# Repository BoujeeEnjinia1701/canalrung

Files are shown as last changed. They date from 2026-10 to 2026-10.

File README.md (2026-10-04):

# CanalRung

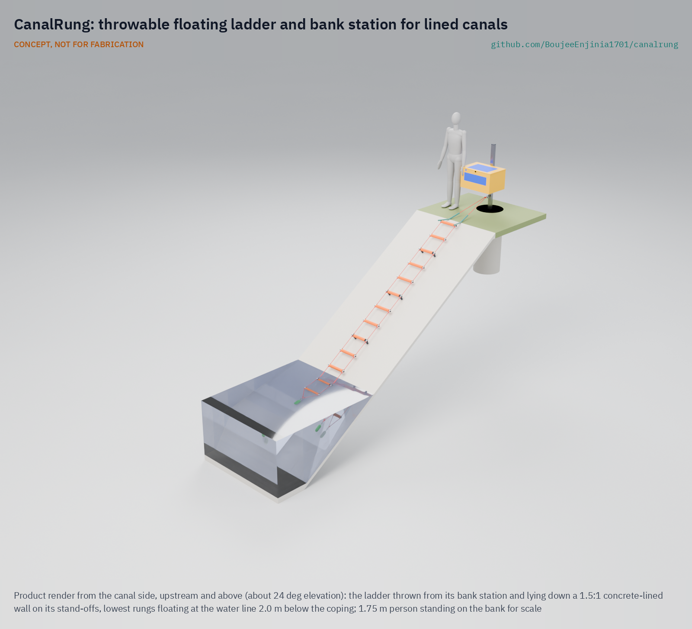
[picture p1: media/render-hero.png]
CanalRung: throwable floating ladder thrown from its bank station down a lined canal wall


     

**Area:** Situational field hardware · **TRL:** 3 of 9 (proof of concept on paper; constructable design) · **Value-engineering target:** USD 500; estimated cost USD 605.20 (USD 105.20 over the target) · **Difficulty:** 2 of 5

CONCEPT, NOT FOR FABRICATION. A research prototype design published as an open engineering reference, not certified life-saving equipment.

Gives someone in a steep canal a throwable floating ladder to climb out.

## Concept rationale

Most canal drownings are not about swimming. The water moves fast, the lined sides are steep and slick, and a person who falls in has nothing to hold. A ladder they can grab turns a steep wall into a way out. CanalRung is a ladder that a bystander can throw: rungs on rope, a weighted throw end so it drops down the wall, and a top that anchors on the bank. The person in the water grabs a rung and climbs out while the bystander stays on land.

Fixed escape ladders exist, but they are placed at intervals along the canal and may not be near the person in the water. A throwable ladder kept at farms, pump houses, schools and crossings brings the escape route to wherever someone falls in. Keeping it open and cheap, with a value-engineering target of USD 500 for a whole station, lets irrigation districts, farm groups and village committees build and place many.

## Burning platform

Drowning killed about 300,000 people in 2021, and 9 in 10 of those deaths happened in low and middle income countries ([WHO, 2024](https://www.who.int/news/item/13-12-2024-drowning-deaths-decline-globally-but-the-most-vulnerable-remain-at-risk)). Canals carry their share. The US Bureau of Reclamation counted 152 public drownings in its canals over 1964 to 1968, 40 per cent of them children under 11, and found hard-surface lined canals the most hazardous because of the difficulty in escaping from them ([USBR REC-ERC-71-36](https://www.usbr.gov/tsc/techreferences/hydraulics_lab/pubs/REC/REC-ERC-71-36.pdf)).

The pattern holds today. In Grant County, Washington, canals typically claim 1 to 4 lives a year, and the sheriff's office warns that once someone falls in, self-rescue is usually impossible because of steep concrete banks coated with dust or algae ([Columbia Basin Herald, 2026](https://columbiabasinherald.com/news/2026/jun/03/placid-in-appearance-canals-can-be-a-deathtrap/)). In Punjab, India, private divers estimate more than 100 deaths a year in the Bhakra canal alone ([The Tribune](https://www.tribuneindia.com/news/punjab/amid-no-govt-support-private-divers-recover-bodies-from-bhakhra-canal/)). Would-be rescuers are at risk too: Washington State's FACE programme describes two orchard workers who drowned in a concrete canal when one fell in and the other tried to rescue him ([Washington L&I FACE, 2002](https://stacks.cdc.gov/view/cdc/228712/cdc_228712_DS1.pdf)).

## Where it could be used

### By industry

| Industry | Use |
| --- | --- |
| Irrigation districts and water utilities | Throwable ladders at pump houses, checks, crossings and maintenance roads |
| Agriculture | Kit at farms and orchards beside canals, for workers and families |
| Schools and community groups | Stations at canal-side paths and crossings used by children |
| Fire and rescue services | Low-cost reach and climb aid carried on first-response vehicles |
| Inland waterways and ports | Throwable climb-out aid for quays and locks without fixed ladders |

### By country or region

| Country or region | Why it matters there |
| --- | --- |
| United States, western irrigation states | Grant County, Washington, sees 1 to 4 canal deaths a year and officials say self-rescue from its concrete-lined canals is usually impossible ([Columbia Basin Herald, 2026](https://columbiabasinherald.com/news/2026/jun/03/placid-in-appearance-canals-can-be-a-deathtrap/)). |
| United States, All-American Canal (California) | More than 600 people have drowned in the canal since 1942, and its eastern side is a steep concrete layer that is nearly impossible to climb out of ([KPBS, 2022](https://www.kpbs.org/news/local/2022/02/08/officials-doing-little-as-more-migrants-drown-in-imperial-county-canal)). |
| India, Punjab | Divers recovered 167 bodies from the Bhakra canal around Patiala between January 2021 and August 2022 ([The Tribune](https://www.tribuneindia.com/news/punjab/amid-no-govt-support-private-divers-recover-bodies-from-bhakhra-canal/)). |
| Pakistan, Punjab | In August 2026, 15 people drowned when a loaded rickshaw fell into the Muzaffargarh canal near Kot Adu; 11 were rescued alive ([The Nation, 2026](https://www.nation.com.pk/18-Aug-2026/three-children-s-bodies-recovered-eight-days-muzaffargarh-canal-tragedy)). |
| Low and middle income countries | Nine in ten drowning deaths happen in low and middle income countries, and the WHO African Region has the highest drowning rate ([WHO, 2024](https://www.who.int/news/item/13-12-2024-drowning-deaths-decline-globally-but-the-most-vulnerable-remain-at-risk)). |

## What sparked the idea

On 11 June 2026 in Hialeah, Florida, a 68-year-old man slipped into a canal. His friend went into the water to pull him out but could not bring him to the edge, and the current carried him to the centre of the canal, where he drowned ([WSVN, 2026](https://wsvn.com/news/local/miami-dade/2-men-drown-in-hialeah-canal-after-1-falls-in-friend-tries-to-rescue-him/)). The friend did what most people do: go in. CanalRung starts from the idea that the bystander should be able to send a way out down the bank instead.

## Problem

People who fall into lined irrigation canals often cannot climb the steep, slick sides, and bystanders who go in after them often drown too. There is rarely anything at the bank that lets the person in the water climb out on their own.

Full problem statement: [docs/01-problem.md](docs/01-problem.md)

## Concept

A bank station (a galvanised post in a concrete footing, with a forged eye nut near its foot and a bright storage box) holds a rope ladder whose top is already linked to the eye nut. A bystander lifts the lid and throws the soft-weighted bottom end upstream; 13 floating aluminium rungs on two low-stretch ropes lie down the lined wall on stand-offs, and the person in the water grabs a rung and climbs out while the bystander stays on land.

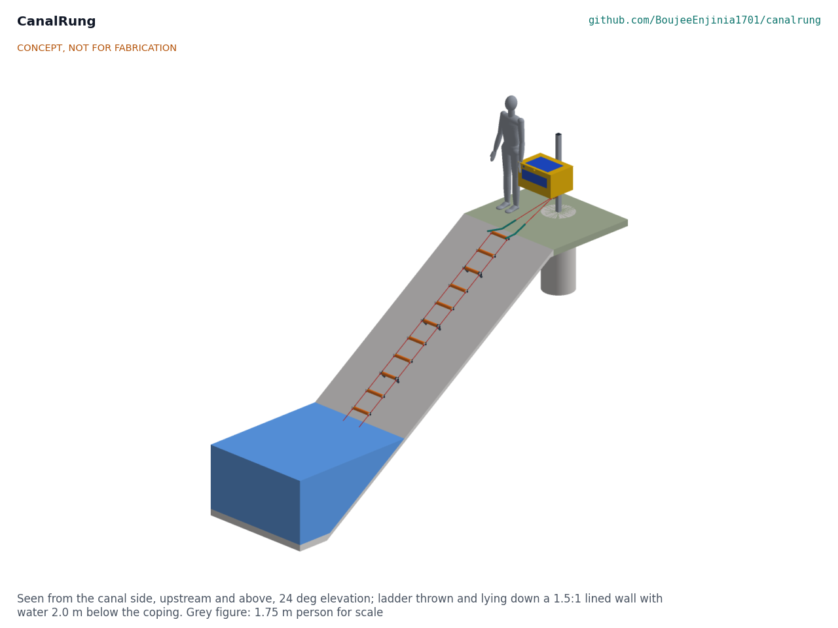
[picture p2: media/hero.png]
Concept render


Key numbers on paper (CNR-CAL-001): a 4.02 m rung section reaches the water 2.1 m down a 1.5:1 wall or 3.8 m down a vertical wall; every rung floats with 0.22 to 0.28 kg to spare; a rung under 1.5 kN reaches 0.56 of yield and the two 9 mm ropes hold 18.4 kN wet with their knots; the anchor, on a 500 x 1,200 mm footing at every site, holds 4.5 kN in drained or saturated soil. The ladder as thrown weighs 4.27 kg, inside its 4.5 kg target.

Design precis: [docs/02-concept.md](docs/02-concept.md) · Requirements: [docs/03-requirements.md](docs/03-requirements.md) · Calculations: [docs/04-calcs/01-sizing.md](docs/04-calcs/01-sizing.md) · Prototype build plan: [docs/05-build-plan.md](docs/05-build-plan.md) · Design decisions: [docs/06-design-decisions.md](docs/06-design-decisions.md) · General arrangement: [CNR-DWG-001](cad/drawings/CNR-DWG-001.pdf) · 3D viewer: [media/viewer.html](media/viewer.html)

## Key components

- Post, concrete footing, crush tube, M16 anchor bolt and forged eye nut
- Mounting plate, square U-bolts and a 70 L storage box with decals, tamper tag and rescue knife
- 13 aluminium rungs with foam float sleeves, nylon rope bushes and end caps
- HDPE wall stand-off blocks on rungs 3, 6, 9 and 12
- Two 9 mm EN 1891 type B kernmantle side ropes, a stopper knot under every rung end and a seizing over it
- Screw links, a soft 0.5 kg throw weight and edge protector sleeves

## Building the prototype

The prototype build plan ([docs/05-build-plan.md](docs/05-build-plan.md)) shows how to make each of the 23 components and put them together in 16 steps, with a making sketch for every made part and a picture for every joint and step. The station is cut and drilled steel and aluminium, a small concrete footing and a bought box; the ladder is cut and drilled aluminium tube, foam and plastic, threaded on two ropes with a knot under each rung end. It is a plan, not yet built: building and proof-loading it is TRL 4 work, and its safety stops come first.

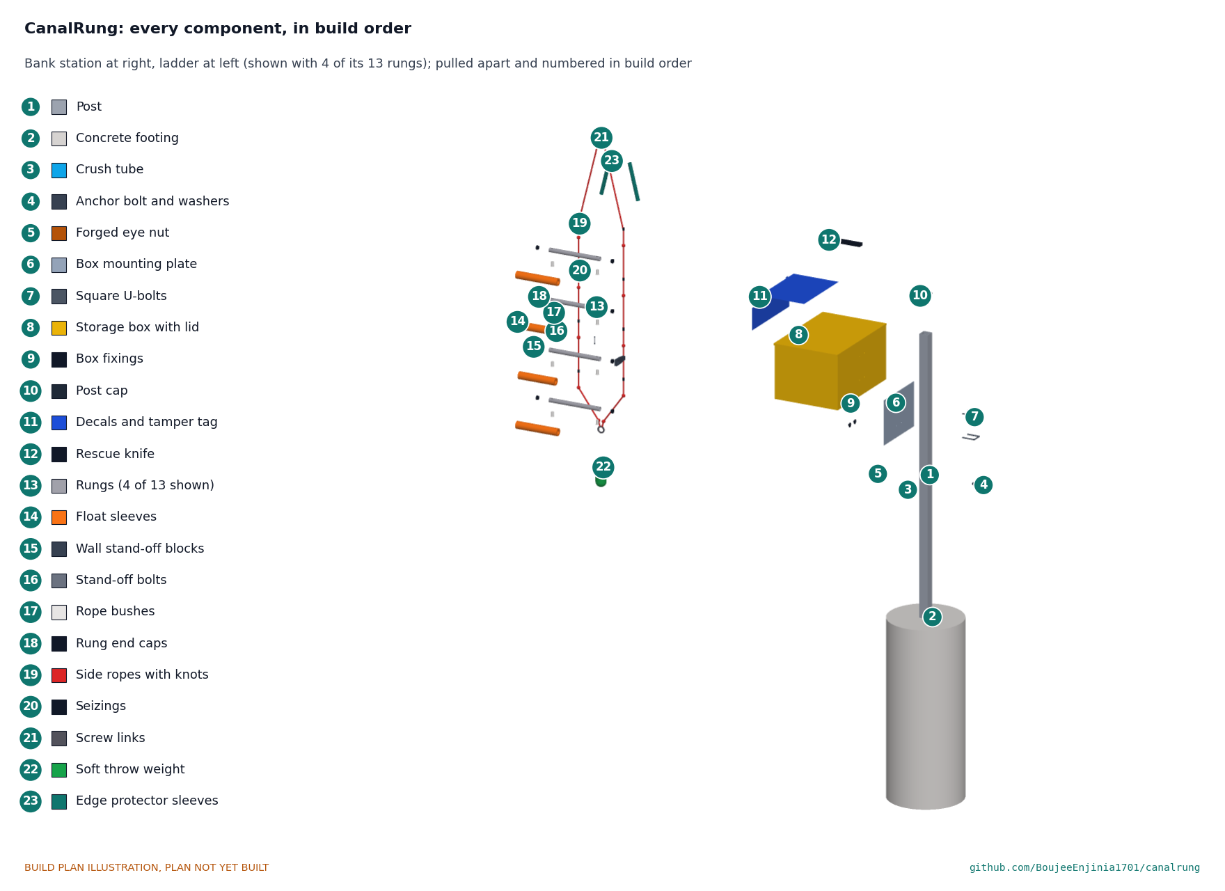
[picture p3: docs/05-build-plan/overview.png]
Every component in build order


## Safety

> Never enter the water to rescue someone. Throw, anchor and call the emergency number.
>
> Rope in moving water can trap a person; a blunt-tip rescue knife is kept in the box lid.
>
> No one climbs or tests the ladder until it has been proof-loaded (CNR-BLD-001, section 6).
>
> Safety-critical rescue and rope equipment. Published as an open engineering reference, never as certified life-saving equipment.
>
> The anchor must hold the full climbing load; a bystander holding the top by hand can be pulled in.
>
> It is not a flotation device or life jacket.
>
> Inspect ropes and rungs for UV and abrasion damage on a set schedule, and replace on any doubt.
>
> This design is published as an open engineering reference. It is not certified equipment.

## Repository layout

| Folder | Contents |
| --- | --- |
| `docs/` | Problem, concept, requirements, calculations and design decisions |
| `cad/src/` | build123d Python source, the source of truth for all geometry |
| `cad/step/`, `cad/stl/` | Exported models for FreeCAD, other CAD tools and printing |
| `cad/drawings/` | 2D sketches and dimensioned drawings |
| `bom/` | Bill of materials |
| `electronics/` | KiCad schematics and PCB layouts |
| `firmware/` | Microcontroller code |
| `media/` | Renders, perspectives and photos |
| `build-log/` | Dated prototyping notes |

## Documentation

Controlled documents follow the portfolio [documentation standard](.kit/STANDARDS.md). Each carries a document ID (CNR-PRC-001 for the precis), a version and a revision history. Branded PDFs are built with `python .kit/render.py` and attached to GitHub Releases when a document is tagged, for example `CNR-PRC-001/v1.0`.

## Credits

Designed by Amish Chadha at Design Molecule Labs. See [CONTRIBUTORS.md](CONTRIBUTORS.md) for roles. To cite this design, use [CITATION.cff](CITATION.cff) (GitHub shows it as "Cite this repository").

AI assistance (Claude) was used to accelerate prototype documentation and first-pass research. Design direction and all decisions are Amish Chadha's, recorded in this repository's decision records (`docs/decisions/`).

## Licenses

- **Hardware** (CAD, drawings, BOM, electronics): [CERN-OHL-S v2](LICENSE)
- **Software** (firmware, scripts, notebooks): [MIT](LICENSE-SOFTWARE)

A project of the [Design Molecule](https://designmolecule.com) lab.

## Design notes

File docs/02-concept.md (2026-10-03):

---
doc_id: CNR-PRC-001
title: CanalRung design precis
project: CanalRung
doc_type: Precis
version: "0.4"
status: Draft
date: '2026-10-03'
author: Amish Chadha
license: CERN-OHL-S-2.0
revisions:
- version: "0.1"
  date: '2026-09-30'
  author: Amish Chadha
  change: Initial scaffold
- version: "0.2"
  date: '2026-10-03'
  author: Amish Chadha
  change: "TRL 2: how it works, components, first-order numbers, key design choices decided under Amish's 2026-10-03 pre-approval (CNR-DDR-001), safety"
- version: "0.3"
  date: '2026-10-03'
  author: Amish Chadha
  change: "TRL 3: numbers from CNR-CAL-001; constructable design (CNR-DDR-002): rope-through-rung joint, bolted stand-offs, eye nut anchor with crush tube, box clamped by U-bolts, edge protectors, screw links"
- version: "0.4"
  date: '2026-10-03'
  author: Amish Chadha
  change: "Amish's requirement decisions of 2026-10-03 (CNR-DDR-003): 9 mm EN 1891 type B ropes; 500 x 1,200 mm footing and 2,300 mm post at every site; R2 restated to 4.5 kg"
---

# CanalRung design precis

Gives someone in a steep canal a throwable floating ladder to climb out.

## Summary

CanalRung is a bank station and a rope ladder. The station is a galvanised post set in a concrete footing beside the canal, with a forged eye nut near its foot and a bright storage box on it. The ladder lives in the box with its top already linked to the eye nut. A bystander lifts the lid, throws the soft-weighted bottom end upstream of the person in the water and lets the ladder pay out down the lined wall. Thirteen floating aluminium rungs on two low-stretch ropes lie down the wall on stand-offs, so the person can get a hand behind a rung and climb out while the bystander stays on land. On paper the design reaches the water on the design walls, every rung floats, the rungs and ropes carry a heavy climber with margin and the anchor holds 4.5 kN in drained soil. The ladder as thrown weighs 4.48 kg, over its 4.0 kg target, and the parts cost about USD 544 against a USD 500 value-engineering target.

> **Safety:** Never enter the water to rescue someone. Throw, anchor and call the emergency number. CanalRung is safety-critical rescue and rope equipment, published as an open engineering reference and never as certified life-saving equipment. It is not a flotation device or life jacket. Rope in moving water can trap a person; a blunt-tip rescue knife is kept in the box lid. The anchor must hold the full climbing load: never hold the top of the ladder by hand.

## How it works

1. **Stored ready.** The ladder sits folded in a 70 L box on the station post, rungs in three stacks with the throw weight on top. The top of the ladder is already clipped to the eye nut at the foot of the post by a screw link, and the two ropes run under the box and up into it through a notch in the front rim, so the lid closes on them.
2. **Thrown.** The bystander lifts the lid (no lock; a numbered tamper tag shows it has been used), takes the throw weight and the top of the folded ladder, and throws upstream of the person. The soft 0.5 kg weight carries the bottom end down the wall and into the water.
3. **Lying down the wall.** The ropes lift out of the notch and run from the eye nut straight to the canal edge, over the coping in two hook-and-loop edge protector sleeves, and down the wall. Rungs 3, 6, 9 and 12 carry HDPE stand-off blocks that hold the ladder 95 mm off the concrete, so there is 70 mm of hand room behind each float sleeve.
4. **Floating at the water line.** Each rung has a closed-cell foam float sleeve. The rungs that reach the water float, so the lowest rungs sit at the surface where a person can grab them, while the weight hangs 280 mm below the bottom rung and keeps that end from skating away on the current.
5. **Climbing out.** The person grabs a rung and climbs. Each rung rests on an overhand stopper knot under each end, so the climbing load goes from the rung into the knots, up the ropes, through the top link and eye nut into the post and its footing.

## Main components

*Table 1. Components, in build order; the numbers are the lines of `bom/bom.csv`.*

| # | Component | Role |
| --- | --- | --- |
| 1 | Post, galvanised 60 x 60 x 3 SHS, 2,300 long | Holds the box at a reachable height and carries the ladder anchor |
| 2 | Concrete footing, 500 dia x 1,200 deep, at every site | Holds the post against the anchor load in drained or saturated bank soil |
| 3 | Crush tube, 21.3 x 2.0, 57 long | Lets the anchor bolt be tightened without crushing the post |
| 4, 5 | M16 grade 8.8 anchor bolt and forged M16 eye nut | The ladder anchor, 250 mm above ground, loaded in line with its thread |
| 6, 7, 9 | Mounting plate, two square U-bolts, washers and nyloc nuts | Clamp the box to the post with no holes in the post |
| 8 | Storage box, 70 L, UV-stabilised, hinged lid, no lock | Keeps the ladder dry, dark and ready; drains through four holes |
| 10 to 12 | Post cap, decals and tamper tag, rescue knife | Weather, instructions ("do not enter the water"), use indicator, entanglement cutter |
| 13 | Rungs, 6061-T6 tube 28.6 x 1.65 x 360 (13) | Hand and foot holds at 335 mm pitch, 298 mm clear width |
| 14 | Float sleeves, closed-cell foam 50 OD (13) | Buoyancy and grip; high-visibility orange |
| 15, 16 | Stand-off blocks, HDPE (8), and M5 bolts | Hold the ladder 95 mm off the wall at rungs 3, 6, 9 and 12 |
| 17, 18 | Nylon rope bushes (26) and end caps (26) | Keep the rope off the aluminium hole edges; close the tube ends |
| 19, 20 | Side ropes, 9 mm EN 1891 type B (2 x 8.0 m), knots and seizings | Carry the climbing load; a knot under and a seizing over each rung end |
| 21 | Screw links, 10 mm (2) | Top: ropes to the eye nut; bottom: ropes to the throw weight |
| 22 | Soft throw weight, 0.5 kg steel shot pouch | Carries the bottom end down and into the water; cannot injure |
| 23 | Edge protector sleeves (2) | Keep the ropes off the concrete edge of the coping |

Figure 1. CanalRung thrown from its station and lying down a 1.5:1 lined wall

*Figure 1. Concept render from the constructable model, seen from the canal side.*

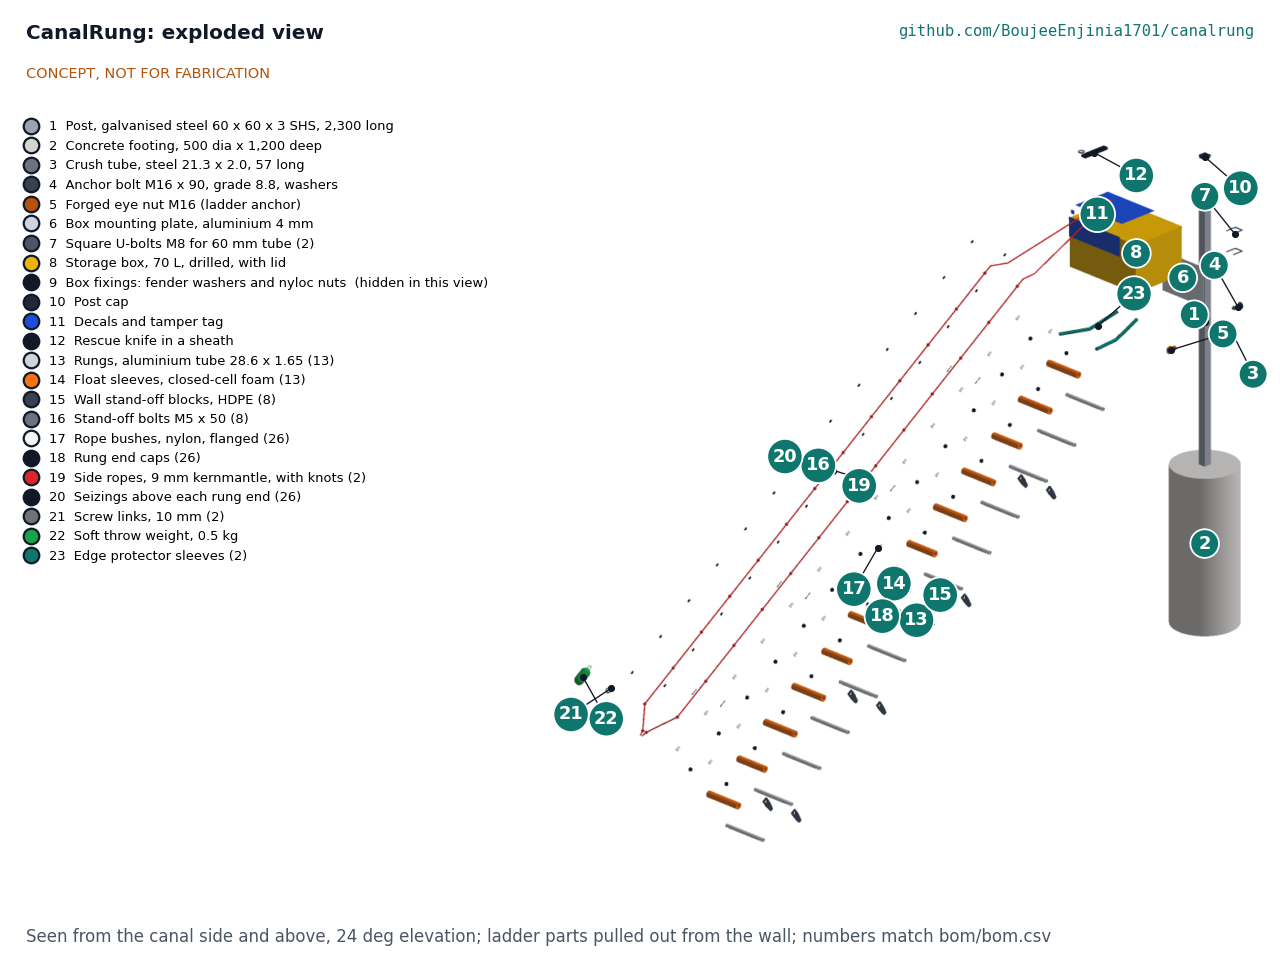
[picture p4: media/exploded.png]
Figure 2. Exploded view


*Figure 2. Exploded view; numbers match the bill of materials.*

## Numbers from the TRL 3 calculations

All figures are from CNR-CAL-001 (`docs/04-calcs/sizing.py`), with the assumptions stated there.

*Table 2. Key figures.*

| Quantity | Value | Basis |
| --- | --- | --- |
| Rung section | 4,020 mm, 13 rungs at 335 mm | [A1] |
| Reach | Two rungs in the water on a 1.5:1 slope with water 2.0 m down; works to 2.1 m on that slope and to 3.8 m on a vertical wall | [A3] to [A5] |
| Hand room and width | 70 mm behind the float sleeve at a stand-off; 298 mm clear between bushes | [A6] |
| Ladder as thrown | 4.27 kg (target 4.5 kg, restated by Amish on 2026-10-03) | [B3] |
| Spare buoyancy | 0.28 kg per plain rung, 0.22 kg per stand-off rung; bottom three rungs carry the throw weight 1.75 times over | [C1], [C2] |
| Rung stress at 1.5 kN | 135 MPa, 0.56 of the 240 MPa minimum yield | [D1] |
| Rope strength | 18.4 kN for both 9 mm ropes, wet, with stopper knots; 4.08 times the 4.5 kN target | [E1] |
| Anchor load in use | 1.47 kN for a 100 kg climber with a 1.5 dynamic factor; 2.32 kN upper bound with full current drag | [F1] to [F4] |
| Anchor elements | Eye nut 1.53 times the target; post at 0.39 of yield; standard 500 x 1,200 mm footing 3.58 times in drained soil and 1.59 in saturated soil | [G1] to [G5] |
| Deploy time | About 15 s (estimate) | [H1] |
| Cost | Value-engineering target: USD 500. Estimated cost of the constructable design: USD 605.20 (USD 105.20 over the target) | [I1] |

## Key design choices

Every choice below was decided on 2026-10-03 under Amish's pre-approval of the batch ("I pre-approve the batch runs along with any recommendations you come up with"); the full reasoning is in CNR-DDR-001 and CNR-DDR-002.

1. **A fixed station is the anchor.** The scaffold listed a ground stake, a post loop or a cross bar. A bystander cannot drive a stake that holds 4.5 kN in 30 s, so the post itself, set in concrete, carries the anchor, and the ladder top is linked to it before any emergency. A portable anchor is left for a later vehicle kit.
2. **Strong rungs over light rungs.** 28.6 x 1.65 mm 6061-T6 tube keeps the rung at 0.56 of yield; the lighter 25.4 mm tube would save 0.20 kg but reach 0.73. Safety first; the 4.0 kg mass target could not be met with these rungs, so Amish restated R2 to 4.5 kg on 2026-10-03 after the ropes were downsized to 9 mm (CNR-DDR-003).
3. **Knots carry the rungs.** Each rope runs through a nylon bush in each rung end; an overhand stopper knot under the bush carries the load and a twine seizing over it stops the rung floating up. This is the classic rope ladder joint, needs no special tools and can be inspected by eye. The 9 mm EN 1891 type B rope is tested with knotted terminations (at least 12 kN with figure-eight knots), so its knotted strength is known.
4. **Weighted and floating.** The soft weight sinks and the rungs float, which answers the scaffold's open question: the bottom end goes down and stays put while the lowest rungs sit at the surface.
5. **Stand-offs on every third rung.** Four stand-off rungs keep the taut ladder off the wall along its length at a cost of 0.42 kg; more would add mass, fewer would let it lie on the concrete between them.
6. **No throw line in the first prototype.** A second line adds tangling and an entanglement hazard for the person in the water; it can be tried after the throw trials.
7. **No lock on the box.** A tamper tag, signage and inspection instead.

## Patent design-arounds

From the preliminary patent, trademark and prior-art screen (not legal advice):

- No elastic self-stowing mechanism, to stay clear of the patented Rapid Rung swim ladder. The constructable design keeps to this: the ladder folds by hand into a box.
- Find and read the Rapid Rung patent number before public release (an action in the design decisions register, CNR-DEC-001).
- Build on expired buoyant ladder prior art such as US3411166A and US4989691A, and on the long-standing rope ladder construction (rungs on knots), which is public domain.

## Shared blocks

- CalRig proof-load rig, for the rope, rung and anchor proof loads at TRL 4 (a candidate shared block, not yet agreed).
- A boarding step for the LaneSkiff flood rescue skiff was proposed at TRL 1; it is outside this repository's scope and is recorded as a possible later use of the rung and rope joint only (CNR-DDR-001, D12).

## Safety

> **Safety:** CanalRung is safety-critical rescue and rope equipment, published as an open engineering reference and never as certified life-saving equipment. Never enter the water to rescue someone: throw, anchor and call the emergency number. The anchor must hold the full climbing load; a bystander holding the top by hand can be pulled in, which is why the top is linked to the post before any emergency. The ladder is not a flotation device or life jacket. Rope in moving water can trap a person or a limb: keep the knife in the lid and cut, do not pull, if anyone is caught. Inspect ropes, knots, seizings, bushes and the eye nut on a set schedule and after every use, and replace on any doubt. The footing must suit the soil at the site; on wet or soft banks use the larger footing. Building and testing the prototype is TRL 4 work with its own safety stops (CNR-BLD-001, section 6).

## Open decisions

None. All decisions were made under Amish's 2026-10-03 pre-approval; see the design decisions register CNR-DEC-001 (`docs/06-design-decisions.md`), which also lists the facts to confirm when parts are bought.

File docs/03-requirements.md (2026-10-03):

---
doc_id: CNR-REQ-001
title: CanalRung requirements
project: CanalRung
doc_type: Requirements
version: "0.4"
status: Draft
date: '2026-10-03'
author: Amish Chadha
license: CERN-OHL-S-2.0
revisions:
- version: "0.1"
  date: '2026-09-30'
  author: Amish Chadha
  change: Initial scaffold
- version: "0.2"
  date: '2026-10-03'
  author: Amish Chadha
  change: "TRL 2: measurable targets; R1 restated for a stated design envelope; R4 and R6 given margins; R6 restated for the fixed station anchor; R10 added (nothing thrown can hurt the person in the water); decided under Amish's 2026-10-03 pre-approval (CNR-DDR-001)"
- version: "0.3"
  date: '2026-10-03'
  author: Amish Chadha
  change: "TRL 3: status of every requirement from CNR-CAL-001 on the constructable design (CNR-DDR-002); R2 not met on mass; R9 reported against the value-engineering target"
- version: "0.4"
  date: '2026-10-03'
  author: Amish Chadha
  change: "Amish's requirement decisions of 2026-10-03 (4A and 9A, CNR-DDR-003): R2 mass target restated to 4.5 kg; R6 restated for the 500 x 1,200 mm footing as the standard at every site, in drained or saturated soil; R4 and R9 results updated for the 9 mm ropes and larger footing"
---

# CanalRung requirements

CanalRung meets nine of its ten requirements on paper or by design at TRL 3 and is over its value-engineering target on the tenth (R9). On 2026-10-03 Amish decided "1A 2A 3A 4A 5A 6A 7A 8A 9A 10A 11A": for CanalRung, 4A (smaller ropes, and R2 restated to 4.5 kg if the ladder still exceeds 4.0 kg) and 9A (the 500 x 1,200 mm footing standard at every site). Four requirements also need trials with people before they can be closed (R2 throw accuracy, R5 climb time, R7 deploy time, R8 ageing); those are TRL 4 work. Status comes from the calculation note CNR-CAL-001; the tag in brackets is the line of `docs/04-calcs/sizing.py` that carries the figure.

> **Safety:** CanalRung is safety-critical rescue and rope equipment. These requirements describe a research prototype, published as an open engineering reference and never as certified life-saving equipment. Meeting them on paper does not make the ladder safe to use; only proof loads, tank trials under lifeguard supervision and field trials can show that. Never enter the water to rescue someone: throw, anchor and call the emergency number.

## Design envelope

The first version is sized for lined canals where the water is up to 2.0 m below the coping on a 1.5:1 (horizontal to vertical) side slope, or up to 3.0 m below the coping on a vertical wall, with surface currents up to 2.0 m/s and water from 5 to 30 °C. The design case in the model is the 1.5:1 slope with the water 2.0 m below the coping. Deeper slopes need a longer ladder (a later variant, CNR-DDR-001, D1).

*Table 1. Requirements and status at TRL 3.*

| ID | Requirement | Target | Verification | Status at TRL 3 |
| --- | --- | --- | --- | --- |
| R1 | Reach the water from the bank | Rung section at least 4.0 m; at least two rungs at or below the water line on the design walls (1.5:1 slope to 2.0 m, vertical wall to 3.0 m) | Calculation [A1] to [A5]; deploy on a test wall at TRL 4 | Met on paper: 4,020 mm; two rungs in the water on the design slope and four on a 3.0 m vertical wall; works on 1.5:1 slopes to 2.1 m and vertical walls to 3.8 m |
| R2 | Throwable by one adult | Ladder as thrown (everything that leaves the box) at most 4.5 kg (9.9 lb), restated by Amish on 2026-10-03 from 4.0 kg; 8 of 10 untrained adults land the throw weight within 1 m of a target 3 m upstream | Weigh; throw trials with volunteers | Met on paper on mass: 4.27 kg [B3], 0.23 kg inside; throw accuracy needs trials |
| R3 | Rungs float at the water line | Every rung floats with at least 0.15 kg to spare, with its share of rope; the bottom three rungs carry the throw weight with a factor of at least 1.5 | Calculation [C1] to [C3]; tank test | Met on paper: 0.27 kg (plain) and 0.22 kg (stand-off) per rung; factor 1.73 |
| R4 | Carry a climbing adult | Each rung takes 1.5 kN at mid-span at no more than two thirds of yield; the two side ropes with their knots, wet, hold at least four times 4.5 kN (18 kN) | Calculation [D1], [E1]; proof-load test (TRL 4) | Met on paper: rung at 0.56 of yield; 9 mm ropes 18.4 kN, 4.08 times 4.5 kN |
| R5 | Climbable on a flat wall | Clear width at least 280 mm; rung pitch 300 to 350 mm; at least 60 mm of hand room behind the rung at the stand-offs; an adult volunteer climbs out of a 1.5 m deep test tank with a smooth vertical wall in under 60 s | Geometry [A6]; supervised tank trials with lifeguards | Geometry met by design (298 mm, 335 mm, 70 mm); climb time needs trials |
| R6 | Anchor holds | Station anchor (eye nut, bolt, post and the standard 500 x 1,200 mm footing used at every site) holds 4.5 kN with a factor of at least 1.5 on each element, in drained or saturated granular bank soil (restated by Amish on 2026-10-03) | Calculation [G1] to [G6]; pull test on site | Met on paper: eye nut 1.53; footing 3.58 drained, 1.59 saturated |
| R7 | Deploy quickly | Lid open to ladder in the water in under 30 s, using only the pictogram on the lid | Timed trials with untrained volunteers | Not verifiable at TRL 3; estimate 15 s [H1] |
| R8 | Survive outdoor storage | Ropes and rungs keep at least 80 % of strength after the equivalent of 2 years of outdoor exposure | Accelerated UV ageing and pull test | Met by design (stored in an opaque UV-stabilised box) [H2]; to confirm by test |
| R9 | Value for money | Parts cost reported against the value-engineering target of USD 500, including the post, footing and box | Costed bill of materials [I1] | Value-engineering target: USD 500. Estimated cost of the constructable design: USD 605.20 (USD 105.20 over the target) |
| R10 | Nothing thrown can hurt the person in the water | Soft throw weight; no exposed sharp edges or tube ends; a blunt-tip knife at the station to cut rope if anyone is caught | Inspection | Met by design [H3] |

## Requirements not met or at risk

- **R2 (restated, now met on mass):** with 9 mm ropes the ladder as thrown weighs 4.27 kg, still 0.27 kg over the earlier 4.0 kg, so the target was restated to 4.5 kg under Amish's fallback in decision 4A (CNR-DDR-003). The stronger rungs were kept. Whether 4.3 kg is easy to throw is a question for the TRL 4 throw trials.
- **R4 (thin margin on the ropes):** the 9 mm EN 1891 type B ropes hold 18.4 kN wet with knots, 4.08 times 4.5 kN, just over the four times R4 asks for and above Amish's floor of three times. The bought rope must declare at least 18 kN.
- **R6 (soil outside the screening values):** the standard footing holds with factors of 3.58 in drained and 1.59 in saturated granular soil. Soft clay or peat banks need a site pull test.
- **R9 (over the target):** the larger standard footing adds USD 65.00 of concrete; the estimate is USD 105.20 over the value-engineering target.

## Assumptions

- Many canal falls happen near places where a station can be placed: crossings, pump houses, paths and farms.
- A person in cold water can grip a rung long enough to climb if the rung is within reach.
- Throwing upstream and letting the current carry the ladder is easier for a bystander than throwing to the person.
- Irrigation districts would allow stations on their banks.
- The design climber is 100 kg with a dynamic factor of 1.5 (1.47 kN); the 4.5 kN anchor target is about three times that.

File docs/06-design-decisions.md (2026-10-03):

---
doc_id: CNR-DEC-001
title: CanalRung design decisions register
project: CanalRung
doc_type: Design decisions register
version: "0.2"
status: Draft
date: '2026-10-03'
author: Amish Chadha
license: CERN-OHL-S-2.0
revisions:
- version: "0.1"
  date: '2026-10-03'
  author: Amish Chadha
  change: "Register opened at TRL 3; every decision made under Amish's 2026-10-03 pre-approval"
- version: "0.2"
  date: '2026-10-03'
  author: Amish Chadha
  change: "Amish's requirement decisions 4A and 9A of 2026-10-03 recorded (CNR-DDR-003): 9 mm ropes with R2 restated to 4.5 kg; the 500 x 1,200 mm footing standard at every site"
---

# CanalRung design decisions register

Every design decision still to be made, and every decision made, in one place. Each decision is argued in full in its decision record under `docs/decisions/`; this register is the index Amish works from. The build plan (`docs/05-build-plan.md`) describes the design as it stands and does not list open decisions.

> **Safety:** CanalRung is safety-critical rescue and rope equipment. Every decision below that touches safety took the conservative option, and the decision records say what evidence would relax it. Nothing here makes the ladder safe to use without proof loads and supervised trials (TRL 4). Never enter the water to rescue someone.

## Open decisions

None. All decisions were made under Amish's 2026-10-03 pre-approval, and requirement decisions 4A and 9A were decided by Amish on 2026-10-03 (below).

## To confirm when parts are bought

| # | What to confirm | Why it matters | Source |
| --- | --- | --- | --- |
| 1 | The storage box takes a 370 mm rung across its inside depth (about 440 mm), and its back wall is flat where the plate sits | The folded ladder and the U-bolt clamp depend on it; choose a different box if not | CNR-DDR-002, P6 |
| 2 | The eye nut is forged and marked with a working load limit of at least 700 kg in line with its thread | The anchor factor of 1.53 rests on it | CNR-CAL-001, G1 |
| 3 | The screw links are marked with a working load limit of at least 1,000 kg and are long enough (about 60 mm inside) to pass round the eye nut's ring with both rope loops in | The top joint needs room for the ring and two loops | CNR-DDR-002, P7 |
| 4 | The rope is EN 1891 type B, 9 mm, with a declared breaking strength of at least 18 kN and about 55 g/m; polyester if available | The rope strength of 18.4 kN wet with knots (4.08 times 4.5 kN, R4) and the 4.27 kg ladder mass rest on it | CNR-CAL-001, E1 and B1; CNR-DDR-003 |
| 5 | The foam tube is closed-cell (a cut end takes up no water) and grips 28.6 mm tube | Buoyancy and the sleeve's fit | CNR-CAL-001, C1 |
| 6 | The nylon bushes are 12 mm bore, 16 mm outside, with a 22 mm flange, and the 9 mm rope passes freely while its overhand knot cannot pull through | The rope and knot seat | CNR-DDR-002, P1 |
| 7 | The bank soil at the first site is granular (sand or gravel), drained or saturated, and not soft clay or peat | The standard 500 x 1,200 mm footing is checked for granular soil only; clay or peat needs a site pull test | CNR-CAL-001, G4 and G5; CNR-DDR-003 |
| 8 | The Rapid Rung patent number, read before public release | Confirms the no-elastic-stowing design-around | CNR-PRC-001 |

## Value engineering

Value-engineering target: USD 500 (a hypothetical control target, not a limit). Estimated cost of the constructable design: USD 605.20 (USD 105.20 over the target). Main cost drivers and savings worth trying:

- The station costs USD 358.80 and the ladder USD 246.40. The largest lines are the concrete footing (USD 143, the 500 x 1,200 mm footing now standard at every site), the 13 aluminium rungs (USD 72.80), the post (USD 52.60), the storage box (USD 45), the ropes (USD 32) and the edge protectors (USD 30).
- Savings worth trying: ready-mix delivered for several stations at once instead of bagged premix; buying rope by the 50 m reel; a post and footing shared with an existing district marker post or fence line; sewn canvas edge protectors instead of bought ones; rungs cut from 6 m tube lengths.
- Mass: the ladder as thrown is 4.27 kg, inside the 4.5 kg of R2 as restated on 2026-10-03. Worth trying at TRL 4 if the throw trials ask for less: stand-off blocks with a lightening hole (about 0.10 kg), a 0.4 kg throw weight (0.10 kg). Lighter rungs were rejected on strength (CNR-DDR-001, D3), and ropes below 9 mm would fall under Amish's three-times floor (CNR-DDR-003).

## Decisions made

Decided by Amish under his pre-approval of 2026-10-03, except the last two rows, which he decided directly on 2026-10-03: "start with the first 14 repos from the list of 29 projects. I pre-approve the batch runs along with any recommendations you come up with. I also accept any cost overruns or variations from the assumed scope cost."

| Date | Decision | Decided by | Record |
| --- | --- | --- | --- |
| 2026-10-03 | Design envelope: water to 2.0 m below the coping on 1.5:1 slopes and to 3.0 m on vertical walls; currents to 2.0 m/s; a longer variant later | Amish, pre-approval quoted above | CNR-DDR-001, D1 |
| 2026-10-03 | The station post is the anchor: forged M16 eye nut on an M16 bolt through the post, 250 mm above ground, ladder linked in advance | Amish, pre-approval quoted above | CNR-DDR-001, D2 |
| 2026-10-03 | Rungs of 28.6 x 1.65 mm 6061-T6 tube (strength before mass) | Amish, pre-approval quoted above | CNR-DDR-001, D3 |
| 2026-10-03 | Ropes of 10.5 mm EN 1891 type A kernmantle, polyester preferred, through nylon bushes; overhand knot under and seizing over each rung end | Amish, pre-approval quoted above | CNR-DDR-001, D4 |
| 2026-10-03 | Stand-off blocks on rungs 3, 6, 9 and 12, 95 mm off the wall | Amish, pre-approval quoted above | CNR-DDR-001, D5 |
| 2026-10-03 | Soft 0.5 kg throw weight 280 mm below the bottom rung, rungs floating | Amish, pre-approval quoted above | CNR-DDR-001, D6 |
| 2026-10-03 | No throw line on the first prototype | Amish, pre-approval quoted above | CNR-DDR-001, D7 |
| 2026-10-03 | Bought 70 L UV-stabilised box clamped to the post, no lock, drain holes, rope notch, rescue knife | Amish, pre-approval quoted above | CNR-DDR-001, D8 and D11 |
| 2026-10-03 | Load standard: EN 1891 rope; rung and anchor targets of CNR-REQ-001, proof-loaded with CalRig at TRL 4; no certification claimed | Amish, pre-approval quoted above | CNR-DDR-001, D9 and D12 |
| 2026-10-03 | Keep the stronger rung and report R2 (mass) as not met | Amish, pre-approval quoted above | CNR-DDR-001, D10 |
| 2026-10-03 | First candidates to approach: Kittitas Reclamation District (co-design) and Water Safety Council of Fresno County (water safety); not contacted, not agreed | Amish, pre-approval quoted above | CNR-DDR-001, D13 |
| 2026-10-03 | Pitch, problem and the USD 500 value-engineering target unchanged; the USD 43.60 overrun accepted | Amish, pre-approval quoted above | CNR-DDR-001, D14 |
| 2026-10-03 | Design for construction: rope-through-rung joint with bushes, knots and seizings; bolted stand-off blocks; foam sleeve lengths; end caps; eye nut with crush tube; box on a plate with U-bolts; rope notch and drain holes; screw links; edge protectors; footing sizes | Amish, pre-approval quoted above | CNR-DDR-002 |
| 2026-10-03 | Saturated or soft banks get a 500 x 1,200 mm footing and a 2,300 mm post (conservative; a site pull test could relax it) | Amish, pre-approval quoted above | CNR-DDR-002, P11 |
| 2026-10-03 | Appearance model and render scenes as modelled, with no appearance deviations from the model | Amish, pre-approval quoted above | `docs/REVIEW.md` |
| 2026-10-03 | R2 (4A): side ropes downsized to 9 mm EN 1891 type B (18.4 kN wet with knots, 4.08 times 4.5 kN, above the three-times floor); stronger rungs kept; the ladder still exceeds 4.0 kg (4.27 kg), so R2 restated to 4.5 kg. Supersedes the 10.5 mm rope of D4 and the "R2 not met" of D10 | Amish, 2026-10-03: "1A 2A 3A 4A 5A 6A 7A 8A 9A 10A 11A" | CNR-DDR-003 |
| 2026-10-03 | R6 (9A): the 500 x 1,200 mm footing with a 2,300 mm post is the standard footing at every site (factor 3.58 drained, 1.59 saturated); R6 restated for drained or saturated soil. Supersedes the two footing sizes of P11 | Amish, 2026-10-03: "1A 2A 3A 4A 5A 6A 7A 8A 9A 10A 11A" | CNR-DDR-003 |

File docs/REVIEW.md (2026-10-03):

# Review note: CanalRung

## Session 2026-09-30: scaffolded

### What was done

- Repository created from kit 1.6.0 at TRL 1, target TRL 2.
- `docs/01-problem.md` (CNR-PRB-001 v0.1): problem with cited evidence, users, environment, constraints, prior work, open questions.
- `docs/02-concept.md` (CNR-PRC-001 v0.1): how it works, components, patent design-arounds, shared blocks, safety.
- `docs/03-requirements.md` (CNR-REQ-001 v0.1): 9 proposed requirements.
- `README.md` with concept rationale, burning platform, where it could be used, and what sparked the idea.

### Next

- Run `/populate` to bring the repo to a strong TRL 2 with concept media.

## Session 2026-10-03: TRL 2 (populate), kit 1.7.0

Run as the first half of `/to-trl3` under Amish's pre-approval of 2026-10-03: "start with the first 14 repos from the list of 29 projects. I pre-approve the batch runs along with any recommendations you come up with. I also accept any cost overruns or variations from the assumed scope cost."

### What was done

- Kit 1.7.0 installed (`.kit/`, `.claude/commands/`); root `CLAUDE.md` replaced by `.kit/CLAUDE.md`; `.kit/PHASE.yaml` as installed.
- CNR-PRB-001 v0.2: design envelope, open questions answered, first co-design candidates, safety section.
- CNR-REQ-001 v0.2: measurable targets; R1 restated for the design envelope, R6 for the fixed station anchor, R10 added.
- CNR-PRC-001 v0.2: how it works, components, first-order numbers, key design choices, safety.
- CNR-DDR-001 (`docs/decisions/0001-trl2-review-decisions.md`): items D1 to D14.
- Concept media from the model: `media/hero.png`, `media/exploded.png`, `media/concept-blueprint.png` and `.pdf` (CNR-DWG-010), `media/model.glb` (coarse mesh, about 4 MB) and `media/viewer.html`. No cutaway (the joints are shown cut open in the build plan) and no flow diagram (the station moves no energy or material).
- `bom/bom.csv`: every line priced.

### Results

- The concept reaches the water on the design walls, floats, and carries a heavy climber on paper; it is over its 4.0 kg mass target and its USD 500 value-engineering target (figures in the TRL 3 section below).

### Requirements not met

- R2 (mass). See the TRL 3 section.

### Decisions made under the pre-approval

D1 to D14 of CNR-DDR-001, all dated 2026-10-03 and decided by Amish under the quote above: design envelope; the station post as the anchor; 28.6 mm rungs; EN 1891 rope with knots and seizings; stand-offs on every third rung; soft weight with floating rungs; no throw line; bought box with no lock, tamper tag and knife; load standard; R2 reported as not met; candidates Kittitas Reclamation District and the Water Safety Council of Fresno County (not contacted); pitch, problem and target unchanged.

### Safety concerns

- Rescue and rope equipment: every document carries a safety section; the conservative option was taken at D2, D3, D6, D7 and D11.
- Entanglement in moving water: no throw line; a knife in the lid.

## Session 2026-10-03: TRL 3 (advance and build plan)

### What was done

- CNR-CAL-001 (`docs/04-calcs/01-sizing.md`, script `docs/04-calcs/sizing.py`, output `results.csv`): reach, mass, buoyancy, rung and rope strength, loads in use, anchor and footing, deployment, cost.
- Parametric model `cad/src/model.py` (build123d) with 245 constructability checks, all passing (`python cad/src/model.py --check`); STEP: `cad/step/canalrung-assembly.step`, `canalrung-ladder.step`, `post.step`, `mounting-plate.step`, `rung.step`, `standoff-block.step`, `crush-tube.step`; STL of the same five parts in `cad/stl/`.
- General arrangement CNR-DWG-001 Rev P2 (`cad/src/sheets.py`), at 1:50 on the design wall.
- Design made constructable (CNR-DDR-002, `docs/decisions/0002-design-for-construction.md`); `design_state: constructable`.
- Build plan pictures (`cad/src/build_plan_media.py`): overview, 9 making sketches (CNR-DWG-101 to 109), 8 joint close-ups, 16 step pictures in `docs/05-build-plan/`.
- CNR-BLD-001 (`docs/05-build-plan.md`) and CNR-DEC-001 (`docs/06-design-decisions.md`).
- Appearance model `cad/src/product_model.py` (`product_parts()`, `TITLE`, `RENDER_VIEWS` hero, exploded and detail) and render scenes exported to `/home/claude/renders/canalrung` for the photoreal renders on Amish's Mac. `media/render-hero.png`, cards and the social preview do not exist yet; the README already leads with `media/render-hero.png`.
- CNR-PRC-001 v0.3, CNR-REQ-001 v0.3, README (TRL 3, build plan section and links), `project.yaml` (trl 3, trl_target 3, evidence).

### Results

| Quantity | Value |
| --- | --- |
| Reach | 4,020 mm rung section; water to 2.1 m on a 1.5:1 wall, 3.8 m on a vertical wall |
| Ladder as thrown | 4.48 kg (target 4.0 kg) |
| Buoyancy | 0.27 kg (plain) and 0.22 kg (stand-off) spare per rung; bottom three rungs carry the weight 1.73 times |
| Rung at 1.5 kN | 0.56 of yield |
| Ropes, wet, with knots | 22.4 kN (5.0 times 4.5 kN) |
| Anchor | Eye nut 1.53, post 0.39 of yield, footing 1.92 (drained soil); saturated soil needs the 500 x 1,200 mm footing |
| Deploy time | About 15 s (estimate) |
| Cost | Value-engineering target: USD 500. Estimated cost of the constructable design: USD 543.60 (USD 43.60 over the target) |

### Requirements not met

- **R2, mass:** 4.48 kg against 4.0 kg. Kept deliberately (stronger rungs, D3 and D10); savings to try are in CNR-DEC-001.
- **R9:** over the value-engineering target by USD 43.60 (accepted under the pre-approval; `budget_usd` unchanged at 500).
- Not verifiable at TRL 3: R2 throw accuracy, R5 climb time, R7 deploy time, R8 ageing (TRL 4 trials).

### Decisions made under the pre-approval

- CNR-DDR-002, P1 to P12: rope-through-rung joint (bush, knot under, seizing over); bolted stand-off blocks; foam sleeve lengths; end caps; eye nut with a crush tube through a 21.5 mm back-wall hole; box on a plate with two U-bolts; rope notch and drain holes; screw links (sized to pass round the eye's ring); edge protectors; footing 400 x 1,000 mm, 500 x 1,200 mm on wet banks; rope cut length 8.0 m.
- Appearance model: no deviations from `model.py`; context only (bank, lining, water, mannequin, hand). Decided under the pre-approval and listed in CNR-DEC-001.
- Open decisions: none. Eight facts to confirm when parts are bought are in CNR-DEC-001.

### Build plan findings: design changes made for construction (2026-10-03)

1. Rung to rope: 16 mm holes, flanged nylon bushes, overhand knot under, seizing over (the concept had no joint).
2. Stand-off blocks: HDPE, locked by an M5 bolt through block and rung.
3. Float sleeves: two lengths (294 and 260 mm) to fit between bushes or blocks; this sets the build order (foam, blocks, bushes).
4. End caps with a short insert that clears the rope hole.
5. Anchor: forged eye nut on an M16 bolt; crush tube so the post walls do not crush; the first model's crush tube could not be fitted through the 17.5 mm bolt hole, so the back-wall hole is 21.5 mm.
6. Box: plate and U-bolts, legs through the box back wall; no holes in the post.
7. Rope notch and drain holes so the lid closes over the anchored ropes.
8. Screw links: the first model link clashed with the eye nut ring; enlarged to pass round it (6 mm clear).
9. Edge protectors on the top lead.
10. Footing sized; larger footing for saturated banks.
11. BOM renumbered in build order; parts added for each change.

### Safety concerns

- Life-critical load path (rungs, knots, ropes, links, eye nut, post, footing): proof loads with CalRig and supervised tank trials are needed before anyone climbs; the build plan's safety stops say so.
- Footing on wet canal banks: the standard footing has a factor of only 0.85 in saturated soil; the site soil must be checked.
- Entanglement: rope in moving water can trap a person; no throw line, knife in the lid.
- Working at the canal edge during installation: second person, life jacket, services located.
- Throw weight: soft pouch, thrown upstream, never at the person.

### Checks

- `python .kit/render.py` and `python .kit/render.py --check`: see the final run; the only expected warning is the missing storefront (`media/render-hero.png`, cards).
- `python .kit/drawing.py --check-text` on all sheets and the concept blueprint: no overlaps.

### Recommended next step

- Photoreal renders, cards and the social preview on Amish's Mac from `/home/claude/renders/canalrung`.
- TRL 4 (outside the current phase cap): build the prototype to CNR-BLD-001 and proof-load the rungs, ropes and anchor with CalRig before any tank trial.

## 2026-10-03: photoreal renders

Rendered with Blender Cycles on Amish's Mac from `cad/src/product_model.py`; captioned with `.kit/photo_caption.py`; `media/card.png` and `media/social-preview.png` made with `.kit/cards.py`. Views: hero, exploded, detail. image_qc passes and `render.py --check` has no FAIL.

## 2026-10-03: Amish's requirement decisions carried out

Amish chose option A on every requirement decision put to him on 2026-10-03: "1A 2A 3A 4A 5A 6A 7A 8A 9A 10A 11A". For CanalRung that is 4A (R2) and 9A (R6). Recorded in CNR-DDR-003 (`docs/decisions/0003-lighter-ropes-and-standard-footing.md`) and in the register CNR-DEC-001 v0.2.

### Changes made

- **4A, ropes (R2):** side ropes downsized from 10.5 mm EN 1891 type A to 9 mm EN 1891 type B (at least 18 kN declared, about 55 g/m); stronger rungs kept. Model `rope_d` 9.0 and knot 23 mm across; 26 new checks that the rope runs at least 1 mm clear of every bush bore. The ladder still exceeds 4.0 kg, so R2 is restated to 4.5 kg (Amish's fallback in 4A).
- **9A, footing (R6):** the 500 x 1,200 mm footing with a 2,300 mm post (1,100 mm in the concrete, bolt holes 1,350 mm from the bottom end) is the standard at every site; R6 restated for drained or saturated granular soil.
- Files: `cad/src/model.py` (271 of 271 checks pass; STEP and STL regenerated), `bom/bom.csv` (lines 1, 2 and 19 repriced; line 4's unquoted note fixed), CNR-CAL-001 v0.3 and `results.csv`, CNR-REQ-001 v0.4, CNR-PRC-001 v0.4, CNR-BLD-001 v0.2, CNR-DEC-001 v0.2, README, `project.yaml` (evidence).
- Pictures: general arrangement CNR-DWG-001 Rev P3; concept blueprint Rev P2, `media/hero.png`, `media/exploded.png`, `media/model.glb`; making sketches CNR-DWG-101 (post), 103 (footing) and 109 (rope); build plan overview, joints and steps regenerated (joint 1 and steps 1 and 2 show the new footing; rope pictures show the 9 mm rope).
- Appearance model `cad/src/product_model.py`: takes the new rope and footing from the model; exploded footing offset moved to suit the deeper footing. Render scenes re-exported to `/home/claude/renders/canalrung` (hero, exploded, detail). The photoreal renders on Amish's Mac need re-running to show the change.

### New results

| Requirement | Target | Before | After |
| --- | --- | --- | --- |
| R2, mass | At most 4.5 kg (restated from 4.0 kg) | 4.48 kg, not met | 4.27 kg, met on paper |
| R3, buoyancy | At least 0.15 kg per rung; weight factor at least 1.5 | 0.27 and 0.22 kg; 1.73 | 0.28 and 0.22 kg; 1.75 |
| R4, ropes | Wet with knots at least 4 times 4.5 kN (18 kN); Amish's floor 3 times | 22.4 kN, 5.0 times | 18.4 kN, 4.08 times |
| R6, footing | At least 1.5, drained or saturated soil | 1.92 drained, 0.85 saturated | 3.58 drained, 1.59 saturated |
| R9, cost | Reported against USD 500 | USD 543.60 | USD 605.20 |

Value-engineering target: USD 500. Estimated cost of the constructable design: USD 605.20 (USD 105.20 over the target). Footing +USD 65.00 (22 bags instead of 12 at USD 6.50), post +USD 4.60 (2.3 m pro rata), ropes save USD 8.00 (USD 2.00 a metre). Ladder as thrown 4.27 kg. `budget_usd` unchanged at 500.

### Decisions awaiting Amish

None. Nothing new needs Amish.

### Safety concerns

- The 9 mm rope meets the four-times rope factor of R4 only just (4.08). The bought rope must declare at least 18 kN, and the TRL 4 proof load must use wet, knotted rope.
- The standard footing is checked for granular soil only; soft clay or peat banks need a site pull test. About 550 kg of bagged concrete per footing is a manual handling load at the canal edge: use a second person or ready-mix.

## 2026-10-03: photoreal renders redone after Amish's requirement decisions

Rendered with Blender Cycles on Amish's Mac from `cad/src/product_model.py`; captioned with `.kit/photo_caption.py`; `media/card.png` and `media/social-preview.png` made with `.kit/cards.py`. Views: hero, exploded, detail. image_qc passes and `render.py --check` has no FAIL.

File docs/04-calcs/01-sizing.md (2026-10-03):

---
doc_id: CNR-CAL-001
title: CanalRung sizing calculations
project: CanalRung
doc_type: Calculation
version: "0.3"
status: Draft
date: '2026-10-03'
author: Amish Chadha
license: CERN-OHL-S-2.0
revisions:
- version: "0.1"
  date: '2026-10-03'
  author: Amish Chadha
  change: "First issue for TRL 3: reach, mass, buoyancy, rung and rope strength, loads in use, anchor and footing, deployment, cost"
- version: "0.2"
  date: '2026-10-03'
  author: Amish Chadha
  change: "Design for construction (CNR-DDR-002) applied: rope-through-rung joint, stand-off blocks, crush tube, rope cut length and mass, cost by build-order BOM"
- version: "0.3"
  date: '2026-10-03'
  author: Amish Chadha
  change: "Amish's requirement decisions of 2026-10-03 (4A, 9A; CNR-DDR-003): 9 mm EN 1891 type B ropes (E1, B1 to B3, C1 to C3); R2 measured against the restated 4.5 kg; the 500 x 1,200 mm footing standard at every site (G4 to G6); cost recomputed (I1, I2)"
---

# CanalRung sizing calculations

On paper the constructable CanalRung meets nine of its ten requirements and is over its value-engineering target on the tenth. The 4,020 mm rung section puts two rungs in the water on the design slope (1.5:1, water 2.0 m below the coping) and four on a 3.0 m vertical wall. Every rung floats with 0.22 to 0.28 kg to spare and the bottom three carry the soft throw weight 1.75 times over. A rung under a 1.5 kN point load reaches 0.56 of yield, and the two 9 mm ropes with their stopper knots hold 18.4 kN wet, 4.08 times the 4.5 kN target. The anchor holds 4.5 kN with factors of 1.53 (eye nut) and, for the 500 x 1,200 mm footing now standard at every site, 3.58 in drained soil and 1.59 in saturated soil. The ladder as thrown weighs 4.27 kg against the 4.5 kg target Amish restated on 2026-10-03 (R2 met on mass), and the parts cost USD 605.20 against the USD 500 value-engineering target. Every number below is printed by `docs/04-calcs/sizing.py`; the tag in brackets, for example [C2], is the line of that script's output that carries it.

> **Safety:** These are first-principles estimates for a paper proof of concept. They do not show that the ladder, its knots or the anchor are safe to use. Rope, knot, rung and anchor strengths must be proof-loaded (CalRig, TRL 4) and the climb, throw and deployment tried in a supervised test tank before any station is placed at a canal. Never enter the water to rescue someone. See CNR-PRC-001, Safety.

## Scope and method

The note checks every requirement in CNR-REQ-001 against the constructable design in `cad/src/model.py` (CNR-DDR-002). The script imports the model's parameters and builds the ladder once for part volumes, so the rungs, float sleeves, bushes and stand-off blocks used here are the ones in the STEP files and drawings. It reads `bom/bom.csv` and `budget_usd` in `project.yaml`. Run it from the repo root with `python docs/04-calcs/sizing.py`; it also writes `docs/04-calcs/results.csv`.

The design case is the station 1,000 mm back from the coping of a concrete-lined canal with a 1.5:1 (horizontal to vertical) side slope, the water 2.0 m below the coping and flowing at up to 2.0 m/s, and a 100 kg adult climbing out.

## Assumptions

*Table 1. Main assumptions.*

| Area | Assumption | Basis |
| --- | --- | --- |
| Climber | 100 kg, clothed and wet; dynamic factor 1.5 for grabbing and climbing (1.47 kN) | Screening value for a heavy adult |
| Rung | 6061-T6 drawn tube, 240 MPa minimum yield; load as a point at mid-span between the ropes (320 mm), simply supported | Conservative: hands and feet usually load nearer the ends |
| Rope | 9 mm EN 1891 type B, minimum breaking strength 18 kN, about 55 g/m; overhand stopper knot keeps 60 % (literature 55 to 65 %); wet 85 %; over a 10 mm unprotected edge 50 % | Typical published values; to be proof-loaded |
| Buoyancy | Fresh water 1,000 kg/m3; foam 33 kg/m3 closed cell; aluminium 2,700, nylon 1,140, HDPE 950, polyester 1,380 kg/m3; tube bore floods through the rope holes; rope share per rung includes 100 mm in each knot | Handbook densities |
| Current | 2.0 m/s surface current; person holding a rung, drag area 0.35 m2; rung drag coefficient 1.2 | Screening values |
| Anchor | Eye nut working load limit 700 kg in line with the thread (DIN 582 class, M16); 10 mm screw link 1,000 kg; M16 grade 8.8 proof 600 MPa on 157 mm2 | Catalogue classes; the bought parts must be marked |
| Post | S235 square hollow section 60 x 60 x 3; anchor 250 mm above ground | |
| Soil | Drained, medium dense granular bank: unit weight 18 kN/m3, friction angle 30°; saturated case 8 kN/m3 submerged | Screening values; to be confirmed on site |
| Footing | Short rigid pile in cohesionless soil (Broms), free head: ultimate lateral load 0.5 γ D L³ Kp / (e + L) | Broms (1964) |

## A. Reach and climbing geometry (R1, R5)

The rung section is 4,020 mm: 13 rungs at 335 mm pitch [A1]. On the 1.5:1 design slope (33.7°), rung 1 lies 150 mm down the wall from the coping [A2] and the bottom rung ends 2,313 mm below the coping, 313 mm below the water line, so rungs 12 and 13 are in the water and rung 11 is 59 mm above it [A3]. Because the rungs float, the ones that reach the water rise to the surface. The ladder still puts two rungs at or below the water line when the water is 2,127 mm below the coping [A4]. On a vertical wall with the water 3,000 mm down, the bottom rung is 1,170 mm under water with four rungs in it, and two rungs reach the water down to 3,835 mm [A5]. R1 is met for the stated design envelope; deeper sloped canals need the longer variant.

The clear width between the rope bushes is 298 mm, the pitch 335 mm, and at each stand-off rung the float sleeve stands 70 mm off the wall, room for a hand [A6]. R5's geometry is met by design; the climb time needs a tank trial.

## B. Mass (R2)

*Table 2. Mass of the ladder as thrown [B2].*

| Part | Mass (kg) |
| --- | --- |
| Rungs (13) | 1.715 |
| Float sleeves (13) | 0.161 |
| Rope bushes (26) | 0.091 |
| End caps (26) | 0.104 |
| Stand-off blocks (8) | 0.420 |
| Stand-off bolts (8) | 0.080 |
| Side ropes, 9 mm, 2 x 7.95 m at 55 g/m [B1] | 0.874 |
| Seizings | 0.020 |
| Screw links (2) | 0.120 |
| Throw weight with pouch | 0.530 |
| Edge protectors (2) | 0.160 |
| **Total** | **4.27** |

The ladder as thrown weighs 4.27 kg, 0.23 kg inside the 4.5 kg target of R2 [B3]. The 9 mm ropes save 0.21 kg against the 10.5 mm ropes they replace, which was not enough to reach the earlier 4.0 kg (still 0.27 kg over), so R2 was restated to 4.5 kg under Amish's fallback in decision 4A (CNR-DDR-003). **R2 is met on paper on mass**; throw accuracy needs trials. Rungs of 25.4 x 1.65 mm tube would save 0.20 kg [B4] but would take the rung past the stress limit (D2), so they were rejected.

## C. Buoyancy (R3)

A plain rung with its share of rope floats with 0.277 kg to spare and a stand-off rung with 0.221 kg, both above the 0.15 kg target [C1]. In water the throw weight weighs 0.442 kg; rungs 11, 12 and 13 together lift 0.775 kg, a factor of 1.75 against the 1.5 target [C2], so the weight hangs below the floating rungs instead of pulling them under. The whole ladder in water has 2.93 kg of spare lift [C3]. The lighter rope gives slightly more spare lift than before. **R3 is met on paper.** The tube bore is not counted: it floods through the rope holes.

## D. Rung strength (R4)

The 28.6 x 1.65 mm 6061-T6 tube has a section modulus of 890 mm3. A 1.5 kN point load at mid-span over the 320 mm between the ropes gives 120 N m and 135 MPa, 0.56 of the 240 MPa minimum yield, inside the two-thirds limit [D1]. The lighter 25.4 x 1.65 mm tube would reach 175 MPa, 0.73 of yield [D2].

Each rung end passes 750 N through the bush flange onto the knot; the nylon flange bears at about 17 MPa on a 2 mm contact band, against about 50 MPa for nylon to yield [D3]. With the whole climber on one stand-off rung on the 1.5:1 slope, each block pushes on the wall with 612 N; wall friction tries to turn the block round the rung with 17.4 N m, which puts 610 N across the M5 bolt, against about 6 kN for its two shear planes [D4].

## E. Ropes, knots and links (R4)

One 9 mm side rope with a stopper knot, wet, holds 18 x 0.6 x 0.85 = 9.18 kN; both ropes 18.4 kN, 4.08 times the 4.5 kN target [E1]. That is over the 18 kN (four times) that R4 asks for, and well over the floor of three times (13.5 kN) that Amish set for the smaller rope in decision 4A. The margin over R4 is thin, so the bought rope must carry a declared breaking strength of at least 18 kN and the proof load at TRL 4 must include knotted, wet rope. If a rope were pulled over an unprotected 10 mm coping edge as well, both ropes would still hold 9.2 kN [E2]; the edge protectors are there to keep the rope off that edge. The 10 mm screw links have a working load limit of 9.8 kN, 2.18 times the target [E3]. **R4 is met on paper.**

## F. Loads in use

The design climber with the dynamic factor loads the ladder with 1.47 kN [F1]. On the 1.5:1 slope the ropes carry only the part of that along the wall, 0.82 kN (wall friction ignored); on a vertical wall they carry all 1.47 kN [F2]. A person holding a rung in a 2.0 m/s current adds 700 N of drag, and three rungs in the water 106 N [F3]. Adding the vertical-wall climb and the full current drag together, which cannot both happen at full value, gives an upper bound of 2.32 kN on the anchor, inside the 4.5 kN target by a factor of 1.94 [F4].

## G. Anchor: eye nut, bolt, post and footing (R6)

*Table 3. Anchor elements against the 4.5 kN target.*

| Element | Capacity | Factor | Tag |
| --- | --- | --- | --- |
| Forged M16 eye nut, in line | 6.87 kN working load limit | 1.53 | [G1] |
| M16 grade 8.8 bolt | 94 kN proof load | 21 | [G2] |
| Post wall under the 50 mm washer | 66 kN punching | 15 | [G2] |
| Post, 60 x 60 x 3 at 250 mm | 91 MPa, 0.39 of yield | 2.6 | [G3] |
| Standard footing 500 x 1,200, drained soil | 16.1 kN ultimate | 3.58 | [G4] |
| Standard footing 500 x 1,200, saturated soil | 7.2 kN ultimate | 1.59 | [G5] |
| Earlier footing 400 x 1,000, saturated soil (for comparison) | 3.8 kN ultimate | 0.85 | [G5] |

Since Amish's decision 9A of 2026-10-03 the 500 x 1,200 mm footing, with a 2,300 mm post set 1,100 mm into it, is the standard footing at every site. It takes about 0.23 m3 of concrete, about 22 bags of 25 kg [G6]. **R6 is met on paper in drained and in saturated granular soil.** Soft clay or peat banks are outside these screening values and need a site pull test.

## H. Deployment, storage and safety (R7, R8, R10)

Lifting the lid (2 s), taking the throw weight and the top of the folded ladder (4 s), throwing upstream (4 s) and letting the ladder pay out (5 s) add up to about 15 s, inside the 30 s of R7; this is an estimate, and R7 can only be closed by timed trials [H1]. The ropes, rungs and foam live in an opaque UV-stabilised box and see daylight only when used or inspected, which is how R8 is met by design; an ageing test closes it [H2]. Nothing thrown is hard: the throw weight is a soft shot pouch, rung ends are capped and holes bushed, and a blunt-tip knife is kept in the lid (R10, met by design) [H3].

## I. Cost (R9)

Value-engineering target: USD 500. Estimated cost of the constructable design: USD 605.20 (USD 105.20 over the target) [I1]. The station (post, footing, anchor, box, decals, knife and consumables) is USD 358.80 and the ladder USD 246.40 [I2]. Against the previous estimate, the larger standard footing adds USD 65.00 (22 bags instead of 12 at USD 6.50), the longer post USD 4.60, and the 9 mm ropes save USD 8.00.

## Results against the requirements

*Table 4. Requirement status at TRL 3.*

| ID | Status | Figures |
| --- | --- | --- |
| R1 | Met on paper | 4,020 mm rung section; 1.5:1 slopes to 2.1 m, vertical walls to 3.8 m |
| R2 | Met on paper on mass (restated 2026-10-03); throw accuracy needs trials | 4.27 kg against 4.5 kg |
| R3 | Met on paper | 0.28 and 0.22 kg per rung; bottom three rungs 1.75 times the weight |
| R4 | Met on paper | Rung 0.56 of yield; ropes 18.4 kN wet with knots (4.08 times 4.5 kN) |
| R5 | Met by design; climb time needs trials | 298 mm clear, 335 mm pitch, 70 mm hand room |
| R6 | Met on paper in drained and saturated soil | Standard footing 3.58 drained, 1.59 saturated; eye nut 1.53 |
| R7 | Not verifiable at TRL 3 | Estimate 15 s |
| R8 | Met by design; to confirm by test | Stored in an opaque box |
| R9 | Over the value-engineering target | USD 605.20 against USD 500 |
| R10 | Met by design | Soft weight, capped ends, knife |

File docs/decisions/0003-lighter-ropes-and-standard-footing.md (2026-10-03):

---
doc_id: CNR-DDR-003
title: CanalRung lighter ropes and one standard footing
project: CanalRung
doc_type: Design decision record
version: "0.1"
status: Draft
date: '2026-10-03'
author: Amish Chadha
license: CERN-OHL-S-2.0
revisions:
- version: "0.1"
  date: '2026-10-03'
  author: Amish Chadha
  change: Decisions 4A and 9A recorded and carried into the model, calculations, bill of materials, requirements, drawings and build plan
---

# 0003: Lighter ropes and one standard footing

- **Date:** 2026-10-03
- **Status:** decided. Decided by Amish on 2026-10-03, choosing option A on every requirement decision put to him: "1A 2A 3A 4A 5A 6A 7A 8A 9A 10A 11A". This record carries decisions 4A (R2) and 9A (R6).

> **Safety:** CanalRung is safety-critical rescue and rope equipment. A smaller rope has less reserve; the 9 mm rope chosen still meets the four-times rope factor of R4, but only just, so the bought rope must declare at least 18 kN and the TRL 4 proof load must use wet, knotted rope. Never enter the water to rescue someone.

## Context

At TRL 3 (CNR-CAL-001 v0.2) the ladder as thrown weighed 4.48 kg against the 4.0 kg target of R2, and R2 was reported as not met. The 10.5 mm EN 1891 type A ropes (1.08 kg) were the second largest mass after the rungs, which were kept strong on purpose (CNR-DDR-001, D3 and D10). Separately, the standard 400 x 1,000 mm footing met R6 only in drained soil (factor 1.92) and fell to 0.85 in a saturated bank, so the larger 500 x 1,200 mm footing was kept for wet or soft banks and the soil had to be judged at each site.

## Options considered

- **4A (chosen).** Downsize the two ropes to a rope that still holds at least three times the 4.5 kN target wet with knots; keep the stronger rungs. If the thrown ladder still exceeds 4.0 kg, restate R2 to 4.5 kg.
- **4B.** Keep the 10.5 mm ropes and keep reporting R2 as not met.
- **9A (chosen).** Make the 500 x 1,200 mm footing the standard footing at every site.
- **9B.** Keep two footings and decide the size from the soil at each site.

## Decision

**Ropes (4A).** The side ropes become 9 mm low-stretch kernmantle to EN 1891 type B, polyester preferred, with a declared breaking strength of at least 18 kN and about 55 g/m. Nine millimetres is the smallest common life-safety rope with a standard minimum strength; 8 mm accessory cord (EN 564) would save another 0.2 kg but its standard minimum of about 12.8 kN gives only 2.9 times the target wet with knots, below Amish's floor of three. The cut length (8.0 m each), knots, seizings, bushes (12 mm bore), screw links and edge protectors (for 9 to 13 mm rope) are unchanged. The model's overhand knot is drawn at 23 mm across instead of 26 mm, and 26 new model checks confirm that the 9 mm rope runs at least 1 mm clear of every bush bore.

The thrown ladder still weighs more than 4.0 kg (4.27 kg), so under Amish's fallback in 4A R2 is restated to 4.5 kg (9.9 lb).

**Footing (9A).** The 500 mm diameter x 1,200 mm deep footing, with a 2,300 mm post set 1,100 mm into it, is the standard at every site. The anchor stays 250 mm above the ground, so the bolt holes move to 1,350 mm from the bottom of the post. R6 is restated for drained or saturated granular bank soil.

## Results (CNR-CAL-001 v0.3)

| Requirement | Target | Before | After |
| --- | --- | --- | --- |
| R2 | Ladder as thrown at most 4.5 kg (was 4.0 kg) | 4.48 kg, not met | 4.27 kg, met on paper [B3] |
| R3 | At least 0.15 kg spare per rung; weight factor at least 1.5 | 0.274 and 0.218 kg; 1.73 | 0.277 and 0.221 kg; 1.75 [C1], [C2] |
| R4 | Ropes wet with knots at least 4 times 4.5 kN (18 kN) | 22.4 kN, 5.0 times | 18.4 kN, 4.08 times [E1] |
| R6 | Each anchor element at least 1.5, drained or saturated soil | Footing 1.92 drained, 0.85 saturated | Footing 3.58 drained, 1.59 saturated [G4], [G5] |
| R9 | Reported against USD 500 | USD 543.60 | USD 605.20 [I1] |

The model passes 271 of 271 constructability checks (245 before, plus 26 rope-in-bush checks).

## Consequences

- Value-engineering target: USD 500. Estimated cost of the constructable design: USD 605.20 (USD 105.20 over the target). The footing grows from about 12 to about 22 bags of concrete (USD 78.00 to USD 143.00 at USD 6.50 a bag), the post from 2.1 to 2.3 m (USD 48.00 to USD 52.60, pro rata), and the ropes fall from USD 40.00 to USD 32.00 (16 m at about USD 2.00 a metre). `budget_usd` is unchanged at 500.
- The footing needs about 0.23 m3 of concrete instead of 0.12 m3: about 550 kg of bagged premix to carry to the bank, or a small ready-mix delivery. The build plan says so.
- One footing size removes the soil judgement from each install, but soft clay or peat banks are still outside the screening values and need a site pull test.
- The rope margin over R4 is thin (4.08 against 4). If the bought rope declares less than 18 kN, R4 is not met and the rope must be changed.
- Throw trials at TRL 4 will show whether 4.3 kg is easy to throw for untrained adults.

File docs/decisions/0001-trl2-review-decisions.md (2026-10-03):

---
doc_id: CNR-DDR-001
title: CanalRung TRL 2 review decisions
project: CanalRung
doc_type: Design decision record
version: "0.1"
status: Draft
date: '2026-10-03'
author: Amish Chadha
license: CERN-OHL-S-2.0
revisions:
- version: "0.1"
  date: '2026-10-03'
  author: Amish Chadha
  change: "TRL 2 review items D1 to D14, decided as recommended under Amish's 2026-10-03 pre-approval"
---

# 0001: TRL 2 review decisions

- **Date:** 2026-10-03
- **Status:** accepted. Decided by Amish under his pre-approval of 2026-10-03: "start with the first 14 repos from the list of 29 projects. I pre-approve the batch runs along with any recommendations you come up with. I also accept any cost overruns or variations from the assumed scope cost."

## Context

The scaffold (CNR-PRB-001, CNR-PRC-001 and CNR-REQ-001, all v0.1) left five open questions and several choices undecided: bank heights and flows, sink or float, the load standard, theft, the anchor type, the rung and rope construction, the throw line and the partners. Populating the concept to TRL 2 needed an answer to each. Because Amish pre-approved every recommendation for this batch, each item below is decided as recommended rather than left "Proposed, awaiting Amish". Choices that touch safety take the conservative option, and the record says what evidence would relax them. Partners and regions are named as the first candidates to approach, not as agreed.

## Options considered

*Table 1. Options for each item.*

| # | Item | Options |
| --- | --- | --- |
| D1 | Design envelope | (a) 1.5:1 slopes to 3.0 m (needs a 5.4 m ladder and about 6 kg); (b) 1.5:1 slopes to 2.0 m and vertical walls to 3.0 m with a 4.0 m ladder; (c) vertical walls only |
| D2 | Anchor | (a) ground stake driven at the time; (b) post loop around any nearby post; (c) cross bar across the bank; (d) the station post itself, set in concrete, with the ladder linked to it in advance |
| D3 | Rung | (a) 25.4 x 1.65 mm aluminium tube (lighter); (b) 28.6 x 1.65 mm aluminium tube (stronger); (c) solid HDPE rod (floats but about 6 kg for the set); (d) GFRP tube |
| D4 | Rope and joint | (a) 10.5 mm EN 1891 type A kernmantle through the rung ends, overhand stopper knot under and seizing over each end; (b) polypropylene rope with clamps; (c) laid rope with rungs seized between the strands (Jacob's ladder) |
| D5 | Wall stand-offs | (a) on every rung (about 1.3 kg); (b) on every third rung (0.42 kg); (c) none |
| D6 | Bottom end | (a) weighted to sink; (b) floating; (c) a soft weight on a short tail with floating rungs above it |
| D7 | Throw line | (a) fitted; (b) left out of the first prototype |
| D8 | Storage | (a) a bought UV-stabilised 70 L box on the post, no lock; (b) a made steel cabinet; (c) a locked box |
| D9 | Load standard | (a) certify to a ladder or life-saving standard now; (b) rope to EN 1891 type A, rung and anchor targets as in CNR-REQ-001, proof-loaded at TRL 4, no certification claimed |
| D10 | R2 mass target | (a) meet 4.0 kg with lighter rungs and fewer stand-offs; (b) keep the safer rung and report R2 as not met |
| D11 | Theft | (a) lock; (b) no lock, tamper tag and inspection; (c) no rope or aluminium (not possible) |
| D12 | Shared blocks | CalRig for proof loads; LaneSkiff boarding step |
| D13 | Co-design partner | Western US irrigation districts; Punjab canal authorities; water-safety councils |
| D14 | Pitch, problem and value-engineering target | Change or keep |

## Decision

*Table 2. Items decided, 2026-10-03.*

| # | Decision | Why | What would relax it |
| --- | --- | --- | --- |
| D1 | (b): water to 2.0 m below the coping on 1.5:1 slopes and to 3.0 m on vertical walls; currents to 2.0 m/s | Keeps the ladder near the 4 kg throwing target; covers the vertical-walled and steep reaches where self-rescue is hardest. A 6 m variant for deeper sloped canals is a later option | Partner district data on its reaches |
| D2 | (d): the post is the anchor; forged M16 eye nut on an M16 bolt through the post, 250 mm above ground, ladder linked in advance | A bystander cannot set a 4.5 kN stake in 30 s; a hand-held top pulls people in. The conservative option | A tested portable anchor for a vehicle kit |
| D3 | (b): 28.6 x 1.65 mm 6061-T6, 360 mm long | 0.56 of yield at 1.5 kN against 0.73 for the lighter tube. Safety before mass | Proof-load results showing the lighter tube keeps a two-thirds margin |
| D4 | (a): EN 1891 type A 10.5 mm, polyester preferred; nylon bushes in the rung holes; overhand knot under, seizing over | Rated rope with known knotted strength; a joint anyone can tie and inspect; polypropylene is weak and degrades in sun | |
| D5 | (b): rungs 3, 6, 9 and 12, 95 mm from rung axis to wall | Hand room on a flat wall at a third of the mass of (a) | Tank trials showing climbers manage with fewer |
| D6 | (c): soft 0.5 kg steel shot pouch, 280 mm below the bottom rung, rungs floating | The end goes down and stays put; the rungs stay at the surface; nothing hard is thrown near the person | Throw trials |
| D7 | (b): no throw line on the first prototype | A second line can tangle and is an entanglement hazard in moving water. Conservative | Throw trials showing a line is needed to steer the ladder |
| D8 | (a): bought bright 70 L UV-stabilised box clamped to the post, drain holes, rope notch, blunt-tip knife under the lid | Cheap, replaceable, visible; keeps the rope dark | |
| D9 | (b) | Certification is beyond TRL 3; the targets give margins over the design climber and will be proof-loaded with CalRig | |
| D10 | (b): keep the D3 rung; R2 reported as not met (4.48 kg against 4.0 kg) | The rung margin protects the climber; 0.5 kg more may not matter to a thrower. Savings to try are in the register | Throw trials with the 4.5 kg ladder |
| D11 | (b): no lock; numbered tamper tag on the latch; the partner district inspects on a set schedule and after each use | A locked rescue box fails when it is needed | Theft data from a pilot |
| D12 | CalRig named as the proof-load rig for TRL 4 (candidate shared block); the LaneSkiff boarding step stays outside this repository | Keeps this repository to one product | |
| D13 | First candidates to approach: the Kittitas Reclamation District (Washington) as co-design partner and the Water Safety Council of Fresno County as water-safety partner; neither contacted | Both publish canal safety guidance cited in CNR-PRB-001 | |
| D14 | No change: pitch and problem as scaffolded; `budget_usd` stays 500 as the value-engineering target | Cost overruns are accepted under the pre-approval and reported, not used to change the target | |

## Consequences

- CNR-PRB-001, CNR-PRC-001 and CNR-REQ-001 are revised. R1 is restated for the D1 envelope, R6 for the fixed station anchor of D2, and R10 is added for D6 and D8.
- The design is modelled in `cad/src/model.py` on these decisions and then made constructable in CNR-DDR-002.
- `project.yaml`: only the TRL fields, `design_state` and the evidence list change; `budget_usd`, the pitch and the problem are unchanged.
- Nothing in this record authorizes building or testing. TRL 4 is outside the current portfolio phase.

> **Safety:** Every choice above that touches safety (D2, D3, D6, D7, D11) took the more conservative option. None of them makes the ladder safe without proof loads and supervised trials.

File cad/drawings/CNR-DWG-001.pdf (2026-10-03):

PRELIMINARY, NOT FOR FABRICATION | CanalRung · github.com/BoujeeEnjinia1701/canalrung

FRONT VIEW
Scale 1:50; looking at the front (along +Y)

TOP VIEW
Scale 1:50; looking down (along -Z)

RIGHT VIEW
Scale 1:50; looking at the right side (along -X)

6600

900 4308

1,000 coping to post

1,200 1,200

2,000

DESIGN WATER LINE

1.5:1 LINED WALL (SITE)

EYE NUT (5), 250 ABOVE GROUND

13 RUNGS AT 335 PITCH (13)

FOOTING 500 DIA (2)

ISOMETRIC VIEW
Not to scale; seen from the bank side, front right and above; grey wall is the site

MAIN DIMENSIONS AND INTERFACES (MM)
Post 60 x 60 x 3 SHS x 2,300; 1,100 in a 500 x 1,200 footing
Post centre 1,000 back from the coping; top 1,200 above ground Anchor: M16 forged eye nut on an M16 x 90 bolt, 250 above ground Box about 450 x 650 x 360, base 450 up; 2 square U-bolts M8 Ladder: 13 rungs, 335 pitch, ropes 320 apart; section 4,020
Rung 28.6 x 1.65 Al tube x 360; foam float sleeve 50 OD Stand-offs on rungs 3, 6, 9, 12: rung axis 95 off the wall
Ropes 9 kernmantle, about 8.0 m each; knot under every rung end Ladder as thrown about 4.3 kg; soft 0.5 kg throw weight
Small parts (bushes, caps, knots, seizings): DWG-106, 109 Third-angle; front view from -Y; canal along Y; (n) = BOM line
REV | DESCRIPTION | DATE | BY
P1 | Preliminary GA for TRL 3 (from cad/src/model.py) | 2026-10-03 | AC
P2 | CNR-DDR-002: design for construction | 2026-10-03 | AC
P3 | CNR-DDR-003: 9 mm ropes; 500 x 1,200 footing standard | 2026-10-03 | AC
CANALRUNG | github.com/BoujeeEnjinia1701/canalrung

## Throwable canal ladder and bank station: general arrangement

DRAWING NO.
CNR-DWG-001

REV
P3

SHEET
1 of 1

SIZE

## ANSI B

SCALE
1:50

UNITS
mm
PROJECTION | DATE
2026-10-03

DRAWN
Amish Chadha

MATERIAL / NOTES
Steel post, aluminium rungs, kernmantle rope; see bom/bom.csv. PRELIMINARY, NOT FOR FABRICATION
Licensed CERN-OHL-S-2.0 · Design Molecule Lab · designmolecule.com | Generated from cad/src; do not edit by hand

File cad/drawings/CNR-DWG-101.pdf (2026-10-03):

### BUILD PLAN SKETCH, PLAN NOT YET BUILT CanalRung · github.com/BoujeeEnjinia1701/canalrung

FRONT VIEW
Scale 1:20; looking at the front (along +Y)

TOP VIEW
Scale 1:20; looking down (along -Z)

RIGHT VIEW
Scale 1:20; looking at the right side (along -X)

60

60 2300

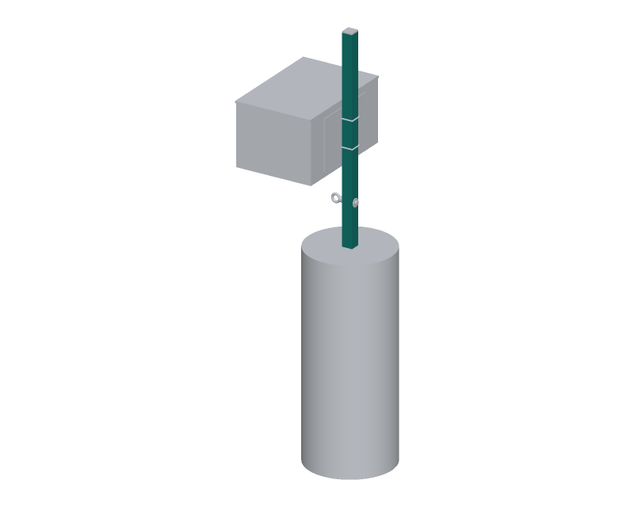
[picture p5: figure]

WHERE IT GOES
This part in colour, its neighbours in grey

HOW TO MAKE IT AND HOW IT FITS
Cut 2,300 long, square; file the burr off both ends.
Mark one face as the canal side. 1,350 up from the bottom end (250 above ground when set), on the face centre line: canal-side wall: drill 17.5 for the M16 bolt;
back wall, same axis: drill 21.5 for the crush tube.
Use a drill guide or drill press so both holes share one axis. Deburr; cold galvanising paint on the holes and cut ends. Mark a ground line 1,100 up from the bottom end.
Fits: 1,100 sits in the footing, 100 above its base;
plate and box on the canal face; cap on top.
REV | DESCRIPTION | DATE | BY
P1 | Making sketch for the prototype build plan | 2026-10-03 | AC
CANALRUNG | github.com/BoujeeEnjinia1701/canalrung

## Post: making sketch

DRAWING NO.
CNR-DWG-101

REV
P1

SHEET
1 of 1

SIZE

## ANSI B

SCALE
1:20

UNITS
mm
PROJECTION | DATE
2026-10-03

DRAWN
Amish Chadha

MATERIAL / NOTES
Hot-dip galvanised steel 60 x 60 x 3 SHS, S235 or better
Licensed CERN-OHL-S-2.0 · Design Molecule Lab · designmolecule.com | Generated from cad/src; do not edit by hand

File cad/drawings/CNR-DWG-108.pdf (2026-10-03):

### BUILD PLAN SKETCH, PLAN NOT YET BUILT CanalRung · github.com/BoujeeEnjinia1701/canalrung

FRONT VIEW
Scale 1:2; looking at the front (along +Y)

TOP VIEW
Scale 1:2; looking down (along -Z)

RIGHT VIEW
Scale 1:2; looking at the right side (along -X)

16

115 40

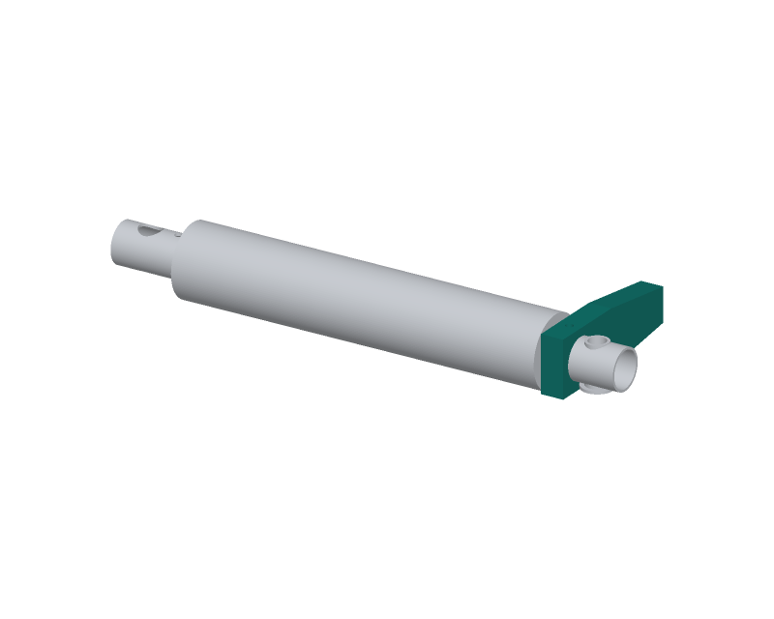
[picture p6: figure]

WHERE IT GOES
This part in colour, its neighbours in grey

HOW TO MAKE IT AND HOW IT FITS
Mark the outline from this sketch: 115 long, 40 tall at the rung end, tapering to a 24 tall nose over the last 60. Saw and file; round the nose corners 4 so it slides
on concrete.
28.8 hole for the rung, centre 20 from the back end and on the height centre line (step drill or hole saw). 5.3 hole straight down through the middle of the 16 thickness, crossing the rung hole.
Fits: on the rung just inside the bush, nose toward the wall, held by one M5 x 50 bolt through block and rung.
REV | DESCRIPTION | DATE | BY
P1 | Making sketch for the prototype build plan | 2026-10-03 | AC
CANALRUNG | github.com/BoujeeEnjinia1701/canalrung

## Wall stand-off block: making sketch (make 8)

DRAWING NO.
CNR-DWG-108

REV
P1

SHEET
1 of 1

SIZE

## ANSI B

SCALE
1:2

UNITS
mm
PROJECTION | DATE
2026-10-03

DRAWN
Amish Chadha

MATERIAL / NOTES
HDPE sheet 16 mm, UV-stabilised
Licensed CERN-OHL-S-2.0 · Design Molecule Lab · designmolecule.com | Generated from cad/src; do not edit by hand

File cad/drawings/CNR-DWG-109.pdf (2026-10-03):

### BUILD PLAN SKETCH, PLAN NOT YET BUILT CanalRung · github.com/BoujeeEnjinia1701/canalrung

FRONT VIEW
Scale 1:50; looking at the front (along +Y)

TOP VIEW
Scale 1:50; looking down (along -Z)

RIGHT VIEW
Scale 1:50; looking at the right side (along -X)

89

23 5625

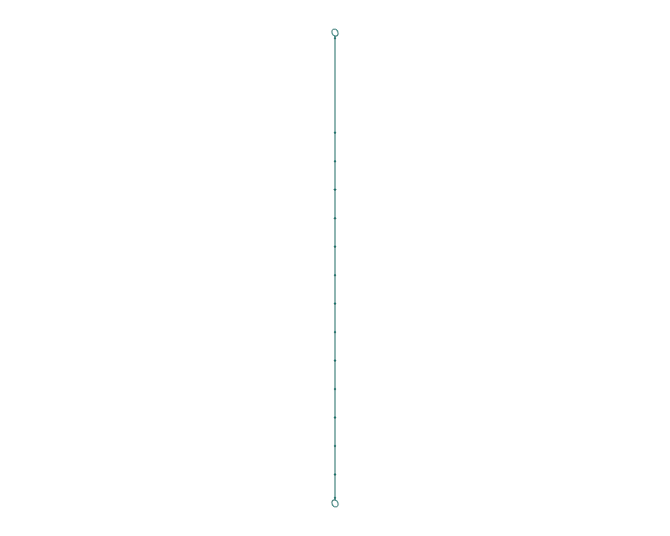
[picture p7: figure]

WHERE IT GOES
This part in colour, its neighbours in grey

HOW TO MAKE IT AND HOW IT FITS
Cut 7.9 m; tape, cut and heat seal both ends.
Top loop: figure-eight on a bight with a 60 tail, loop about 80 long (fits the 10 mm screw link).
From the loop's knot measure 1,106 down: mark rung 1. Then mark every 335 for rungs 2 to 13 (12 more marks). Mark both ropes side by side so the marks match.
At each mark: overhand stopper knot, its top at the mark, tied when the rung is threaded (build step 11).
Below rung 13: 280 to a figure-eight loop for the bottom link. Dress and set every knot by hand before loading.
REV | DESCRIPTION | DATE | BY
P1 | Making sketch for the prototype build plan | 2026-10-03 | AC
CANALRUNG | github.com/BoujeeEnjinia1701/canalrung

## Side rope: making sketch (make 2)

DRAWING NO.
CNR-DWG-109

REV
P1

SHEET
1 of 1

SIZE

## ANSI B

SCALE
1:50

UNITS
mm
PROJECTION | DATE
2026-10-03

DRAWN
Amish Chadha

MATERIAL / NOTES
9 mm EN 1891 type B low-stretch kernmantle, polyester preferred
Licensed CERN-OHL-S-2.0 · Design Molecule Lab · designmolecule.com | Generated from cad/src; do not edit by hand

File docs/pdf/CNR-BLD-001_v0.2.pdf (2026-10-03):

C A N A L R U N G · B U I L D P L A N

# CanalRung prototype build plan

Design Molecule Lab · designmolecule.com

D O C U M E N T CO N T RO L

Document ID | CNR-BLD-001 | Version | 0.2
Status | Draft | Date | 2026-10-03
Author | Amish Chadha | License | CERN-OHL-S-2.0
Project TRL | TRL 3 | Proof of concept
Repository | github.com/BoujeeEnjinia1701/canalrung
Source | docs/05-build-plan.md @ uncommitted

R EV I S I O N H I STO RY

Version | Date | Author | Change
0.2 | 2026-10-03 | Amish Chadha | Amish's decisions of 2026-10-03 (CNR-DDR-003): 9 mm ropes; the 500 x 1,200 footing and 2,300 post at every site
0.1 | 2026-10-03 | Amish Chadha | First build plan; design made constructable (CNR-DDR-002)

D R A F T · N O T F O R F A B R I C A T I O N

## CanalRung prototype build plan

Plan, not yet built. How to build the first proof-of-concept prototype, component by component. Building and testing to it is TRL 4 work. Decisions still to be made are kept in the design decisions register (docs/06-design-decisions.md), not here.

### 1. What you are building


Figure 1. Every component pulled apart and numbered in build order. The ladder is drawn with 4 of its 13 rungs so the parts stay readable.
The prototype is one CanalRung station and its ladder. The station is a galvanised steel post set in a concrete footing a metre back from the canal edge, with a forged eye nut near its foot that anchors the ladder and a bright plastic box clamped to it that holds the ladder. The ladder is 13 aluminium tube rungs, each in an orange foam float sleeve, hung on two red climbing-grade ropes by a knot under each rung end, with plastic stand-off blocks on four rungs, a soft weight at the bottom and a screw link at each end. Figure 1 shows the 23 components in the order you make or fit them. Nine are made in a small workshop or on site: the post, the footing, the crush tube, the mounting plate, the drilled box, the rungs, the float sleeves, the stand-off blocks and the ropes. The rest are bought and fitted. The work is cutting and drilling steel and aluminium tube, cutting aluminium sheet, plastic and foam, digging and pouring a small footing, and rope work: cutting, sealing, tying knots and seizing. The parts cost about USD 605, from the bill of materials.

Safety: CanalRung is rescue and rope equipment that a person's life will depend on. Build it carefully, inspect every knot, and never let anyone climb it, stand on it or test it in water until section 6 says so. Work at the
canal edge only with a second person watching and a life jacket on; dig only after underground services have been located. Cut tube and sheet edges are sharp: deburr everything and wear gloves. Heat sealing rope ends gives off fumes; do it in a ventilated space.

### 2. What changed to make it buildable

The concept showed what CanalRung does; some of its parts could not be made or fixed as drawn. Each change below keeps what the ladder does, and all are recorded in decision record CNR-DDR-002.
Table 1. Changes from the concept.
Component The concept had | The buildable design has | Why

Rung to
rope

Rungs "fixed at even
spacing", no joint

The rope runs through a bushed hole in each rung end; a knot under the rung carries it and a seizing over it stops it floating up (Figure 11)

The classic rope ladder joint, made with hand tools and
checked by eye

Wall
spacers

Spacers on some
rungs, no fixing

Plastic blocks on rungs 3, 6, 9 and 12, each locked by one M5 bolt through block and rung (Figure 15)

They cannot slide or turn

Floats | "Buoyant rungs" | A closed-cell foam sleeve on every rung, cut to fit between the bushes or blocks (Figure 13) | Known buoyancy; the sleeve length is set by the parts beside it
Tube ends | Open | Plastic end caps that stop short of the rope hole | No sharp or open ends
Anchor | Stake, post loop or cross bar | Forged eye nut on a bolt through the post, with a crush tube inside (Figure 6) | A fixed anchor that holds 4.5 kN; the post walls do not crush
Box | On the post, no fixing An aluminium plate and two U-bolts round the post;
| | the U-bolt legs pass through the box back (Figure 9) | No holes in the post for the box
Rope ends | No termination | A loop at each end, held in rated screw links at the eye nut and at the throw weight (Figures 17 and 18) | Rated, replaceable connections
Canal edge | Ropes on the concrete edge | Two sleeves on the ropes where they cross the edge (Figure 19) | Rope over a sharp edge loses strength
Box lid | Could not close over the anchored ropes | A notch in the front rim and four drain holes (Figure 8) | The ladder stays linked to the anchor while stored
Footing | No size | 500 mm across and 1,200 mm deep at every site, wet or dry (Figure 4) | Holds the anchor load in wet or dry bank soil, so one size fits every site

### 3. Making the components

Make and check each component before the assembly step that needs it. Sizes are in millimetres. On the station, "canal side" is the face of the post toward the water and "back" the face away from it. On the ladder, "up" is toward rung 1, the top rung, and "wall side" is the side the stand-off blocks point to. Workshop tolerance is 1 mm unless a step says otherwise; drawings do not carry tolerances before TRL 4.

### 3.1 Post

Figure 2. Post making sketch (CNR-DWG-101).
What it is and what it is made from. The upright that holds the box and carries the ladder anchor. Hot-dip galvanised square steel tube 60 x 60 x 3 mm, grade S235 or better, 2,300 long.
How to make it.
Cut the tube to 2,300, square, and file the burr off both ends.
Choose one face as the canal side and mark it along its length.
Measure 1,350 up from the bottom end and mark the centre of the canal-side face and of the back face at that height. This puts the anchor 250 above the ground.
Clamp the post in a drill press or use a drill guide so both holes share one axis square to the faces. Drill a 6 pilot right through both walls.
Open the hole in the canal-side wall to 17.5 (for the bolt) and the hole in the back wall to 21.5 (for the crush tube).
Deburr both holes inside and out. Paint the holes and both cut ends with cold galvanising paint.

1.
2.
3.

4.

5.

6.

Mark a ground line all round, 1,100 up from the bottom end.

How it fits the parts next to it. The bottom 1,100 sits in the concrete footing with 100 of concrete under it (Figure 4). The crush tube goes in through the back hole and the anchor bolt through both (Figure 6). The mounting plate sits flat on the canal-side face with its bottom edge 480 above the ground line, held by two U-bolts round the back of the post (Figure 9). The cap closes the top.
Check before moving on. Push a 16 rod through both holes: it must pass straight through without forcing. The 21.3 crush tube must slide into the back hole.

### 3.2 Concrete footing

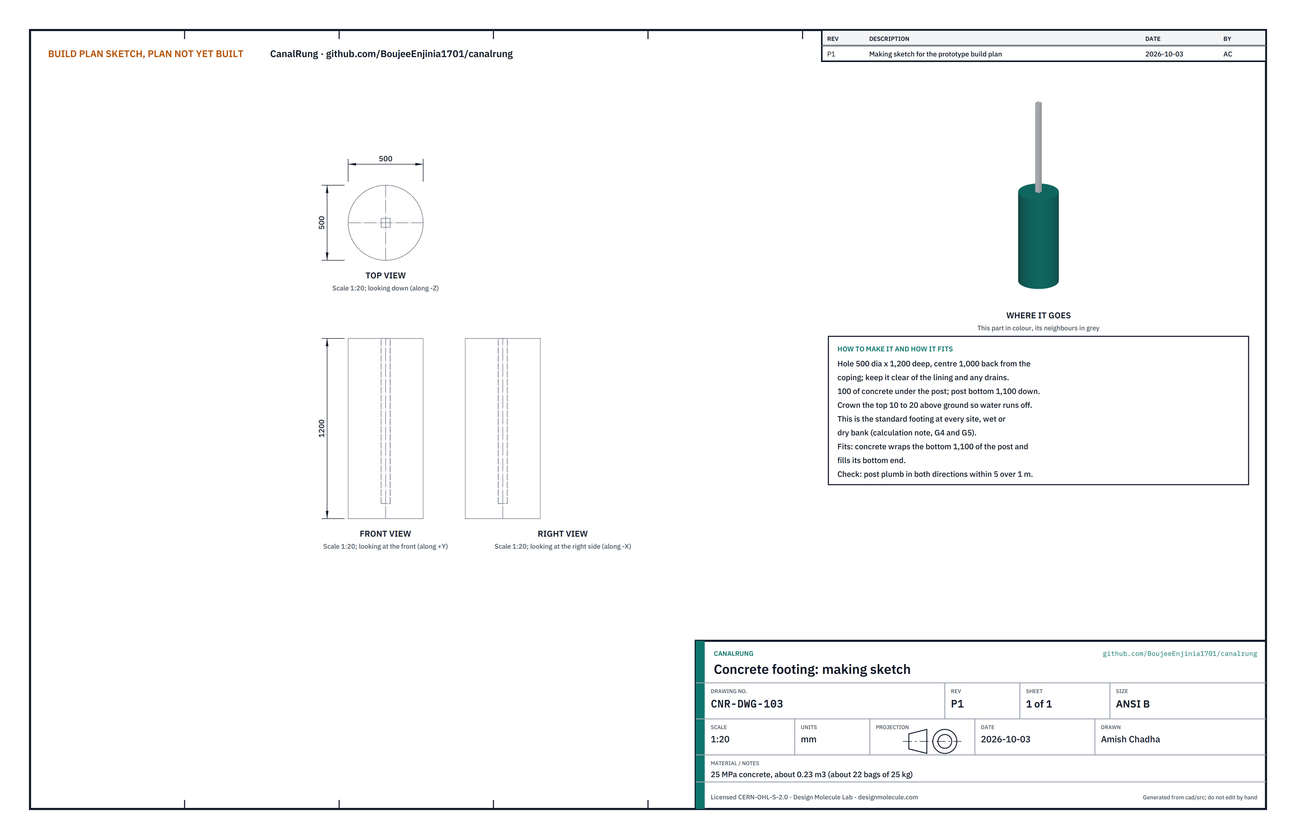
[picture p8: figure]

Figure 3. Footing making sketch (CNR-DWG-103).
What it is and what it is made from. The concrete that holds the post in the bank against the pull of a climber. About 0.23 m3 of 25 MPa concrete, about 22 bags of 25 kg premix, in a hole 500 across and 1,200 deep. This one size is used at every site, whether the bank is dry or wet.
How to make it.
Choose the spot with the canal operator: 1,000 from the canal edge to the post centre, on level bank, clear of the lining's joints, drains and any buried services (have them located first).
Dig or auger the hole 500 across and 1,200 deep, with straight sides. Keep the spoil away from the canal edge. Pour 100 of concrete into the bottom and level it.
Stand the post on it (assembly step 1), plumb it both ways with a spirit level and brace it.

7.

1.

2.
3.
4.

Fill the hole in layers of about 200, rodding each layer to drive out air, up to 10 to 20 above the ground, and slope the top away from the post so water runs off.
Keep the concrete damp and leave it 7 days before any load goes on the eye nut.

How it fits the parts next to it.

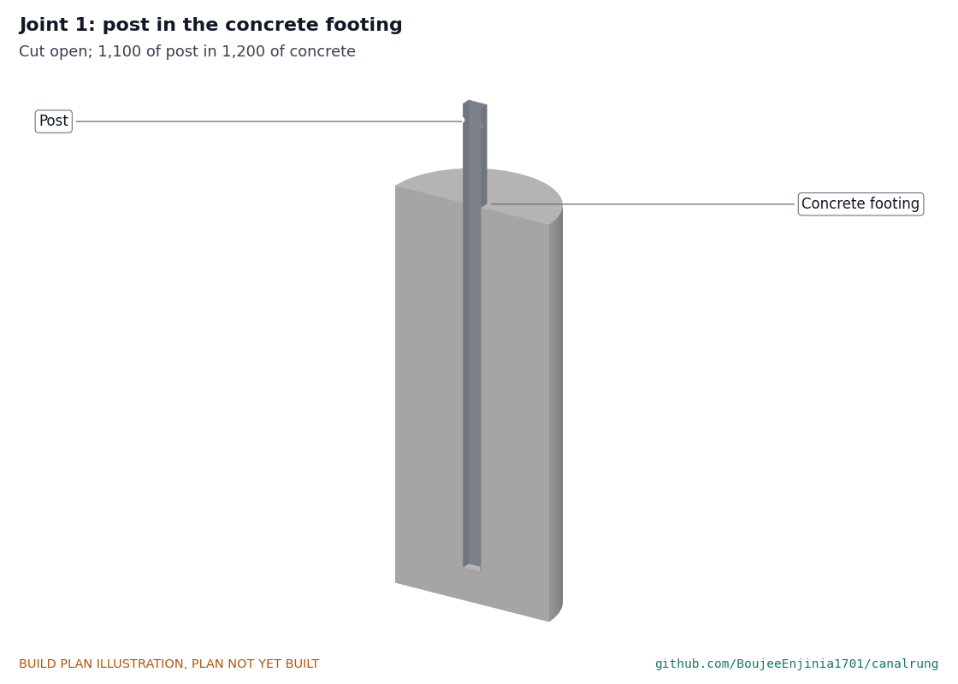
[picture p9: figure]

Figure 4. The post stands on 100 of concrete; the concrete wraps its bottom 1,100 and fills its open end.
Check before moving on. The post is plumb within 5 in 1,000 in both directions, the ground line is level with the ground, and the concrete is sound with no voids at the top.

5.

6.

### 3.3 Crush tube

Figure 5. Crush tube making sketch (CNR-DWG-102).
What it is and what it is made from. A short steel tube inside the post that the anchor bolt passes through, so the bolt can be tightened without squashing the post. Steel tube 21.3 outside, 2.0 wall (half-inch pipe class).
How to make it.
Cut 57 long with the ends square within 0.5.
Deburr inside and out so the bolt slides through.

How it fits the parts next to it.

1.
2.

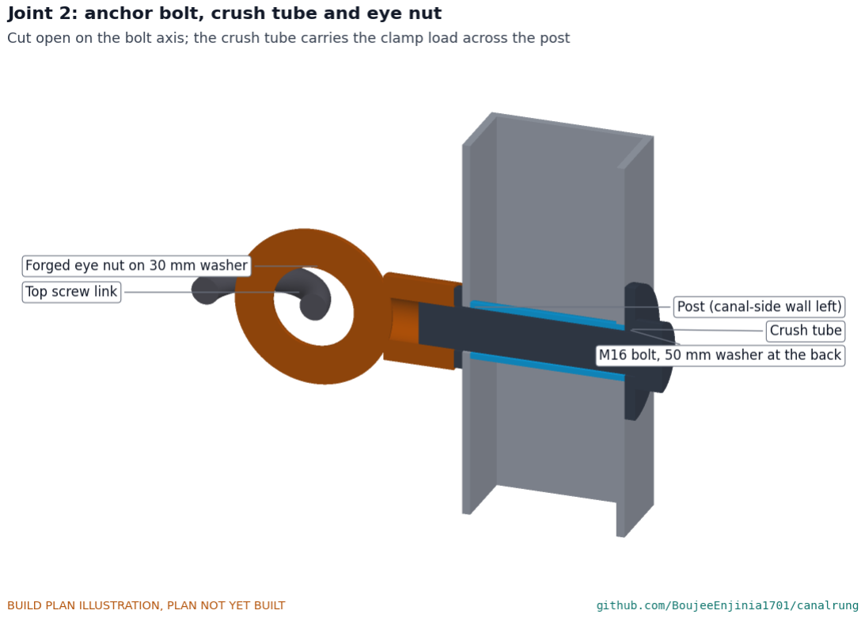
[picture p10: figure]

Figure 6. The crush tube goes in through the back wall and stops on the inside of the canal-side wall; the bolt runs through it; the eye nut screws onto the bolt on the canal side; the top screw link passes through the eye.
One end bears on the inside face of the canal-side wall; the other end is flush with the back face, where the 50 mm washer under the bolt head covers it. Tightening the bolt clamps the canal-side wall between the eye nut's washer and the crush tube, not the two walls together.
Check before moving on. Push the tube into the back hole: it must stop on the far wall with its end flush with the back face, within 0.5.

### 3.4 Box mounting plate

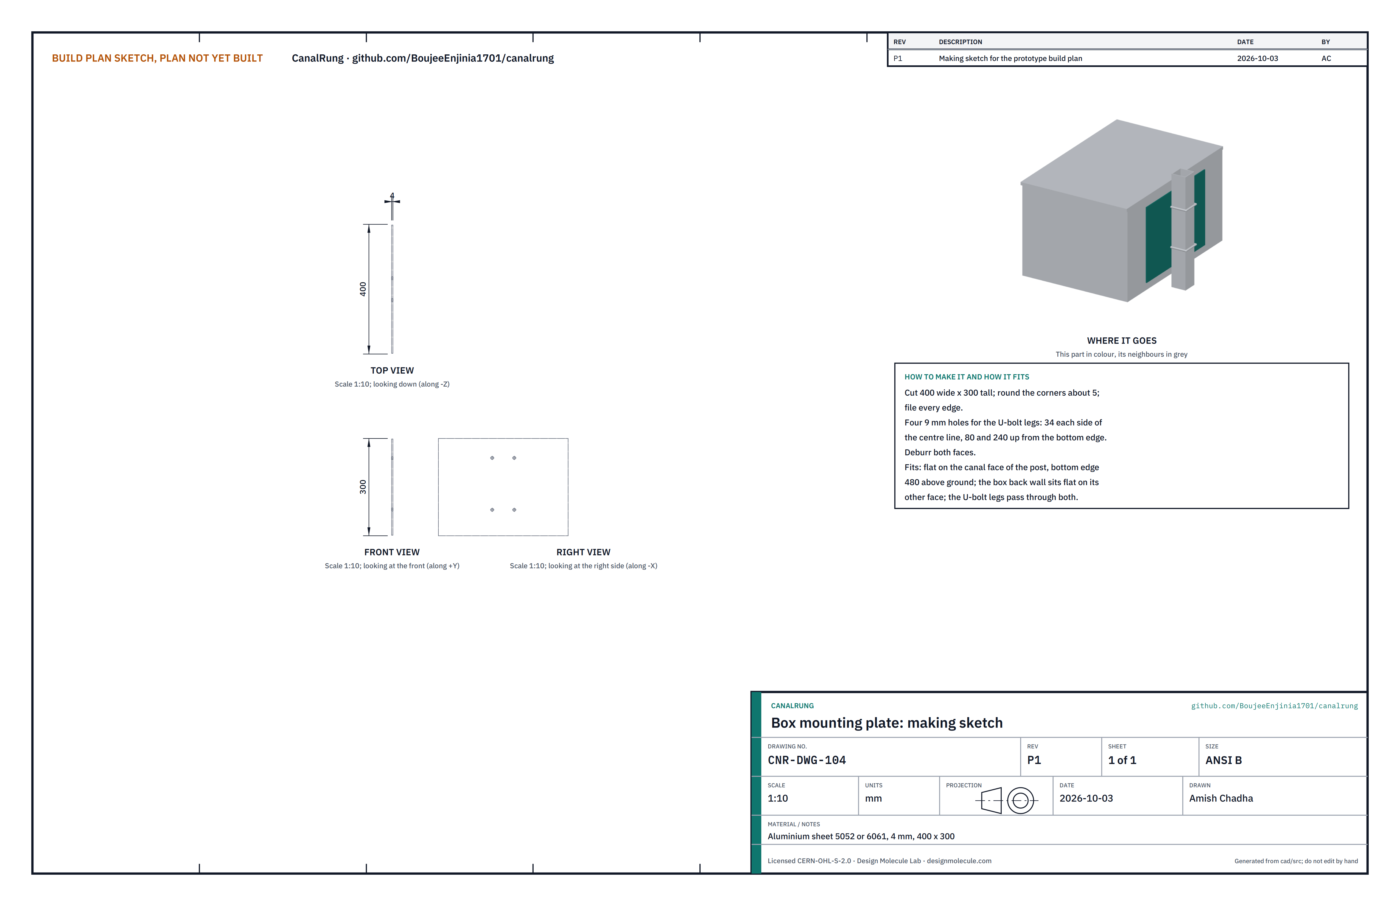
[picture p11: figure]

Figure 7. Mounting plate making sketch (CNR-DWG-104).
What it is and what it is made from. A flat plate between the post and the back of the box that spreads the clamp load over the plastic. Aluminium sheet 4 thick, 5052 or 6061 class, 400 wide and 300 tall.
How to make it.
Cut the plate to 400 x 300 and round the corners to about 5. File every edge smooth.
Mark a centre line down the 300 height.
Drill four 9 holes for the U-bolt legs: 34 each side of the centre line, at 80 and 240 up from the bottom edge. Deburr both faces.

How it fits the parts next to it. The plate sits flat on the canal-side face of the post, centred on it, with its bottom edge 480 above the ground. The box's back wall sits flat on its other face. The U-bolt legs pass through the plate and then the box (Figure 9).
Check before moving on. Hold the plate on the post at the right height: the holes must sit just outside the post's sides, 4 clear of them, where the U-bolt legs will run.

1.
2.
3.
4.

### 3.5 Storage box, drilled

Figure 8. Storage box drilling sketch (CNR-DWG-105).
What it is and what it is made from. A bought polypropylene or polyethylene storage box of about 70 L, about 450 deep, 650 wide and 360 tall outside, UV-stabilised, bright yellow or orange, with a hinged lid, clip latches and no lock. Check before buying that its inside depth takes a 370 long rung.
How to make it.
Hold the drilled mounting plate against the outside of the box's back wall, its bottom edge 30 above the box's base, centred. Mark the four holes through the plate. They come out 34 each side of the centre line and 110 and 270 up from the base.
Drill the four holes 9, from outside, with a sharp drill and a wood block inside the box behind the wall so the plastic does not split.
Drill four 8 drain holes in the base, 40 in from each corner.
Cut a notch 30 wide and 25 deep in the centre of the front rim (the side away from the hinge), with a fine saw and a file. Round its corners so the rope slides out easily.
Deburr every hole and the notch with a knife.

How it fits the parts next to it. The back wall sits flat on the mounting plate, with the lid hinge at the back, against the post. The U-bolt legs come through the four holes into the box, where a fender washer and a nyloc nut on each hold the box, the plate and the post together.

1.

2.

3.
4.

5.

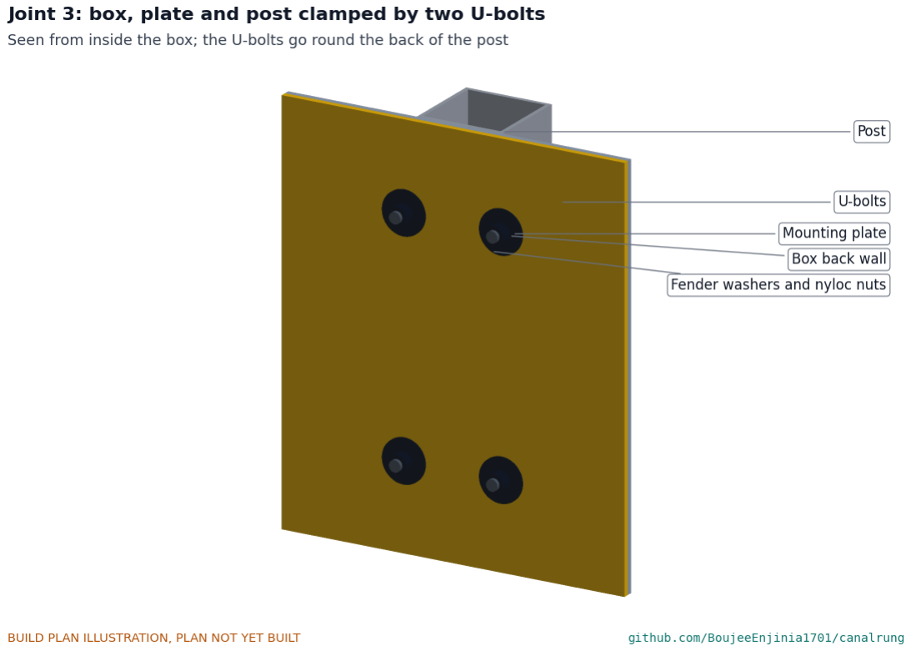
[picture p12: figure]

Figure 9. Seen from inside the box: the U-bolts go round the back of the post, through the plate and the box back wall; washers and nyloc nuts inside.
Check before moving on. The lid closes and latches with a 9 rope lying in the notch.

### 3.6 Rungs (make 13)

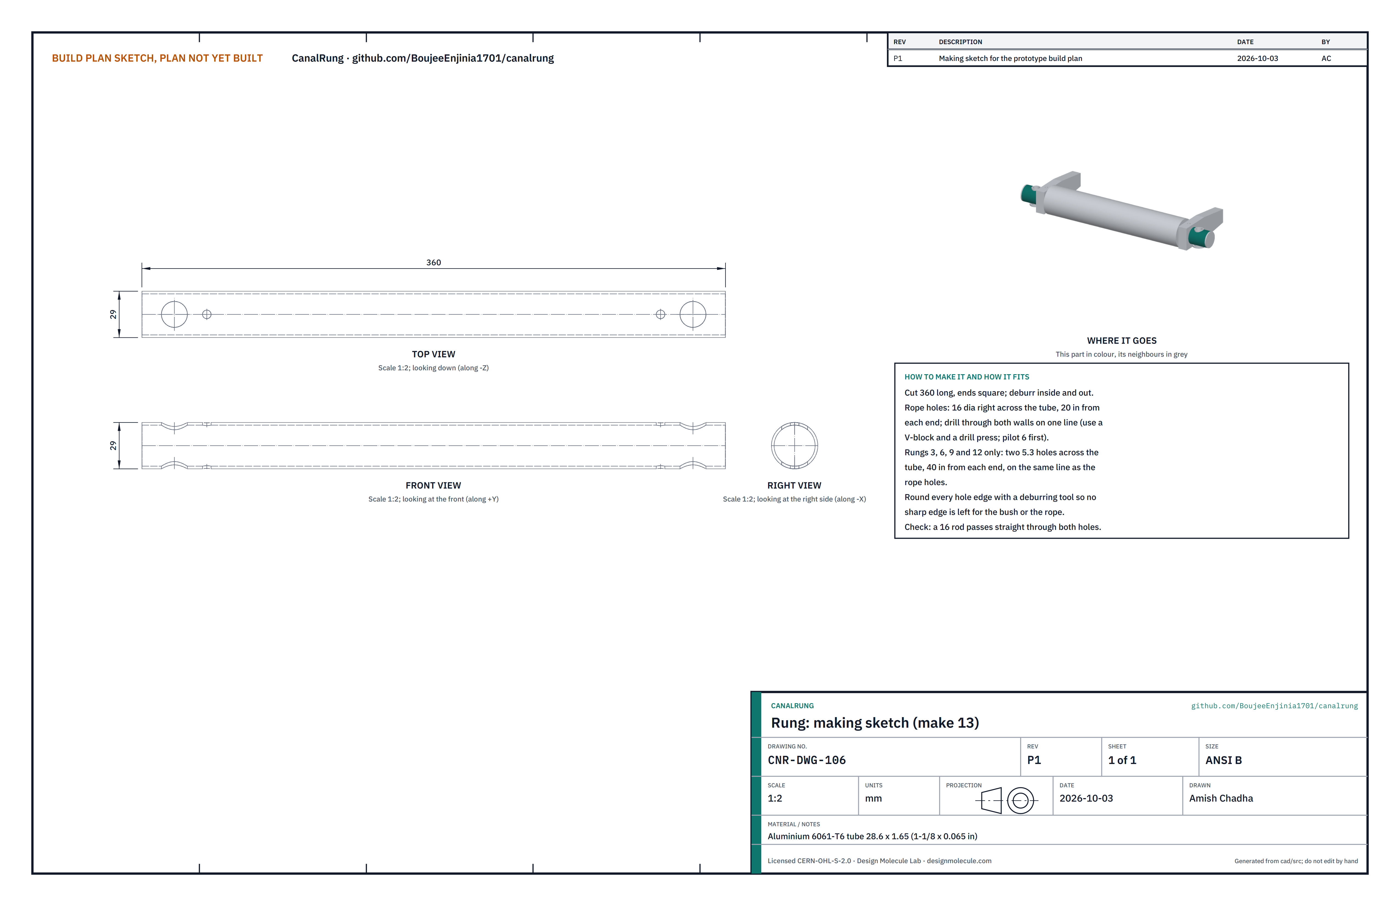
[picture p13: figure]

Figure 10. Rung making sketch (CNR-DWG-106), shown as a stand-off rung with both pairs of holes.
What it is and what it is made from. The hand and foot holds. Aluminium 6061-T6 round tube, 28.6 outside and 1.65 wall (1-1/8 in x 0.065 in), 360 long. About 4.7 m of tube for all 13.
How to make it.
Cut 13 lengths of 360, ends square, with a tube cutter or a fine saw and a square guide. Deburr inside and out. Number the rungs 1 to 13 with a marker; rung 1 is the top rung. Rungs 3, 6, 9 and 12 are the stand-off rungs. Lay each rung in a V-block on a drill press. Drill a 6 pilot right across the tube, 20 in from each end, through both walls on one line, then open the holes to 16. These are the rope holes.
Stand-off rungs only: on the same line as the rope holes, drill 5.3 right across the tube 40 in from each end (the block bolt holes).
Round the edge of every hole, inside and out, with a deburring tool, so no sharp edge is left for the bush.

How it fits the parts next to it.

1.
2.
3.

4.

5.

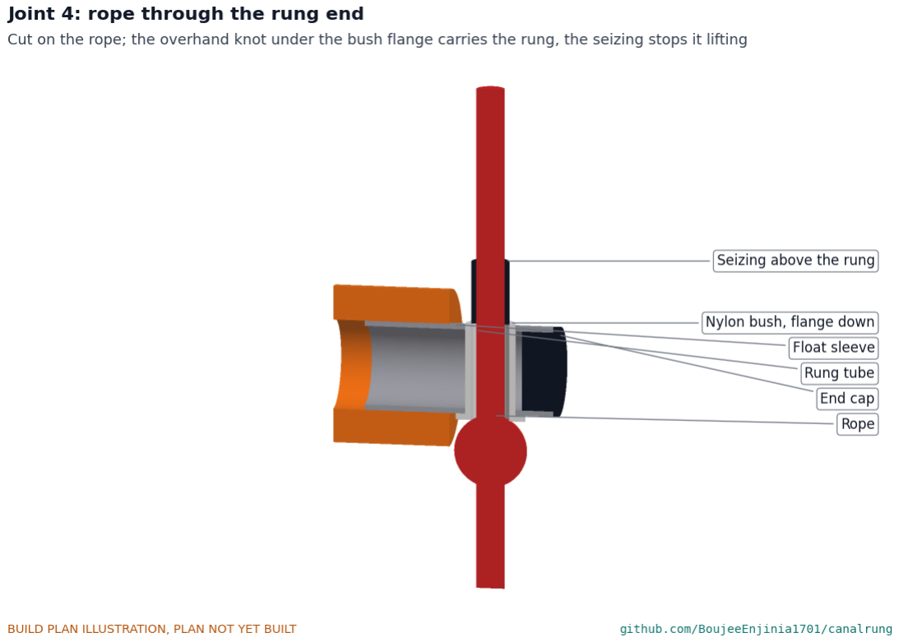
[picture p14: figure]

Figure 11. The nylon bush lines the rope hole with its flange under the rung; the overhand knot under the flange carries the rung; the seizing above the bush stops it lifting; the end cap stops 2 short of the hole.
A flanged nylon bush goes up through each rope hole from below, flange under the rung. The rope runs through the bush. The foam sleeve sits on the middle of the rung, 2 clear of the bushes. An end cap closes each end.
Check before moving on. A 16 rod passes straight through each pair of rope holes; all 13 rungs lie flat together with their holes lined up (sight along them).

### 3.7 Float sleeves (make 13)

Figure 12. Float sleeve making sketch (CNR-DWG-107).
What it is and what it is made from. The orange foam sleeve on each rung that makes it float and gives a softer grip. Closed-cell cross-linked polyethylene foam tube, 50 outside, 28 bore, about 33 kg/m3. About 3.7 m of tube in all.
How to make it.
Cut a short test piece and hold it under water for a minute; a cut end that takes up water means the foam is not closed-cell, so do not use it.
With a sharp knife against a square end stop, cut nine sleeves 294 long (for the plain rungs) and four 260 long (for rungs 3, 6, 9 and 12).

How it fits the parts next to it.

1.

2.

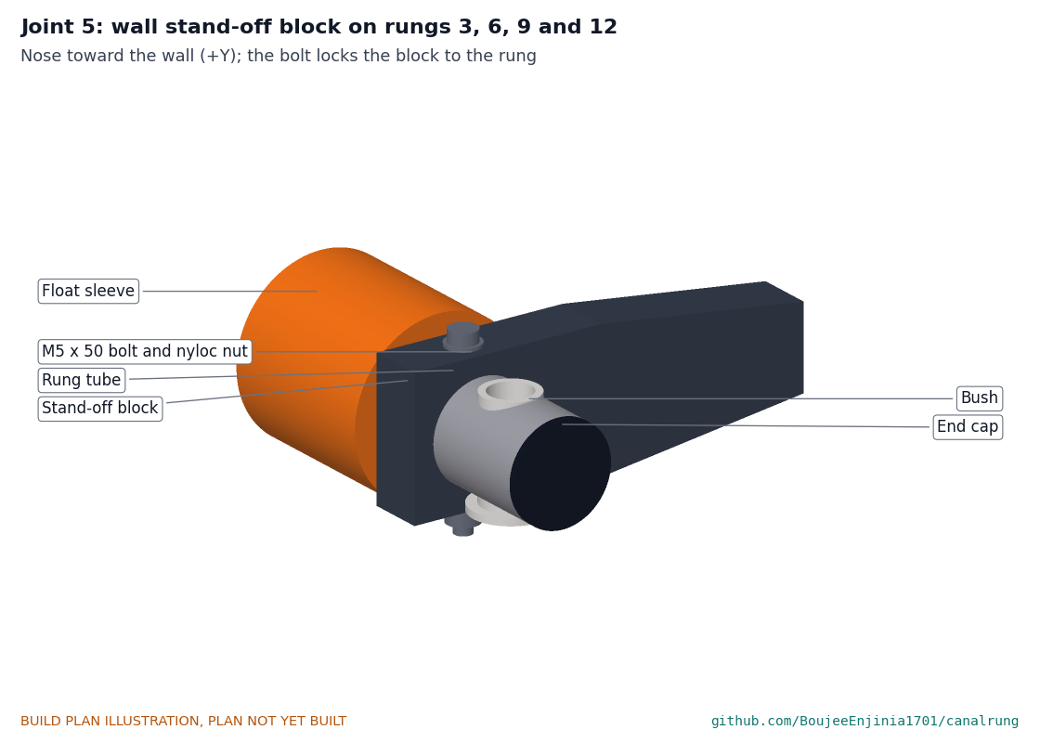
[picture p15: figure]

Figure 13. On a stand-off rung the shorter sleeve sits between the blocks; on a plain rung the longer sleeve sits between the bushes.
The sleeve slides over the rung before the blocks and bushes go on, and sits in the middle with about 2 clear at each end. A bead of polyurethane adhesive inside each end stops it turning on the rung.
Check before moving on. The sleeve grips the rung and does not slide under its own weight.

### 3.8 Wall stand-off blocks (make 8)

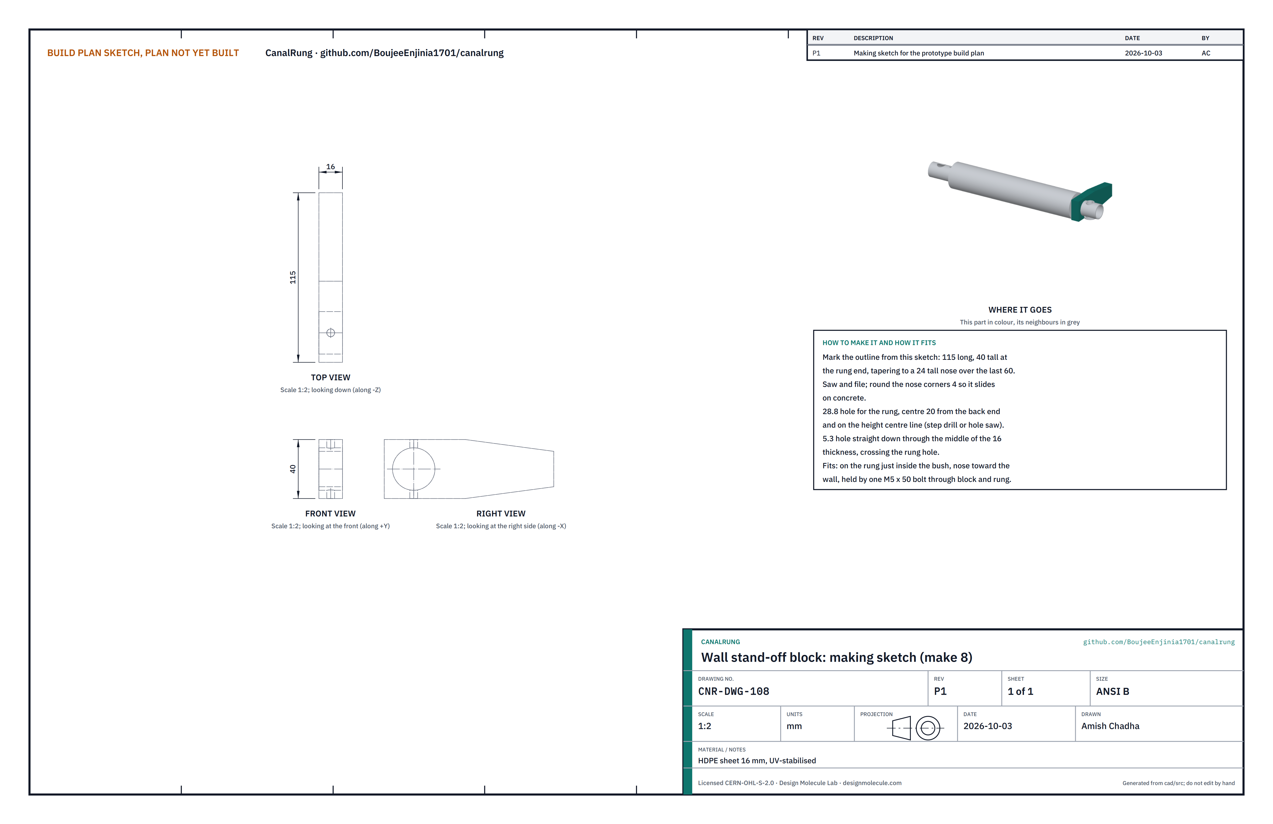
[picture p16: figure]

Figure 14. Stand-off block making sketch (CNR-DWG-108).
What it is and what it is made from. The plastic blocks on rungs 3, 6, 9 and 12 that hold the ladder off the wall so a hand can get behind each rung. HDPE sheet 16 thick, UV-stabilised; one 300 x 150 offcut makes all eight.
How to make it.
Mark the outline on the sheet eight times: 115 long; 40 tall for the first 55 from the back end; then tapering over the last 60 to a 24 tall nose.
Saw just outside the lines and file to them. Round the nose corners to about 4 so the block slides on concrete. Drill a 28.8 hole for the rung, its centre 20 from the back end and on the height centre line (step drill or hole saw, slowly, with the sheet clamped).
Drill a 5.3 hole straight down through the middle of the 16 thickness, crossing the rung hole at its centre.
Deburr with a knife.

How it fits the parts next to it.

1.

2.
3.

4.
5.

Figure 15. The block on the rung, nose toward the wall, locked by an M5 bolt down through the block and the rung. Each block slides onto the rung from its end, after the foam sleeve, and sits just inside the bush with 1 to spare. Its nose points to the wall side. One M5 x 50 bolt goes down through the block and the rung's 5.3 holes, with a washer each side and a nyloc nut underneath. The nose is 95 from the rung's centre, so the foam sleeve stands 70 off the wall.
Check before moving on. On a stand-off rung, both blocks point the same way and lie flat on a table together.

### 3.9 Side ropes (make 2)

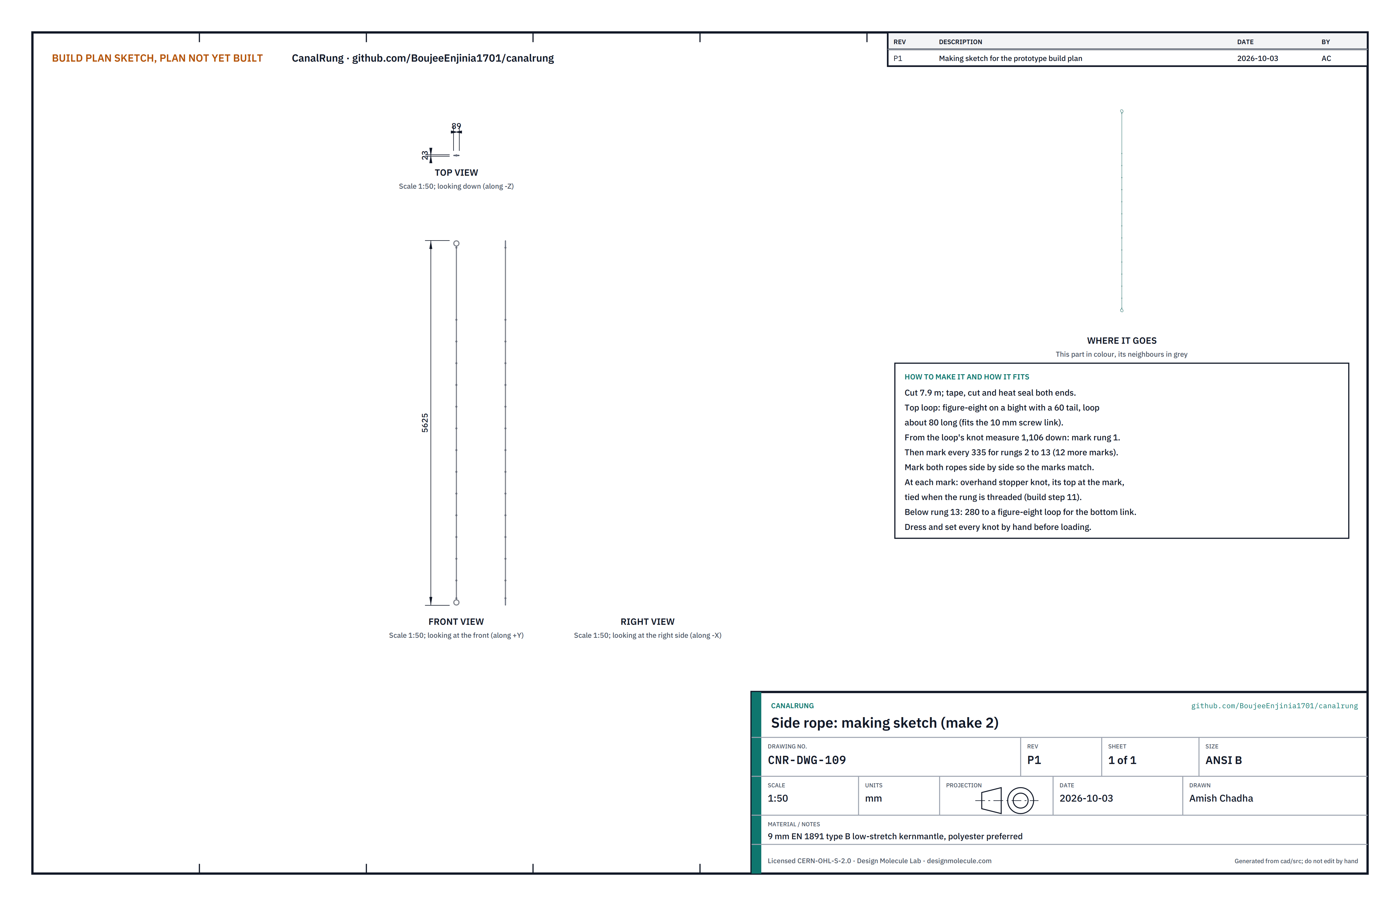
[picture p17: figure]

Figure 16. Side rope making sketch (CNR-DWG-109): the rope finished, laid straight, with its loops and knots.
What it is and what it is made from. The two ropes that carry the rungs and the climber. 9 low-stretch kernmantle rope to EN 1891 type B, with a declared breaking strength of at least 18 kN, polyester if available. 16 m in all. It runs freely through the 12 bore of the bushes, and its stopper knot is still far too big to pull through.
How to make it.
Cut two lengths of 8.0 m: wrap tape round the rope, cut through the tape with a hot knife, and seal each end. Tie a figure-eight on a bight at one end of each rope, with a loop about 80 long and a tail of at least 60. Dress the knot so its strands lie side by side and pull it tight.
Lay both ropes side by side on a clean floor with the loops together. From the loop's knot measure 1,106 along each rope and mark rung 1. Then mark every 335 for rungs 2 to 13: twelve more marks. Use a fine marker or a wrap of tape; the marks must match on both ropes.
Leave the rest of each rope free; the stopper knots are tied as the rungs go on (assembly step 11).

How it fits the parts next to it. Each rope runs down through the bushes at one end of every rung. An overhand stopper knot sits under each bush flange at its mark and carries the rung (Figure 11); a seizing above the bush stops the rung lifting. The top loops go into one screw link on the eye nut (Figure 17); below rung 13 each rope runs 280 to a second figure-eight loop, and both loops and the weight's webbing loop go into the bottom screw link (Figure 18). Where the ropes cross the canal edge they run in sleeves (Figure 19).

1.
2.

3.

4.

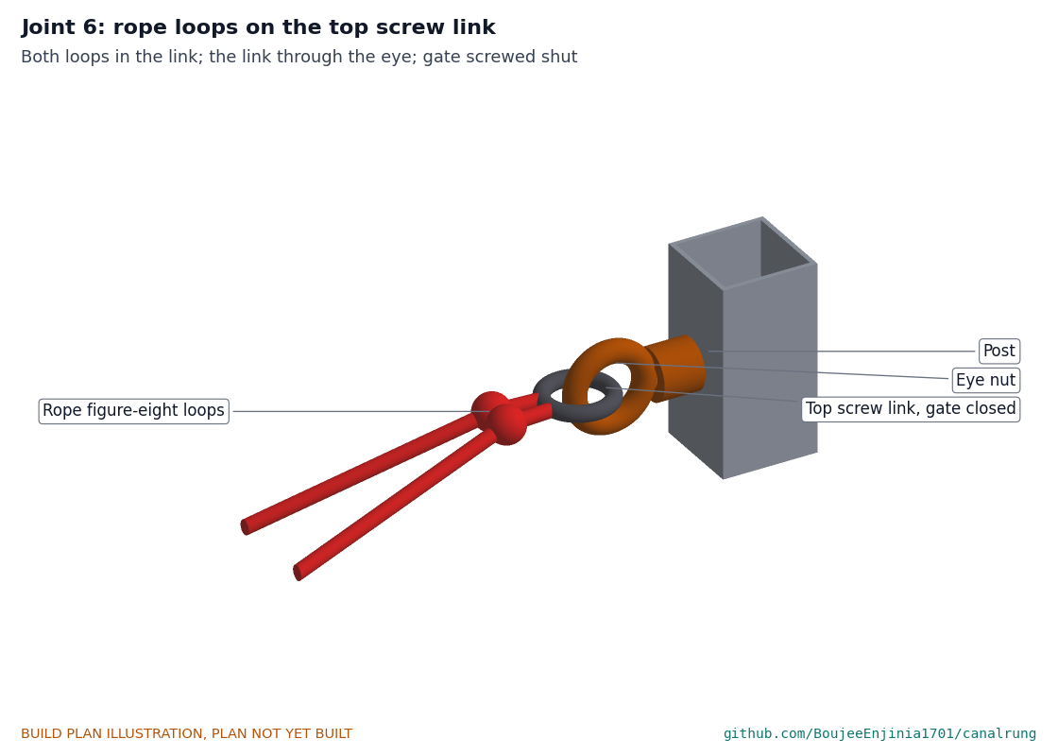
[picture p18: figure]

Figure 17. Both top loops in one screw link; the link through the eye nut's ring; the gate screwed fully shut.

Figure 18. The two rope tails meet in the bottom link 280 below the bottom rung; the soft weight hangs from it on its webbing loop.

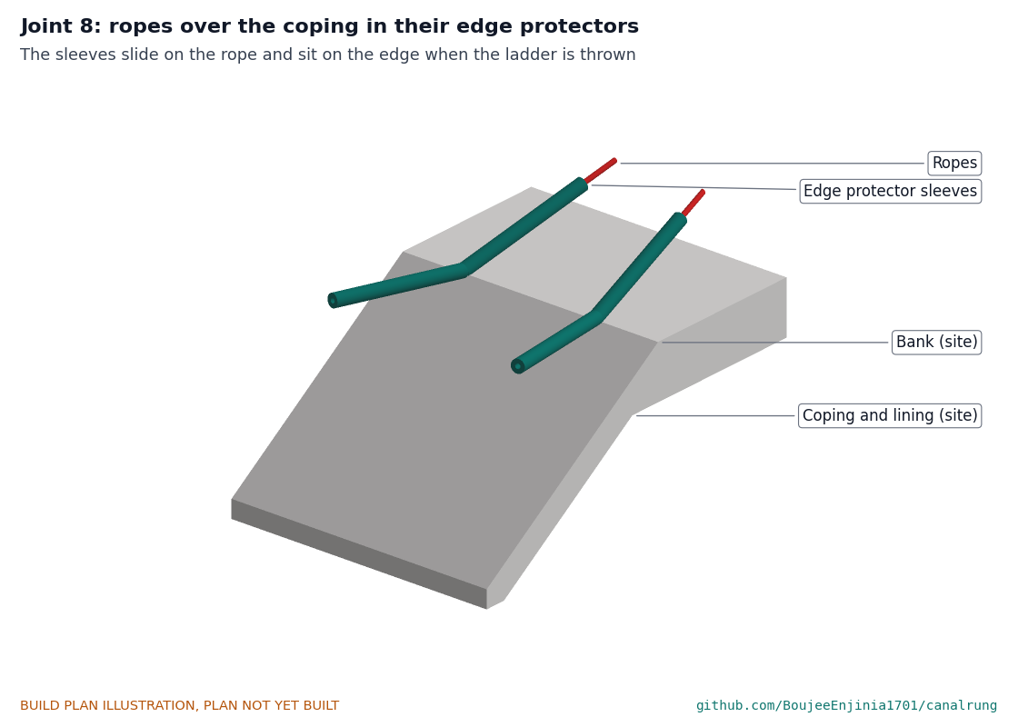
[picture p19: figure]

Figure 19. The edge protector sleeves slide on the ropes and sit on the concrete edge when the ladder is thrown. Check before moving on. Both ropes are the same length to within 20 between the loop knot and the last mark; every mark is 335 from the next within 3.

### 3.10 Bought components

Component | What to buy | What to do to it
Anchor bolt set | M16 x 90 hex bolt, grade 8.8, galvanised; one 50 outside x 4 washer and one 30 outside x 3 washer; high-strength threadlocker | Nothing
Forged eye nut | M16 forged steel eye nut, DIN 582 class, marked with a working load limit of at least 700 kg | Check the marking; reject any unmarked or cast eye
Square U-bolts (2) | M8 square U-bolt for 60 square tube, 80 usable leg, with nuts | Nothing
Box fixings (4) | M8 nyloc nut and 30 outside fender washer, stainless | Nothing
Post cap | Plastic cap for 60 square tube | Nothing
Decals and tamper tag | UV-laminated vinyl: a pictogram how-to for the lid (open, throw upstream, never go in) and a front warning (do not enter the water, call the emergency number, not a seat); a numbered plastic tamper tag | Apply to clean, dry plastic
Rescue knife | Blunt-tip rope rescue knife with a sheath | Tether it under the lid with a cable tie through the sheath
Rope bushes (26) | Nylon flanged sleeve bush, 12 bore, 16 outside, 22 flange x 2, 30 long | Trim to 29 long with a knife so the top sits just proud of the rung
Rung end caps (26) | Plastic insert plug for 28.6 x 1.65 tube | Trim the insert to 10 long if longer, so it stops short of the rope hole
Stand-off bolts (8) | M5 x 50 stainless A2-70 bolt, two washers, one nyloc nut | Nothing
Seizing twine | Waxed polyester whipping twine, about 1 | Nothing
Screw links (2) | 10 steel screw link (maillon), marked with a working load limit of at least 1,000 kg, about 60 inside length | Check the marking and that the gate closes fully
Soft throw weight | 0.5 kg fabric pouch of lead-free steel shot with a sewn webbing loop, bright colour | Nothing
Edge protector sleeves (2) | PVC-coated polyester rope protector, hook-and-loop, 500 long, for 9 to 13 rope | Nothing

### 4. Putting it together

The station (steps 1 to 7) and the ladder (steps 8 to 14) can be built at the same time; steps 15 and 16 join them. The ladder pictures show 4 of the 13 rungs. In the step pictures, parts already fitted are grey and the parts being fitted are in colour, with a red arrow showing the way they go in.

Step 1: stand the post in the hole

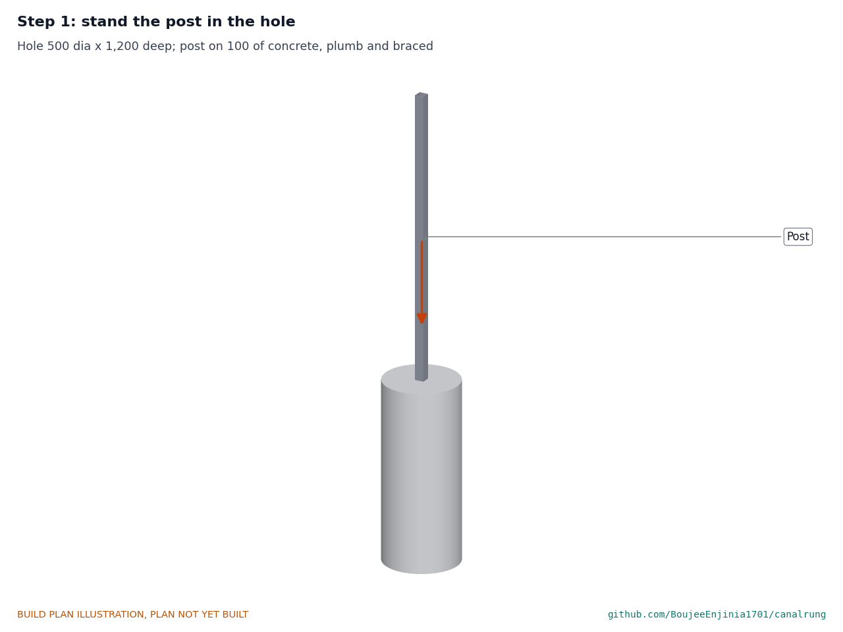
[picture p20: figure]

Pour the 100 of concrete into the base of the hole and level it. Stand the post on it with the canal-side face toward the canal and the ground line level with the ground. Plumb it both ways and brace it with two timber battens and clamps.

Step 2: pour the footing

Fill the hole in layers of about 200, rodding each one, up to just above the ground; slope the top away from the post. Check plumb again after each layer. Hold point: leave 7 days, kept damp, before anything is fixed to the eye nut.

Step 3: crush tube into the post

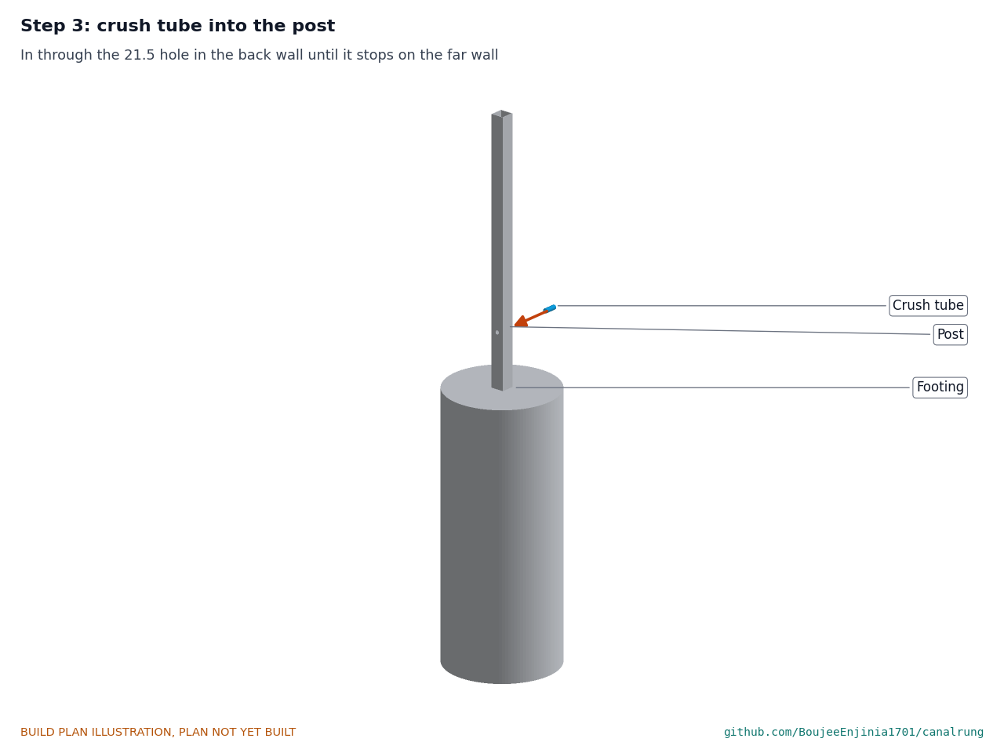
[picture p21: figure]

Slide the crush tube into the 21.5 hole in the back wall until it stops on the inside of the canal-side wall. Its end should be flush with the back face.

Step 4: anchor bolt and eye nut

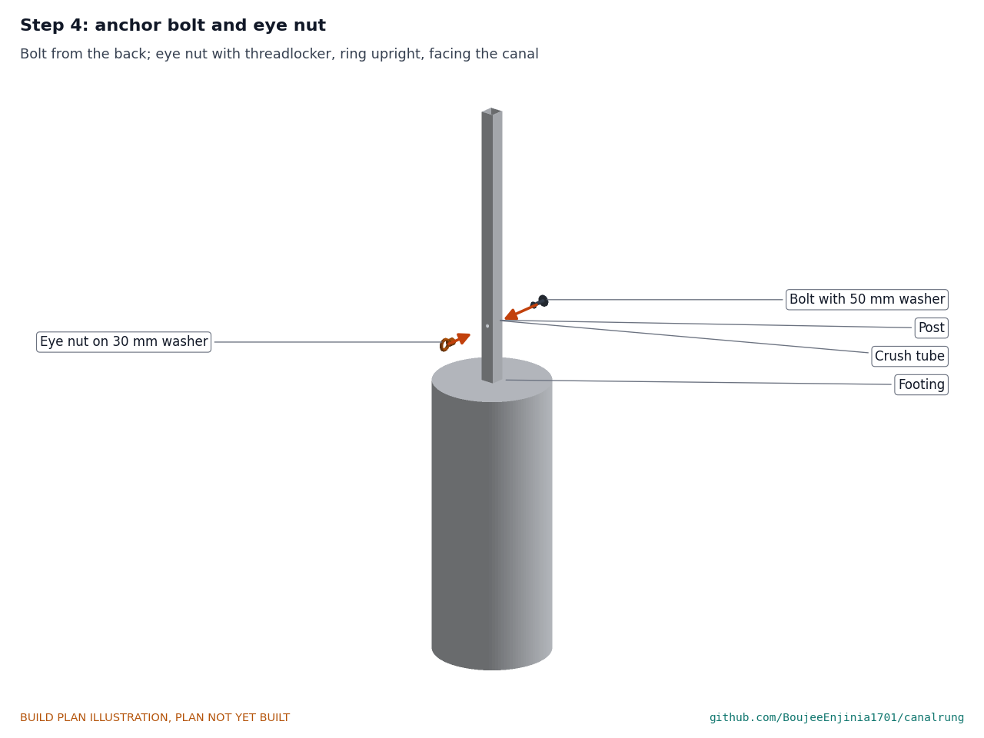
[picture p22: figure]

Put the 50 washer on the bolt and push the bolt in from the back, through the crush tube and out of the canal-side hole. Put the 30 washer on the bolt on the canal side. Put two drops of high-strength threadlocker on the thread and screw on the eye nut by hand until it is tight on the washer with its ring upright (in line with the canal-side face, standing vertical). Hold the eye nut and tighten the bolt head with a 24 spanner until firm; the ring must end upright. Hold point: leave the threadlocker 24 hours before loading.

Step 5: mounting plate and U-bolts

Hold the plate on the canal-side face, centred, its bottom edge 480 above the ground. Pass the two U-bolts round the back of the post and through the plate's holes, the lower one through the lower pair.

Step 6: box onto the U-bolt legs

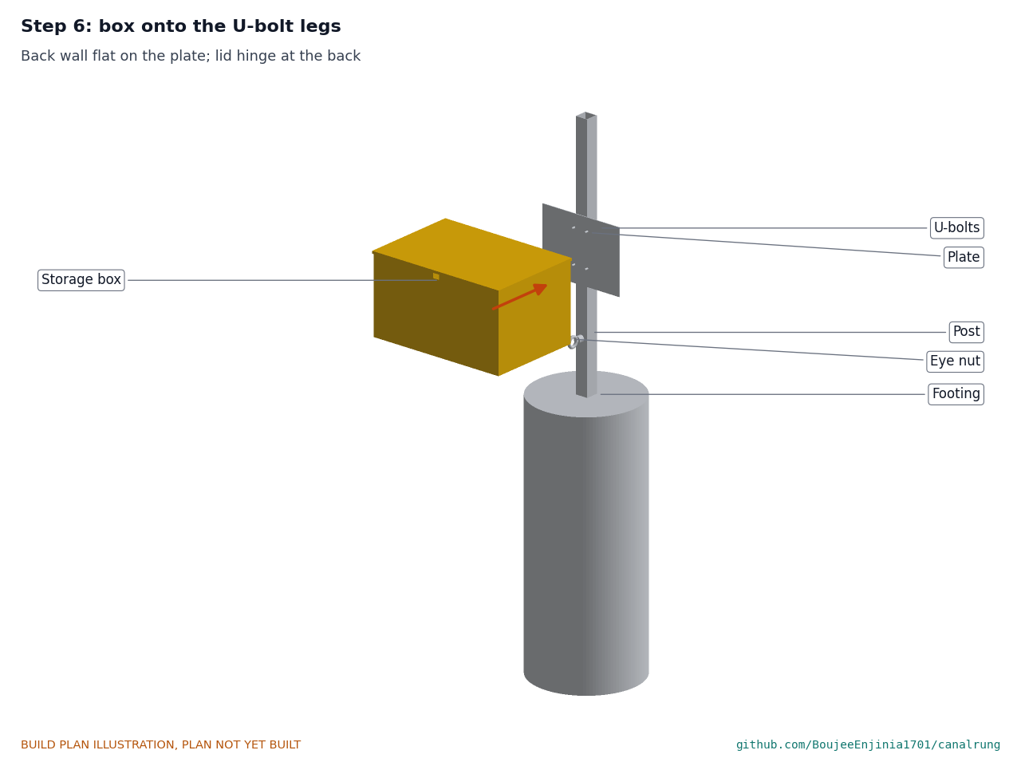
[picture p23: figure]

Lift the box onto the four U-bolt legs through the holes in its back wall, lid hinge at the back, until the back wall sits flat on the plate.

Step 7: box fixings, post cap, decals and knife

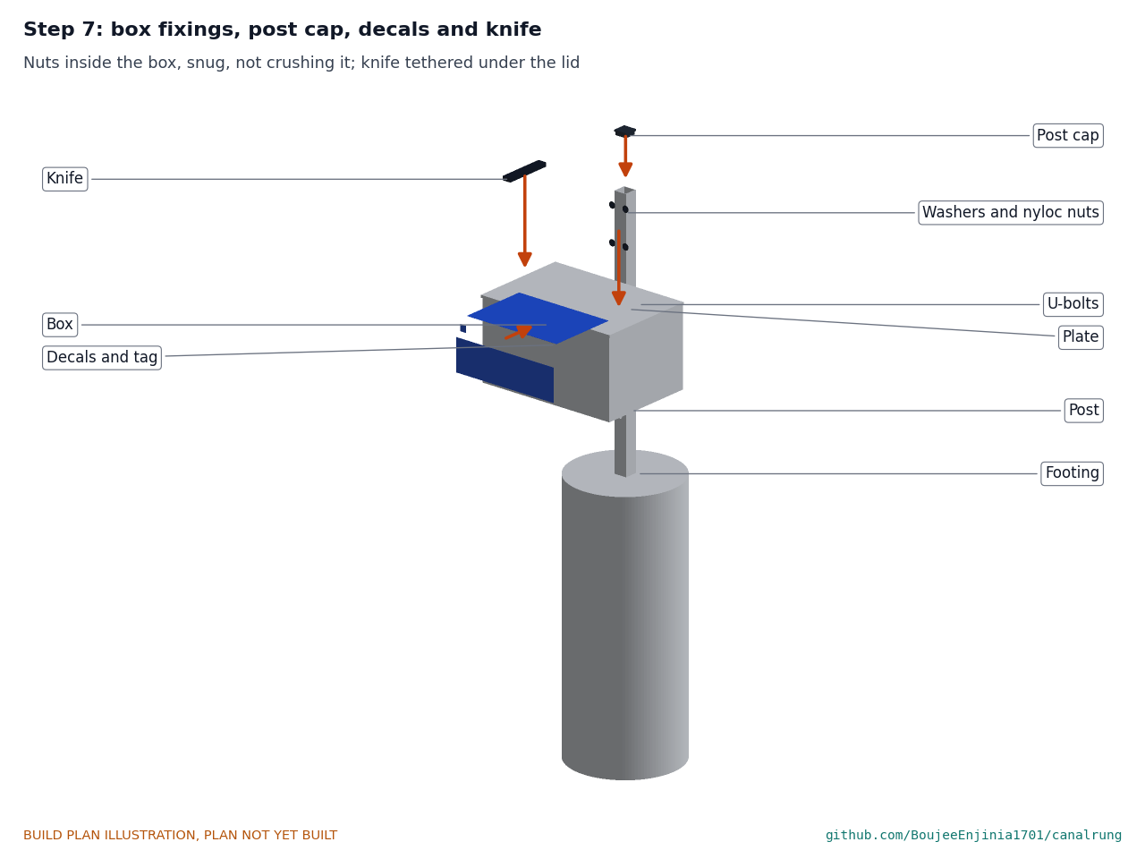
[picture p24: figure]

Inside the box, put a fender washer and a nyloc nut on each U-bolt leg and tighten them evenly with a 13 spanner until the box is firm on the plate and the plate on the post; stop before the plastic dishes. Tap the cap onto the post. Apply the decals and fit the tamper tag. Tether the knife under the lid.

Step 8: float sleeves onto the rungs

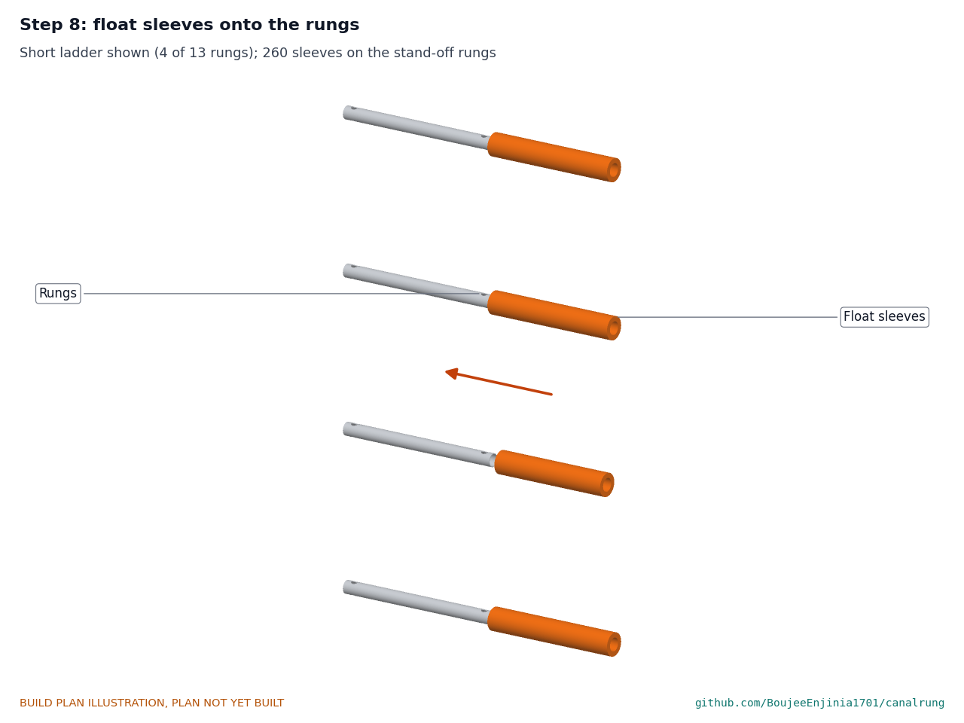
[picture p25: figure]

Slide a 294 sleeve onto each plain rung and a 260 sleeve onto each stand-off rung (3, 6, 9 and 12), with a bead of adhesive inside each end, and centre it.

Step 9: stand-off blocks on rungs 3, 6, 9 and 12

On each stand-off rung, slide a block onto each end, nose toward the same side, up to the sleeve. Line up the block holes with the rung's 5.3 holes and put an M5 bolt down through each with a washer under the head; washer and nyloc nut underneath; tighten until the block does not turn. All the noses point to the wall side.

Step 10: rope bushes and end caps

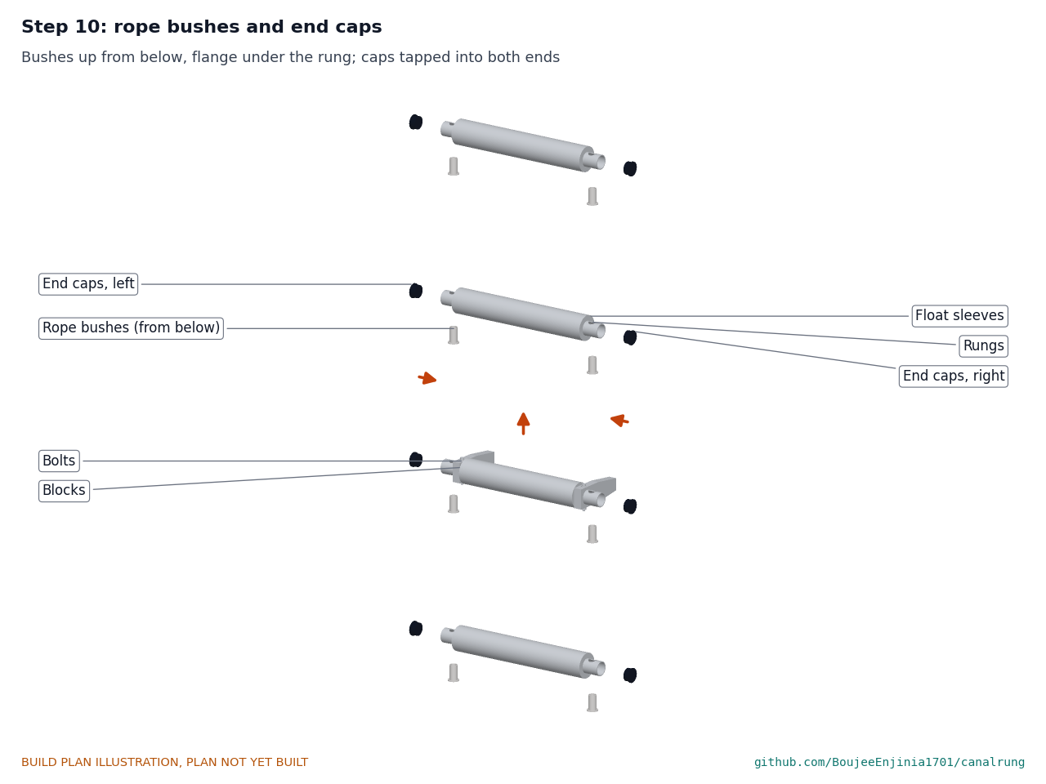
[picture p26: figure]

Push a bush up into each rope hole from below until its flange sits on the rung; its top should be just proud of the top of the rung. On stand-off rungs, check the "below" side matches the other rungs: with the noses pointing away from you, the flanges are on the underside. Tap an end cap into each end of every rung.

Step 11: thread the ropes and tie the knots

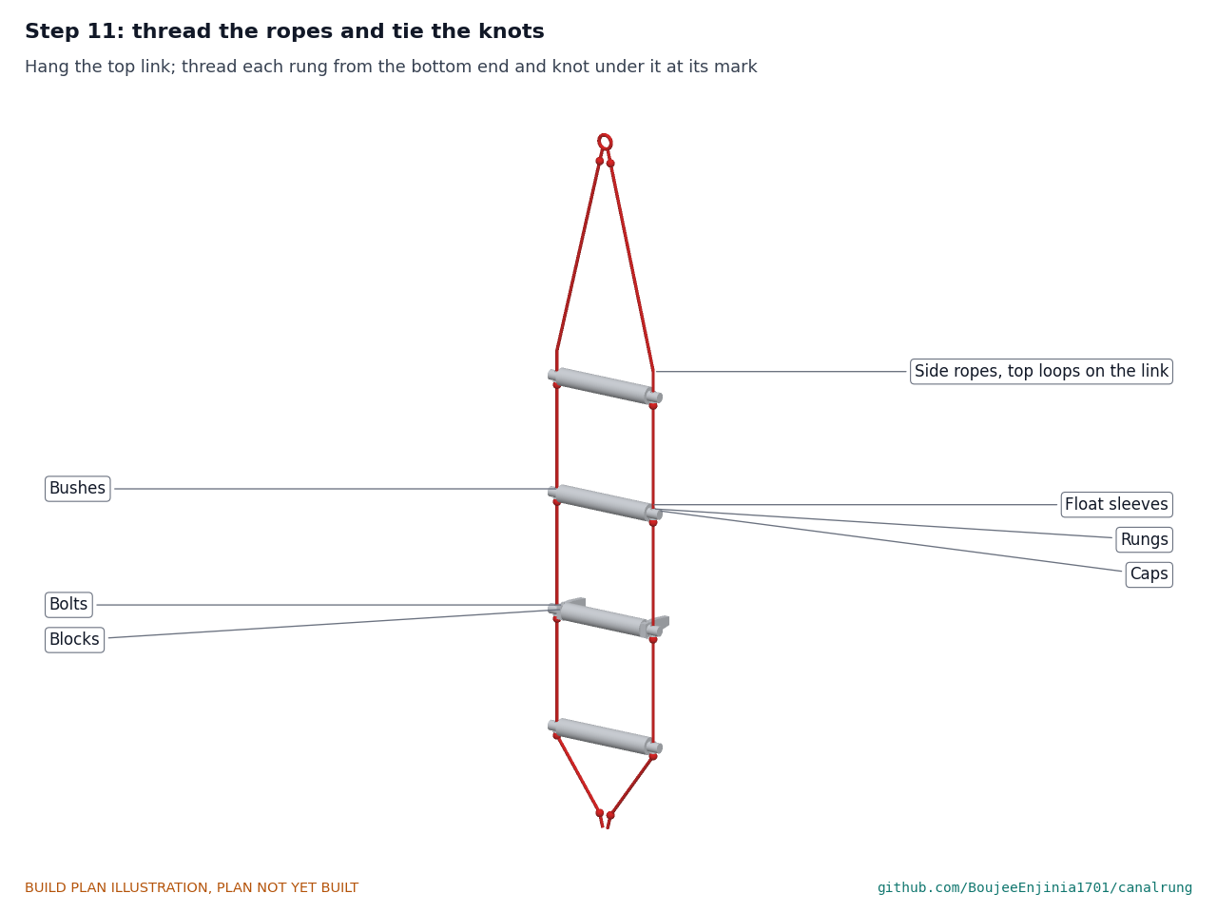
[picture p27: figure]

Hang both top loops on the top screw link from a beam or strong hook, or lay the ropes out on a clean floor. Take rung 1. Pass the free end of the left rope up through the bush at the left end of the rung from below, and the right rope through the right end, and slide the rung up to the rung 1 marks. Tie an overhand stopper knot in each rope just under the bush flange so the top of the knot sits on the mark, and pull it tight; the rung must sit level. Repeat for rungs 2 to 13 in order, threading each from the free ends. Keep the stand-off noses all on the same side. Below rung 13, measure 280 and tie a figure-eight on a bight in each rope for the bottom link.

Step 12: seizings above every rung end

At each rung end, just above the bush, whip the rope tightly with the twine for 20, then tuck and pull the end under the turns. The seizing must not slide when pushed with a thumb. There are 26 seizings.

Step 13: bottom link and throw weight


Open the bottom screw link, put both bottom loops and the throw weight's webbing loop in it, and screw the gate fully shut by hand, then a quarter turn with a spanner.

Step 14: edge protectors on the top lead


Wrap one sleeve round each rope between rung 1 and the top link, about 200 above rung 1, and close the hook-and-loop. They slide along the rope to wherever it crosses the edge.

Step 15: top link onto the eye nut

Take the top screw link with both rope loops in it, open its gate, pass it through the eye nut's ring and screw the gate fully shut, then a quarter turn with a spanner. Lead the ropes from the eye nut under the box, up its front and in through the rim notch.

Step 16: fold the ladder into the box


Open the lid. Fold the ladder into the box rung by rung, starting from the top (rung 1 at the bottom of the box) in three stacks across the box, with the ropes lying between the stacks and no rope crossing over a rung. Coil the tail and put the throw weight on top, where a hand finds it first. Close the lid over the ropes in the notch, latch it and fit the tamper tag.

### 5. First checks

The plan lists them; a TRL 4 test report records them. Each is done only when the safety stops in section 6 allow it. Table 2. First checks.

Check | Requirement How | Pass when

Post plumb and
firm
| R6 | Spirit level on two faces after 7 days; push hard at the top | Plumb within 5 in 1,000; no movement felt
Ladder mass | R2 | Weigh everything that leaves the box on a hanging scale | Recorded; the target is 4.5 kg and the estimate 4.27 kg
Knots and rungs level | R4, R5 | Hang the ladder by its top link; sight along the rungs | Every rung level within 10 end to end; pitch 335 within 10
Rung proof load R4 | Ladder hung from a test frame (CalRig); 1.5 kN at
| | the middle of each rung for 1 min, by weights | No visible bend afterward (under 1 at the middle); no knot slip over 10
Ladder system proof load | R4 | 4.5 kN through the top link to the bottom rung, pulled by a calibrated rig | Holds 3 min; no damage to rope, knots, bushes or links
Anchor proof load | R6 | 4.5 kN on the eye nut toward the canal, at ground height, after 7 days' cure, with a calibrated rig | Holds 3 min; top of post moves under 10; no cracks at the footing
Floats | R3 | Ladder with its weight laid in a test tank | Every rung floats; the weight hangs below the bottom rungs
Throw | R2 | Ten untrained adults throw on dry land to a target 3 m away | 8 of 10 land within 1 m
Deploy time | R7 | Untrained volunteers, pictogram only, from closed box to ladder at the bottom of a test wall | Under 30 s
Climb | R5 | Adult volunteer in a 1.5 deep test tank with a smooth vertical wall, lifeguards present | Out in under 60 s
Box | R8 | Hose the closed box for 5 min; open it | Water drains out; the lid closes over the ropes
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

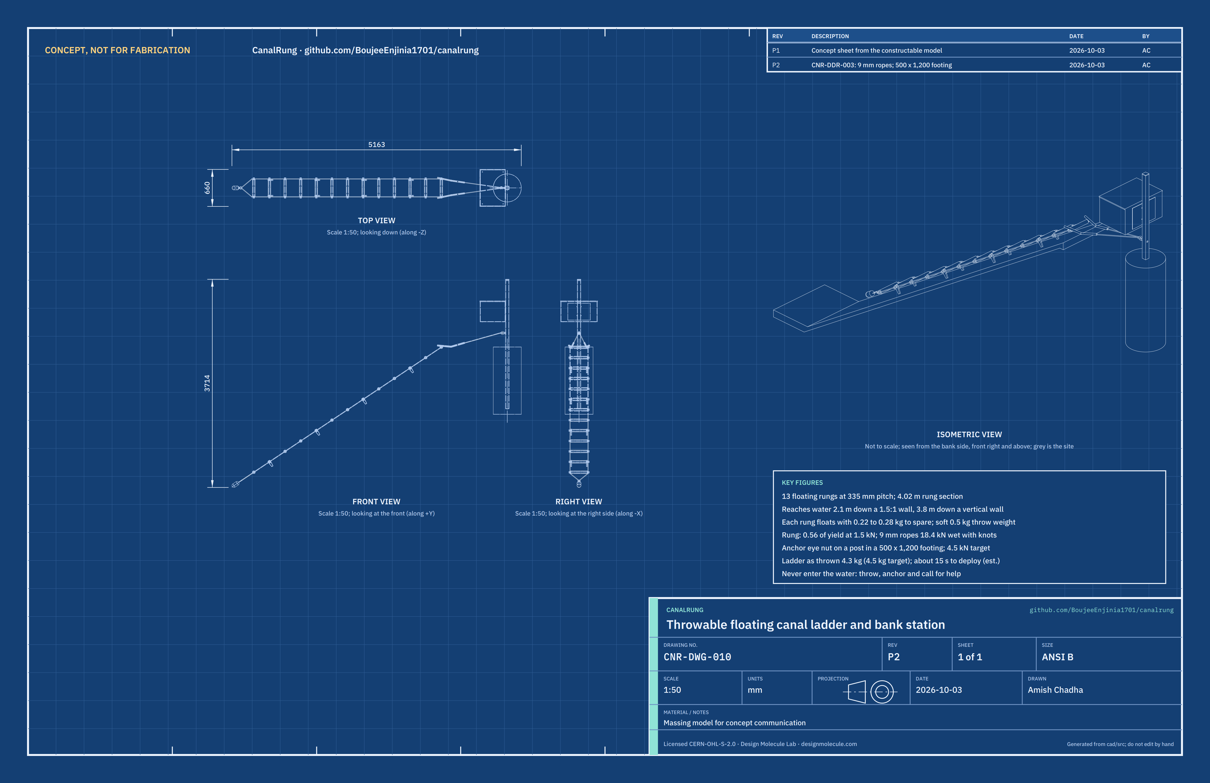
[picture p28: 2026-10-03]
media/concept-blueprint.png

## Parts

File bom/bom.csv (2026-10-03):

item | qty | spec | supplier | unit_cost_usd | make_buy | notes
1 Post | 1 | Hot-dip galvanised steel square hollow section 60 x 60 x 3 mm, S235 or better, cut to 2,300 mm; a 17.5 mm hole in the canal-side wall and a 21.5 mm hole in the back wall on one axis, 1,350 mm from the bottom end; cold galvanising paint on cut ends and hole | Steel stockholder or fencing supplier | 52.60 | make | Indicative price: the 2.1 m price of USD 48 pro rata to 2.3 m; 1,100 mm set in the footing, 1,200 mm above ground (CNR-DDR-003)
2 Concrete footing | 1 | 500 mm diameter x 1,200 mm deep hole in the bank, the standard footing at every site; about 0.23 m3 of 25 MPa ready-mix or bagged concrete (about 22 bags of 25 kg), with 100 mm of concrete under the post | Builders' merchant | 143.00 | make | Indicative price: 22 bags at USD 6.50, the same bag price as the earlier 12-bag footing; checked for 4.5 kN in drained and in saturated granular soil (CNR-CAL-001, G4 and G5; CNR-DDR-003)
3 Crush tube | 1 | Steel tube 21.3 x 2.0 mm (1/2 in pipe class), cut to 57 mm, ends square; slides in through the 21.5 mm hole in the back wall and bears on the inside of the canal-side wall, so the anchor bolt can be tightened without crushing the post | Steel stockholder or plumbing supplier | 3.00 | make | Offcut price
4 Anchor bolt set | 1 | M16 x 90 hex bolt, grade 8.8, hot-dip galvanised; one 50 mm OD x 4 mm and one 30 mm OD x 3 mm washer; high-strength threadlocker | Fastener supplier | 6.00 | buy | Bolt runs through the crush tube; head and 50 mm washer on the back face of the post, covering the crush tube end
5 Forged eye nut | 1 | M16 forged steel eye nut to DIN 582 class or equivalent, working load limit at least 700 kg in line with the thread, galvanised, marked with its rating | Lifting gear supplier | 12.00 | buy | Ladder anchor; loaded in line with its thread (CNR-CAL-001, G1)
6 Box mounting plate | 1 | Aluminium sheet 5052 or 6061, 4 mm, cut to 400 x 300 mm; four 9 mm holes for the U-bolts | Metal supplier, cut to size | 22.00 | make | Spreads the clamp load over the box back
7 Square U-bolts | 2 | M8 square U-bolt for 60 mm square tube, 80 mm usable leg, stainless or galvanised, with nuts | Fastener or fencing supplier | 5.00 | buy | Legs pass through the plate and the box back wall
8 Storage box | 1 | Polypropylene or polyethylene storage box about 70 L, about 450 x 650 x 360 mm outside (D x W x H), UV stabilised, bright yellow or orange, hinged lid with clip latches and no lock; drilled for four U-bolt legs and four drain holes, with a 30 x 25 mm rope notch in the front rim | Hardware or storage retailer | 45.00 | buy | Size must take a 370 mm rung across its depth; to confirm when bought (CNR-DEC-001)
9 Box fixings | 4 | M8 nyloc nut and 30 mm OD x 1.5 mm fender washer, stainless | Fastener supplier | 0.80 | buy | Inside the box on the U-bolt legs
10 Post cap | 1 | Plastic cap for 60 x 60 mm square tube, UV stabilised | Fencing supplier | 2.00 | buy
11 Decals and tamper tag | 1 | UV-laminated vinyl decals: pictogram how-to on the lid, warning on the front (do not enter the water, call the emergency number, not a seat); numbered plastic tamper tag on the latch | Sign printer | 22.00 | buy
12 Rescue knife | 1 | Blunt-tip rope rescue knife with a sheath, tethered under the lid | Water rescue supplier | 20.00 | buy | For cutting rope if anyone becomes caught in it
13 Rungs | 13 | Aluminium 6061-T6 round tube 28.6 x 1.65 mm (1-1/8 x 0.065 in), cut to 360 mm; two 16 mm holes across each rung 20 mm from the ends; stand-off rungs 3, 6, 9 and 12 also get two 5.3 mm holes 40 mm from the ends | Metal supplier (tube sold in 2.4 m or 6 m lengths) | 5.60 | make | About 4.7 m of tube in all; price per rung
14 Float sleeves | 13 | Closed-cell cross-linked polyethylene foam tube, 50 mm outside, 28 mm bore, about 33 kg/m3, orange; nine cut to 294 mm and four cut to 260 mm (about 3.7 m in all) | Foam or pipe insulation supplier | 1.20 | make | Closed-cell grade only, so it cannot soak up water; price per sleeve
15 Wall stand-off blocks | 8 | HDPE sheet 16 mm, natural or black UV-stabilised, cut to the block outline (115 x 40 mm, nose 24 mm high); 28.8 mm rung hole and 5.3 mm bolt hole | Plastics supplier, offcut | 3.00 | make | One 300 x 150 mm offcut makes all eight
16 Stand-off bolts | 8 | M5 x 50 stainless A2-70 hex bolt, two washers and one nyloc nut | Fastener supplier | 0.60 | buy
17 Rope bushes | 26 | Nylon (PA6) flanged sleeve bush, 12 mm bore, 16 mm outside, 22 mm flange x 2 mm, 30 mm long trimmed to 29 mm | Bearing or plastics supplier | 0.80 | buy | Protects the rope from the aluminium hole edges; flange goes on the underside
18 Rung end caps | 26 | Plastic insert plug for 28.6 x 1.65 mm round tube, UV stabilised | Tube fittings supplier | 0.40 | buy
19 Side ropes | 2 | 9 mm low-stretch kernmantle rope to EN 1891 type B, polyester preferred, declared minimum breaking strength at least 18 kN, about 55 g/m, cut to 8.0 m each (16 m in all), ends heat sealed | Rope or work-at-height supplier | 16.00 | make | Indicative price: about USD 2.00 per metre for 9 mm type B rope cut from the reel (catalogue range about USD 1.80 to 2.40); one overhand stopper knot under each rung end and a figure-eight loop at each end (CNR-CAL-001, E1; CNR-DDR-003)
20 Seizing twine | 1 | Waxed polyester whipping twine, about 1 mm, one small roll | Chandlery or rope supplier | 8.00 | buy | Seizing 20 mm long above each rung end
21 Screw links | 2 | 10 mm zinc-plated steel screw link (maillon), marked with a working load limit of at least 1,000 kg | Lifting gear or climbing supplier | 8.00 | buy | Top link on the eye nut; bottom link to the throw weight
22 Soft throw weight | 1 | 0.5 kg soft weight: a fabric pouch filled with lead-free steel shot, with a sewn webbing loop, bright colour | Dive or rescue supplier | 15.00 | buy | Soft, so it cannot injure a person if it lands near them; thrown upstream, never at the person
23 Edge protector sleeves | 2 | Rope protector sleeve, PVC-coated polyester, hook-and-loop closure, 500 mm long, for 9 to 13 mm rope | Rope access or arborist supplier | 15.00 | buy | Where the ropes cross the coping
24 Consumables | 1 | Cold galvanising paint, polyurethane adhesive, heat-shrink or tape for rope ends, marker, cable ties | Hardware store | 15.00 | buy

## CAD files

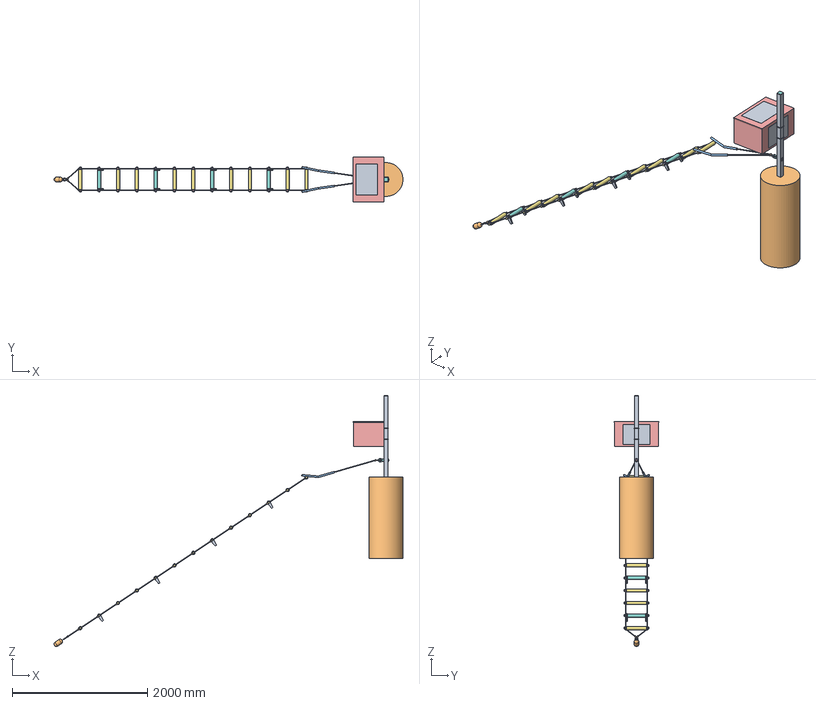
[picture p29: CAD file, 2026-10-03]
cad/step/canalrung-assembly.step
5162.5 x 660.0 x 3713.8 mm

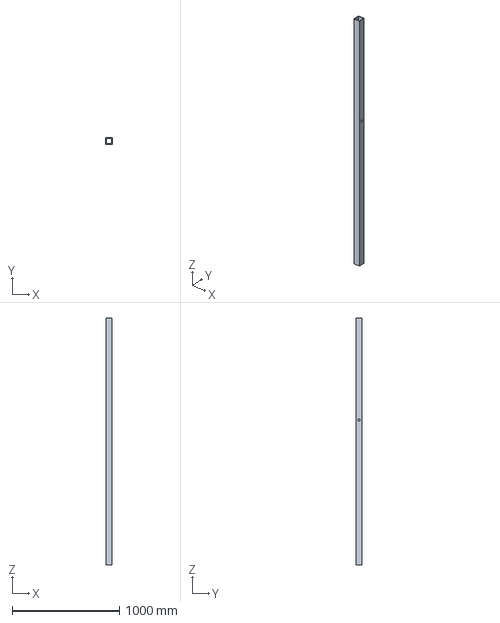
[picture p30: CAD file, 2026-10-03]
cad/step/post.step
60.0 x 60.0 x 2300.0 mm

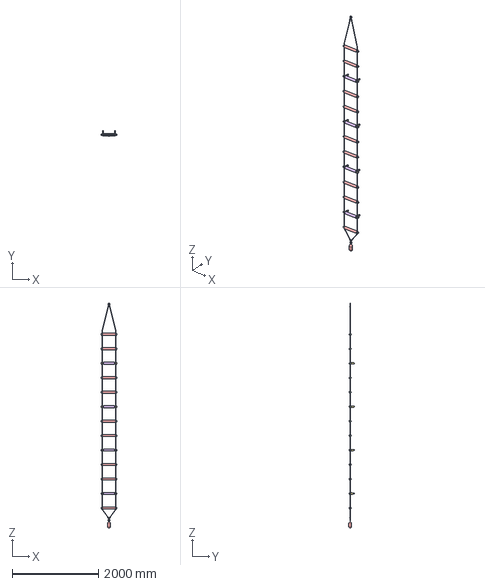
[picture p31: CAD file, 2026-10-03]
cad/step/canalrung-ladder.step
364.0 x 130.0 x 5207.0 mm

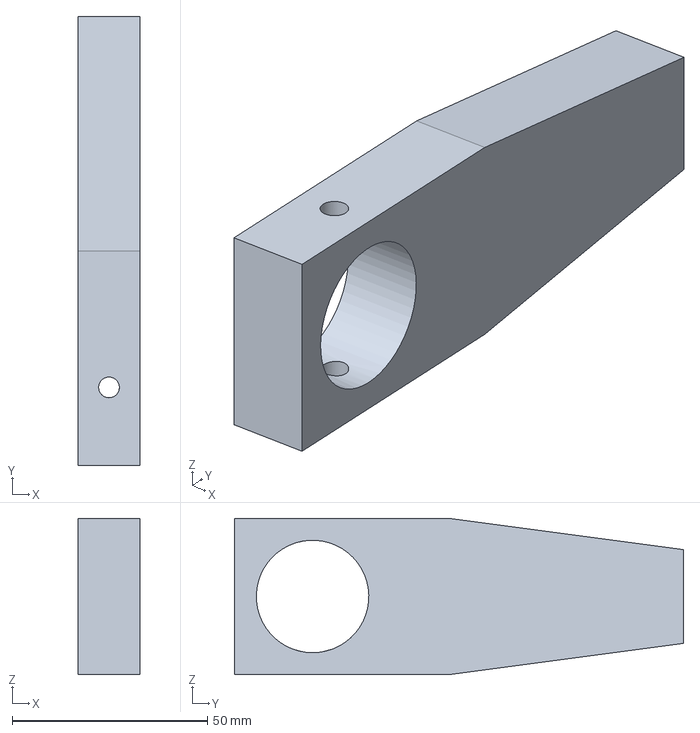
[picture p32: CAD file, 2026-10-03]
cad/step/standoff-block.step
16.0 x 115.0 x 40.0 mm

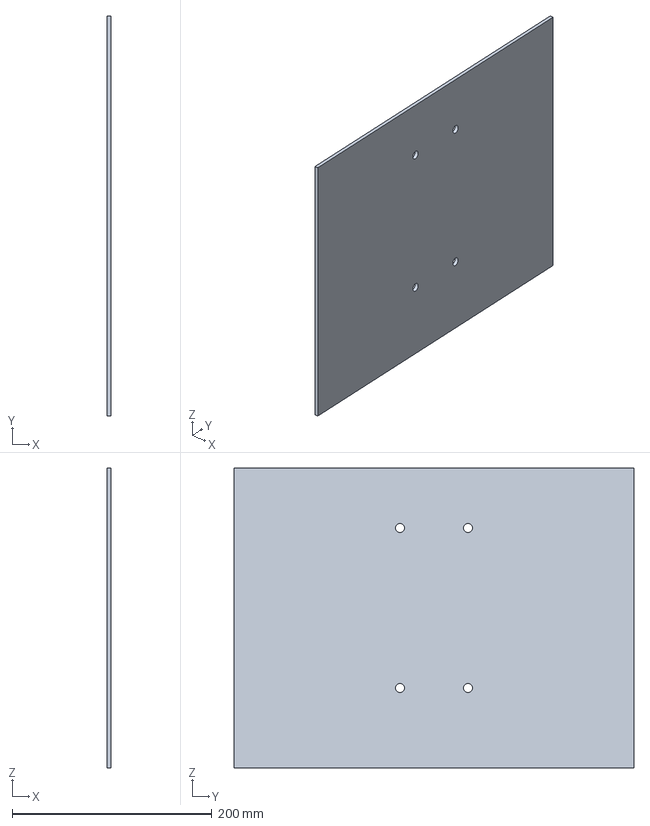
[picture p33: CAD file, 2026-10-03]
cad/step/mounting-plate.step
4.00 x 400.0 x 300.0 mm

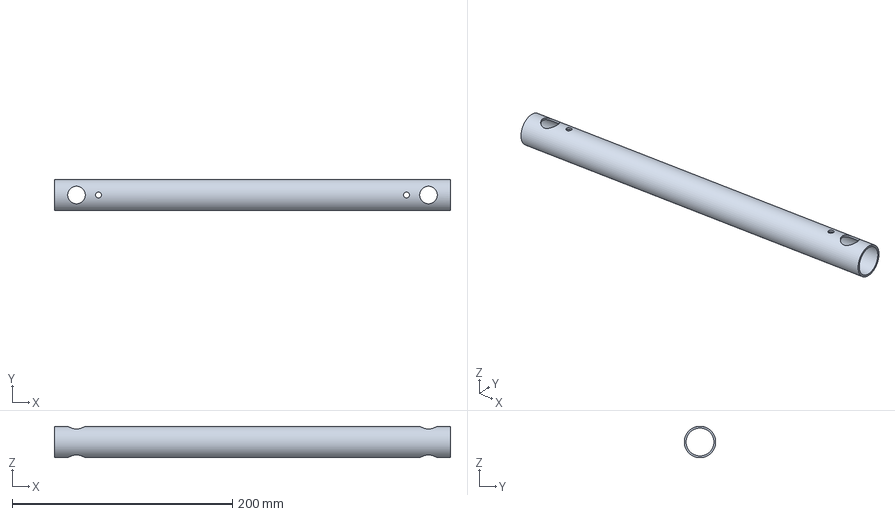
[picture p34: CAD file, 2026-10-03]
cad/step/rung.step
360.0 x 28.6 x 28.6 mm

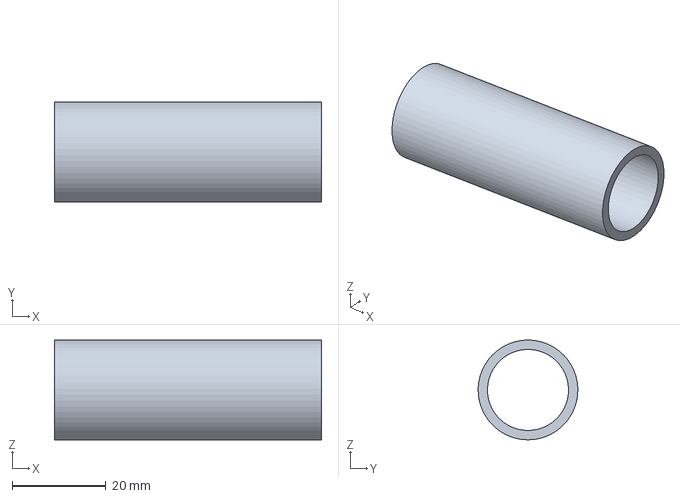
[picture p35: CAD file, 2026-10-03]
cad/step/crush-tube.step
57.0 x 21.3 x 21.3 mm

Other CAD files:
cad/stl/crush-tube.stl
cad/stl/mounting-plate.stl
cad/stl/post.stl
cad/stl/rung.stl
cad/stl/standoff-block.stl

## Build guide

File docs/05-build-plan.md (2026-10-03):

---
doc_id: CNR-BLD-001
title: CanalRung prototype build plan
project: CanalRung
doc_type: Build plan
version: "0.2"
status: Draft
date: '2026-10-03'
author: Amish Chadha
license: CERN-OHL-S-2.0
revisions:
  - version: "0.1"
    date: '2026-10-03'
    author: Amish Chadha
    change: First build plan; design made constructable (CNR-DDR-002)
  - version: "0.2"
    date: '2026-10-03'
    author: Amish Chadha
    change: "Amish's decisions of 2026-10-03 (CNR-DDR-003): 9 mm ropes; the 500 x 1,200 footing and 2,300 post at every site"
---

# CanalRung prototype build plan

**Plan, not yet built.** How to build the first proof-of-concept prototype, component by component. Building and testing to it is TRL 4 work. Decisions still to be made are kept in the design decisions register ([docs/06-design-decisions.md](06-design-decisions.md)), not here.

## 1. What you are building

Figure 1. Every component, pulled apart and numbered in build order

*Figure 1. Every component pulled apart and numbered in build order. The ladder is drawn with 4 of its 13 rungs so the parts stay readable.*

The prototype is one CanalRung station and its ladder. The station is a galvanised steel post set in a concrete footing a metre back from the canal edge, with a forged eye nut near its foot that anchors the ladder and a bright plastic box clamped to it that holds the ladder. The ladder is 13 aluminium tube rungs, each in an orange foam float sleeve, hung on two red climbing-grade ropes by a knot under each rung end, with plastic stand-off blocks on four rungs, a soft weight at the bottom and a screw link at each end. Figure 1 shows the 23 components in the order you make or fit them. Nine are made in a small workshop or on site: the post, the footing, the crush tube, the mounting plate, the drilled box, the rungs, the float sleeves, the stand-off blocks and the ropes. The rest are bought and fitted. The work is cutting and drilling steel and aluminium tube, cutting aluminium sheet, plastic and foam, digging and pouring a small footing, and rope work: cutting, sealing, tying knots and seizing. The parts cost about USD 605, from the bill of materials.

> **Safety:** CanalRung is rescue and rope equipment that a person's life will depend on. Build it carefully, inspect every knot, and never let anyone climb it, stand on it or test it in water until section 6 says so. Work at the canal edge only with a second person watching and a life jacket on; dig only after underground services have been located. Cut tube and sheet edges are sharp: deburr everything and wear gloves. Heat sealing rope ends gives off fumes; do it in a ventilated space.

## 2. What changed to make it buildable

The concept showed what CanalRung does; some of its parts could not be made or fixed as drawn. Each change below keeps what the ladder does, and all are recorded in decision record CNR-DDR-002.

*Table 1. Changes from the concept.*

| Component | The concept had | The buildable design has | Why |
| --- | --- | --- | --- |
| Rung to rope | Rungs "fixed at even spacing", no joint | The rope runs through a bushed hole in each rung end; a knot under the rung carries it and a seizing over it stops it floating up (Figure 11) | The classic rope ladder joint, made with hand tools and checked by eye |
| Wall spacers | Spacers on some rungs, no fixing | Plastic blocks on rungs 3, 6, 9 and 12, each locked by one M5 bolt through block and rung (Figure 15) | They cannot slide or turn |
| Floats | "Buoyant rungs" | A closed-cell foam sleeve on every rung, cut to fit between the bushes or blocks (Figure 13) | Known buoyancy; the sleeve length is set by the parts beside it |
| Tube ends | Open | Plastic end caps that stop short of the rope hole | No sharp or open ends |
| Anchor | Stake, post loop or cross bar | Forged eye nut on a bolt through the post, with a crush tube inside (Figure 6) | A fixed anchor that holds 4.5 kN; the post walls do not crush |
| Box | On the post, no fixing | An aluminium plate and two U-bolts round the post; the U-bolt legs pass through the box back (Figure 9) | No holes in the post for the box |
| Rope ends | No termination | A loop at each end, held in rated screw links at the eye nut and at the throw weight (Figures 17 and 18) | Rated, replaceable connections |
| Canal edge | Ropes on the concrete edge | Two sleeves on the ropes where they cross the edge (Figure 19) | Rope over a sharp edge loses strength |
| Box lid | Could not close over the anchored ropes | A notch in the front rim and four drain holes (Figure 8) | The ladder stays linked to the anchor while stored |
| Footing | No size | 500 mm across and 1,200 mm deep at every site, wet or dry (Figure 4) | Holds the anchor load in wet or dry bank soil, so one size fits every site |

## 3. Making the components

Make and check each component before the assembly step that needs it. Sizes are in millimetres. On the station, "canal side" is the face of the post toward the water and "back" the face away from it. On the ladder, "up" is toward rung 1, the top rung, and "wall side" is the side the stand-off blocks point to. Workshop tolerance is 1 mm unless a step says otherwise; drawings do not carry tolerances before TRL 4.

### 3.1 Post

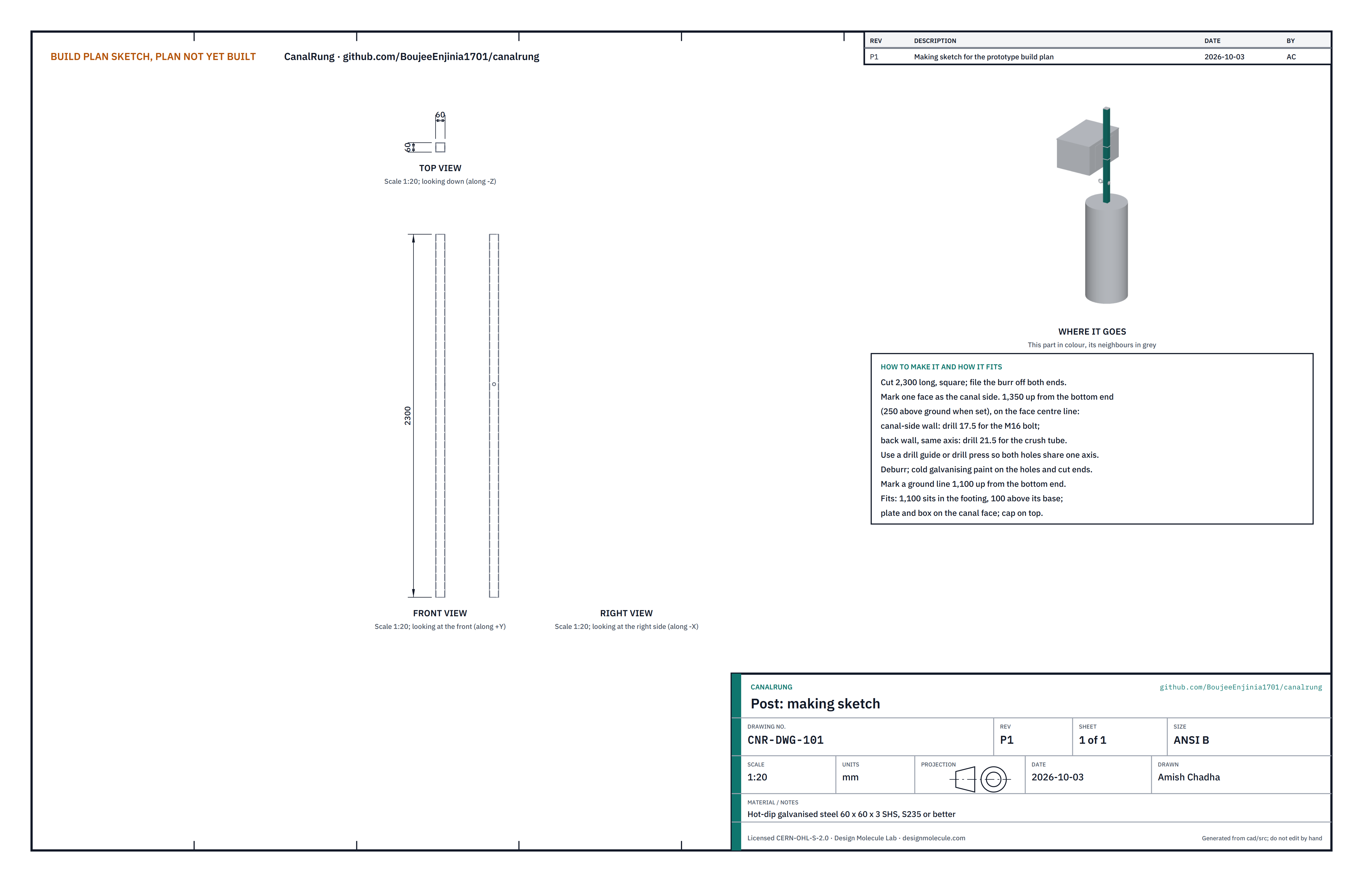
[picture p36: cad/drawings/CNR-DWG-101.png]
Figure 2. Making sketch of the post


*Figure 2. Post making sketch (CNR-DWG-101).*

**What it is and what it is made from.** The upright that holds the box and carries the ladder anchor. Hot-dip galvanised square steel tube 60 x 60 x 3 mm, grade S235 or better, 2,300 long.

**How to make it.**

1. Cut the tube to 2,300, square, and file the burr off both ends.
2. Choose one face as the canal side and mark it along its length.
3. Measure 1,350 up from the bottom end and mark the centre of the canal-side face and of the back face at that height. This puts the anchor 250 above the ground.
4. Clamp the post in a drill press or use a drill guide so both holes share one axis square to the faces. Drill a 6 pilot right through both walls.
5. Open the hole in the canal-side wall to 17.5 (for the bolt) and the hole in the back wall to 21.5 (for the crush tube).
6. Deburr both holes inside and out. Paint the holes and both cut ends with cold galvanising paint.
7. Mark a ground line all round, 1,100 up from the bottom end.

**How it fits the parts next to it.** The bottom 1,100 sits in the concrete footing with 100 of concrete under it (Figure 4). The crush tube goes in through the back hole and the anchor bolt through both (Figure 6). The mounting plate sits flat on the canal-side face with its bottom edge 480 above the ground line, held by two U-bolts round the back of the post (Figure 9). The cap closes the top.

**Check before moving on.** Push a 16 rod through both holes: it must pass straight through without forcing. The 21.3 crush tube must slide into the back hole.

### 3.2 Concrete footing

Figure 3. Making sketch of the footing

*Figure 3. Footing making sketch (CNR-DWG-103).*

**What it is and what it is made from.** The concrete that holds the post in the bank against the pull of a climber. About 0.23 m3 of 25 MPa concrete, about 22 bags of 25 kg premix, in a hole 500 across and 1,200 deep. This one size is used at every site, whether the bank is dry or wet.

**How to make it.**

1. Choose the spot with the canal operator: 1,000 from the canal edge to the post centre, on level bank, clear of the lining's joints, drains and any buried services (have them located first).
2. Dig or auger the hole 500 across and 1,200 deep, with straight sides. Keep the spoil away from the canal edge.
3. Pour 100 of concrete into the bottom and level it.
4. Stand the post on it (assembly step 1), plumb it both ways with a spirit level and brace it.
5. Fill the hole in layers of about 200, rodding each layer to drive out air, up to 10 to 20 above the ground, and slope the top away from the post so water runs off.
6. Keep the concrete damp and leave it 7 days before any load goes on the eye nut.

**How it fits the parts next to it.**

Figure 4. Joint 1: the post in the footing, cut open

*Figure 4. The post stands on 100 of concrete; the concrete wraps its bottom 1,100 and fills its open end.*

**Check before moving on.** The post is plumb within 5 in 1,000 in both directions, the ground line is level with the ground, and the concrete is sound with no voids at the top.

### 3.3 Crush tube

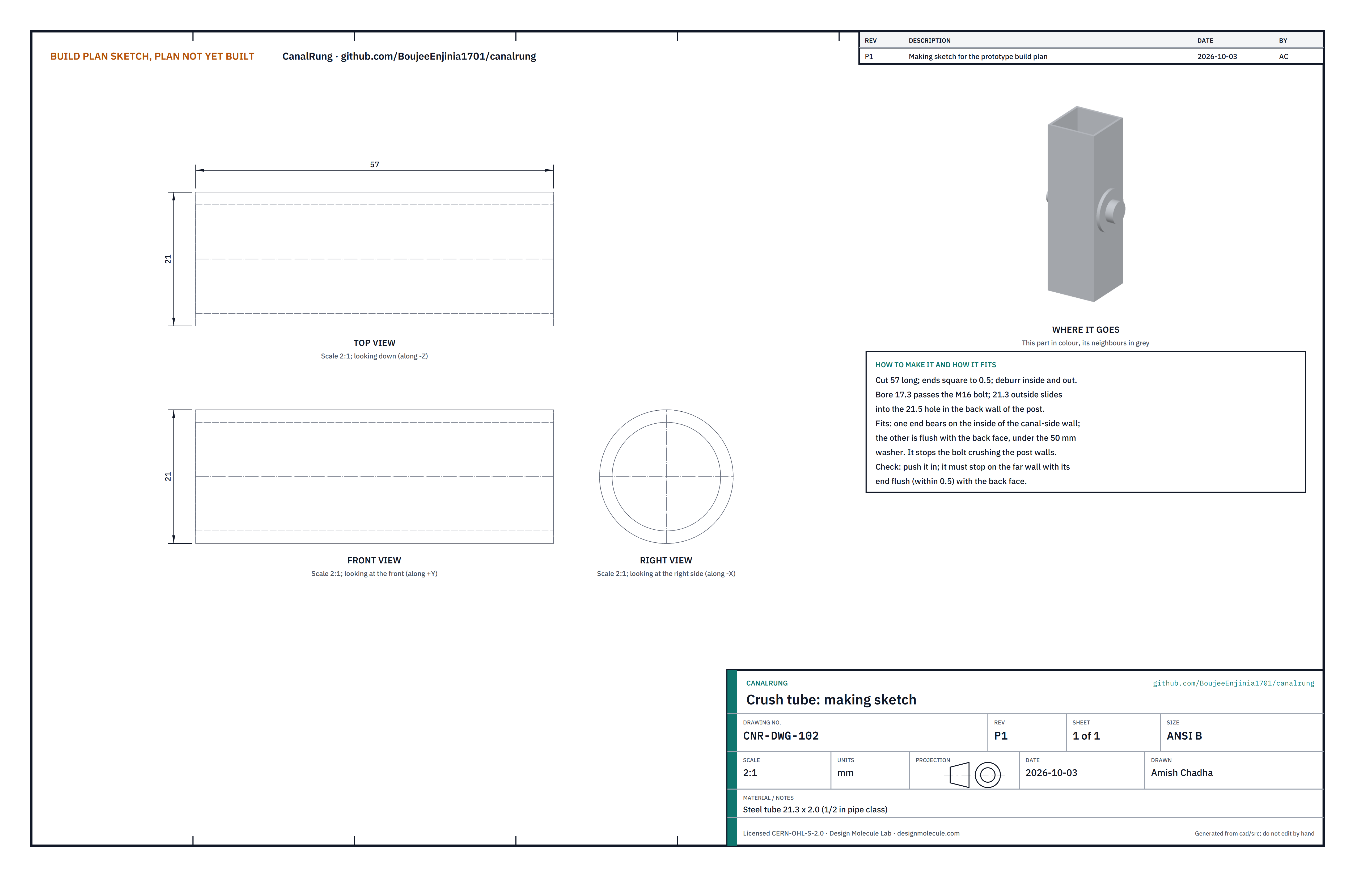
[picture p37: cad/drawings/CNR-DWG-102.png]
Figure 5. Making sketch of the crush tube


*Figure 5. Crush tube making sketch (CNR-DWG-102).*

**What it is and what it is made from.** A short steel tube inside the post that the anchor bolt passes through, so the bolt can be tightened without squashing the post. Steel tube 21.3 outside, 2.0 wall (half-inch pipe class).

**How to make it.**

1. Cut 57 long with the ends square within 0.5.
2. Deburr inside and out so the bolt slides through.

**How it fits the parts next to it.**

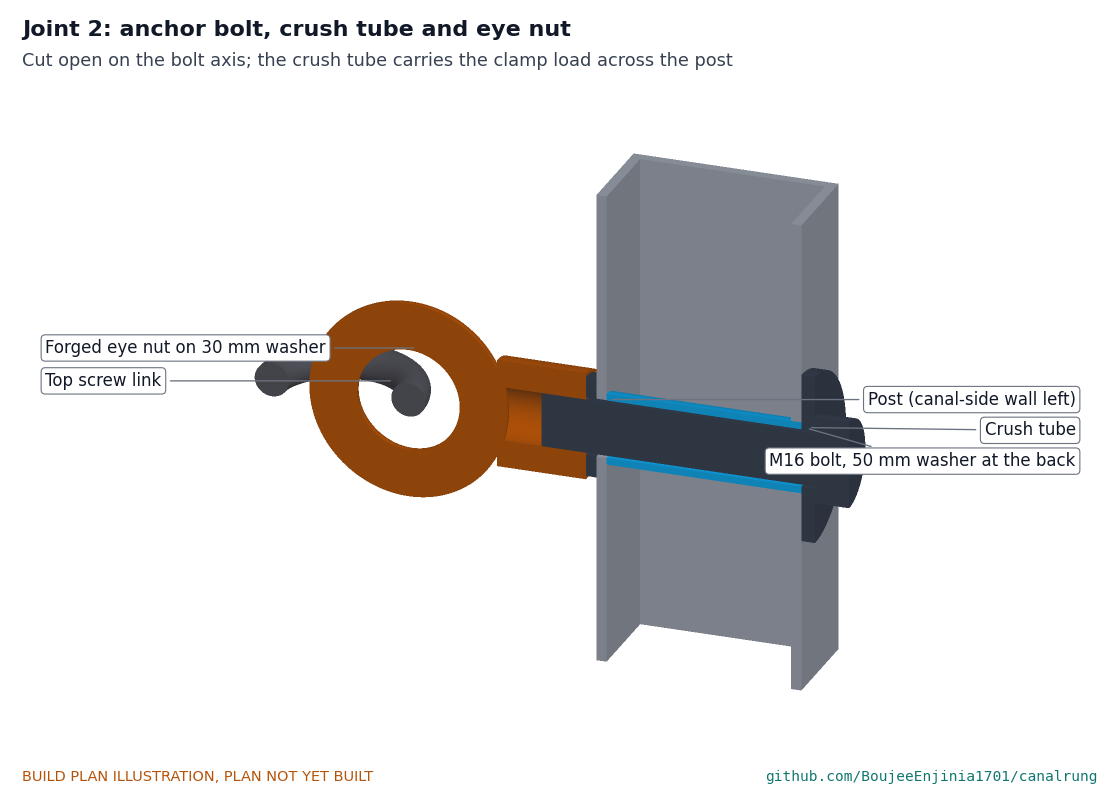
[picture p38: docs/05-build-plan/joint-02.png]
Figure 6. Joint 2: anchor bolt, crush tube and eye nut, cut open on the bolt


*Figure 6. The crush tube goes in through the back wall and stops on the inside of the canal-side wall; the bolt runs through it; the eye nut screws onto the bolt on the canal side; the top screw link passes through the eye.*

One end bears on the inside face of the canal-side wall; the other end is flush with the back face, where the 50 mm washer under the bolt head covers it. Tightening the bolt clamps the canal-side wall between the eye nut's washer and the crush tube, not the two walls together.

**Check before moving on.** Push the tube into the back hole: it must stop on the far wall with its end flush with the back face, within 0.5.

### 3.4 Box mounting plate

Figure 7. Making sketch of the mounting plate

*Figure 7. Mounting plate making sketch (CNR-DWG-104).*

**What it is and what it is made from.** A flat plate between the post and the back of the box that spreads the clamp load over the plastic. Aluminium sheet 4 thick, 5052 or 6061 class, 400 wide and 300 tall.

**How to make it.**

1. Cut the plate to 400 x 300 and round the corners to about 5. File every edge smooth.
2. Mark a centre line down the 300 height.
3. Drill four 9 holes for the U-bolt legs: 34 each side of the centre line, at 80 and 240 up from the bottom edge.
4. Deburr both faces.

**How it fits the parts next to it.** The plate sits flat on the canal-side face of the post, centred on it, with its bottom edge 480 above the ground. The box's back wall sits flat on its other face. The U-bolt legs pass through the plate and then the box (Figure 9).

**Check before moving on.** Hold the plate on the post at the right height: the holes must sit just outside the post's sides, 4 clear of them, where the U-bolt legs will run.

### 3.5 Storage box, drilled

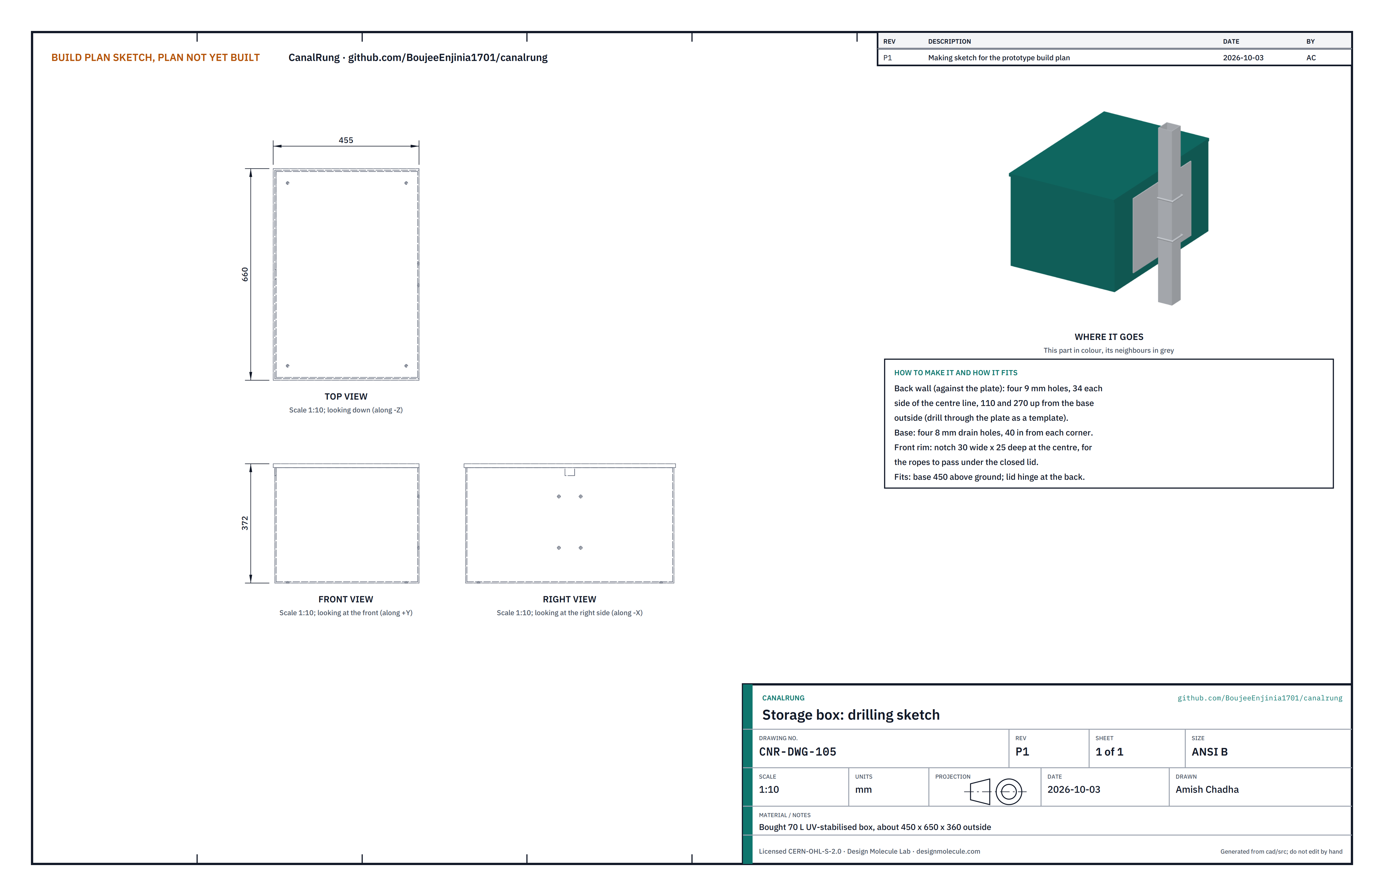
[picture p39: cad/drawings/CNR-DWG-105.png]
Figure 8. Drilling sketch of the storage box


*Figure 8. Storage box drilling sketch (CNR-DWG-105).*

**What it is and what it is made from.** A bought polypropylene or polyethylene storage box of about 70 L, about 450 deep, 650 wide and 360 tall outside, UV-stabilised, bright yellow or orange, with a hinged lid, clip latches and no lock. Check before buying that its inside depth takes a 370 long rung.

**How to make it.**

1. Hold the drilled mounting plate against the outside of the box's back wall, its bottom edge 30 above the box's base, centred. Mark the four holes through the plate. They come out 34 each side of the centre line and 110 and 270 up from the base.
2. Drill the four holes 9, from outside, with a sharp drill and a wood block inside the box behind the wall so the plastic does not split.
3. Drill four 8 drain holes in the base, 40 in from each corner.
4. Cut a notch 30 wide and 25 deep in the centre of the front rim (the side away from the hinge), with a fine saw and a file. Round its corners so the rope slides out easily.
5. Deburr every hole and the notch with a knife.

**How it fits the parts next to it.** The back wall sits flat on the mounting plate, with the lid hinge at the back, against the post. The U-bolt legs come through the four holes into the box, where a fender washer and a nyloc nut on each hold the box, the plate and the post together.

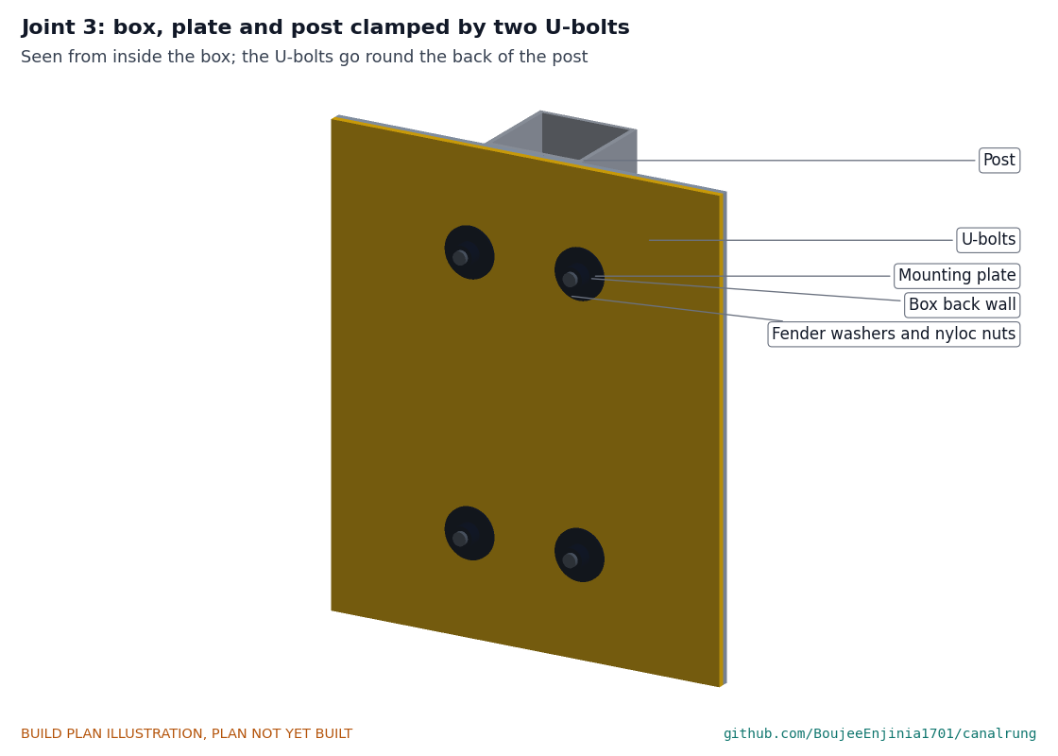
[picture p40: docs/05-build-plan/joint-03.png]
Figure 9. Joint 3: box, plate and post clamped by the U-bolts


*Figure 9. Seen from inside the box: the U-bolts go round the back of the post, through the plate and the box back wall; washers and nyloc nuts inside.*

**Check before moving on.** The lid closes and latches with a 9 rope lying in the notch.

### 3.6 Rungs (make 13)

Figure 10. Making sketch of a rung

*Figure 10. Rung making sketch (CNR-DWG-106), shown as a stand-off rung with both pairs of holes.*

**What it is and what it is made from.** The hand and foot holds. Aluminium 6061-T6 round tube, 28.6 outside and 1.65 wall (1-1/8 in x 0.065 in), 360 long. About 4.7 m of tube for all 13.

**How to make it.**

1. Cut 13 lengths of 360, ends square, with a tube cutter or a fine saw and a square guide. Deburr inside and out.
2. Number the rungs 1 to 13 with a marker; rung 1 is the top rung. Rungs 3, 6, 9 and 12 are the stand-off rungs.
3. Lay each rung in a V-block on a drill press. Drill a 6 pilot right across the tube, 20 in from each end, through both walls on one line, then open the holes to 16. These are the rope holes.
4. Stand-off rungs only: on the same line as the rope holes, drill 5.3 right across the tube 40 in from each end (the block bolt holes).
5. Round the edge of every hole, inside and out, with a deburring tool, so no sharp edge is left for the bush.

**How it fits the parts next to it.**

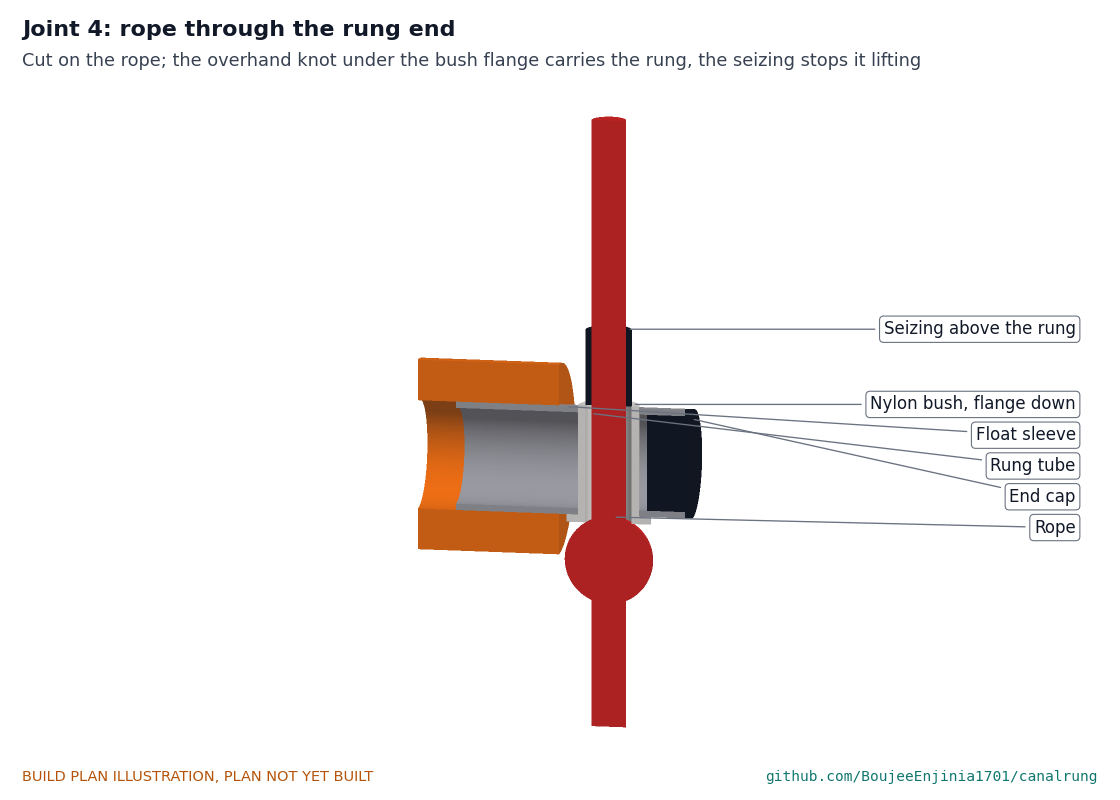
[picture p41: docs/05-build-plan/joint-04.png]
Figure 11. Joint 4: the rope through the rung end, cut open on the rope


*Figure 11. The nylon bush lines the rope hole with its flange under the rung; the overhand knot under the flange carries the rung; the seizing above the bush stops it lifting; the end cap stops 2 short of the hole.*

A flanged nylon bush goes up through each rope hole from below, flange under the rung. The rope runs through the bush. The foam sleeve sits on the middle of the rung, 2 clear of the bushes. An end cap closes each end.

**Check before moving on.** A 16 rod passes straight through each pair of rope holes; all 13 rungs lie flat together with their holes lined up (sight along them).

### 3.7 Float sleeves (make 13)

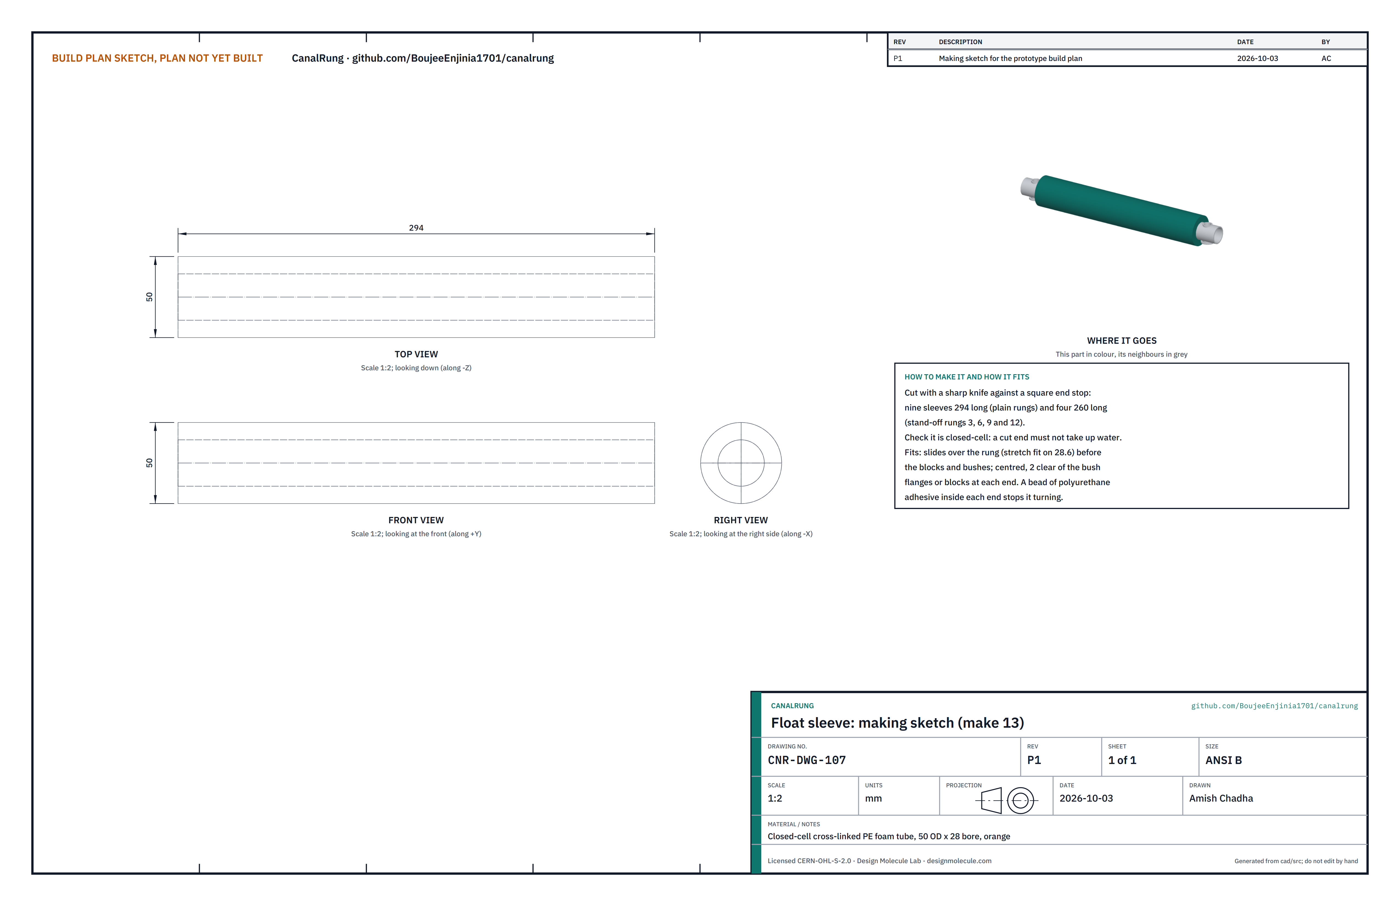
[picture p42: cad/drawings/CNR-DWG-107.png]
Figure 12. Making sketch of a float sleeve


*Figure 12. Float sleeve making sketch (CNR-DWG-107).*

**What it is and what it is made from.** The orange foam sleeve on each rung that makes it float and gives a softer grip. Closed-cell cross-linked polyethylene foam tube, 50 outside, 28 bore, about 33 kg/m3. About 3.7 m of tube in all.

**How to make it.**

1. Cut a short test piece and hold it under water for a minute; a cut end that takes up water means the foam is not closed-cell, so do not use it.
2. With a sharp knife against a square end stop, cut nine sleeves 294 long (for the plain rungs) and four 260 long (for rungs 3, 6, 9 and 12).

**How it fits the parts next to it.**

Figure 13. Joint 5: stand-off block and float sleeve on a stand-off rung

*Figure 13. On a stand-off rung the shorter sleeve sits between the blocks; on a plain rung the longer sleeve sits between the bushes.*

The sleeve slides over the rung before the blocks and bushes go on, and sits in the middle with about 2 clear at each end. A bead of polyurethane adhesive inside each end stops it turning on the rung.

**Check before moving on.** The sleeve grips the rung and does not slide under its own weight.

### 3.8 Wall stand-off blocks (make 8)

Figure 14. Making sketch of a stand-off block

*Figure 14. Stand-off block making sketch (CNR-DWG-108).*

**What it is and what it is made from.** The plastic blocks on rungs 3, 6, 9 and 12 that hold the ladder off the wall so a hand can get behind each rung. HDPE sheet 16 thick, UV-stabilised; one 300 x 150 offcut makes all eight.

**How to make it.**

1. Mark the outline on the sheet eight times: 115 long; 40 tall for the first 55 from the back end; then tapering over the last 60 to a 24 tall nose.
2. Saw just outside the lines and file to them. Round the nose corners to about 4 so the block slides on concrete.
3. Drill a 28.8 hole for the rung, its centre 20 from the back end and on the height centre line (step drill or hole saw, slowly, with the sheet clamped).
4. Drill a 5.3 hole straight down through the middle of the 16 thickness, crossing the rung hole at its centre.
5. Deburr with a knife.

**How it fits the parts next to it.**

Figure 15. Joint 5 again: the block on its rung

*Figure 15. The block on the rung, nose toward the wall, locked by an M5 bolt down through the block and the rung.*

Each block slides onto the rung from its end, after the foam sleeve, and sits just inside the bush with 1 to spare. Its nose points to the wall side. One M5 x 50 bolt goes down through the block and the rung's 5.3 holes, with a washer each side and a nyloc nut underneath. The nose is 95 from the rung's centre, so the foam sleeve stands 70 off the wall.

**Check before moving on.** On a stand-off rung, both blocks point the same way and lie flat on a table together.

### 3.9 Side ropes (make 2)

Figure 16. Making sketch of a side rope

*Figure 16. Side rope making sketch (CNR-DWG-109): the rope finished, laid straight, with its loops and knots.*

**What it is and what it is made from.** The two ropes that carry the rungs and the climber. 9 low-stretch kernmantle rope to EN 1891 type B, with a declared breaking strength of at least 18 kN, polyester if available. 16 m in all. It runs freely through the 12 bore of the bushes, and its stopper knot is still far too big to pull through.

**How to make it.**

1. Cut two lengths of 8.0 m: wrap tape round the rope, cut through the tape with a hot knife, and seal each end.
2. Tie a figure-eight on a bight at one end of each rope, with a loop about 80 long and a tail of at least 60. Dress the knot so its strands lie side by side and pull it tight.
3. Lay both ropes side by side on a clean floor with the loops together. From the loop's knot measure 1,106 along each rope and mark rung 1. Then mark every 335 for rungs 2 to 13: twelve more marks. Use a fine marker or a wrap of tape; the marks must match on both ropes.
4. Leave the rest of each rope free; the stopper knots are tied as the rungs go on (assembly step 11).

**How it fits the parts next to it.** Each rope runs down through the bushes at one end of every rung. An overhand stopper knot sits under each bush flange at its mark and carries the rung (Figure 11); a seizing above the bush stops the rung lifting. The top loops go into one screw link on the eye nut (Figure 17); below rung 13 each rope runs 280 to a second figure-eight loop, and both loops and the weight's webbing loop go into the bottom screw link (Figure 18). Where the ropes cross the canal edge they run in sleeves (Figure 19).

Figure 17. Joint 6: the rope loops on the top screw link

*Figure 17. Both top loops in one screw link; the link through the eye nut's ring; the gate screwed fully shut.*

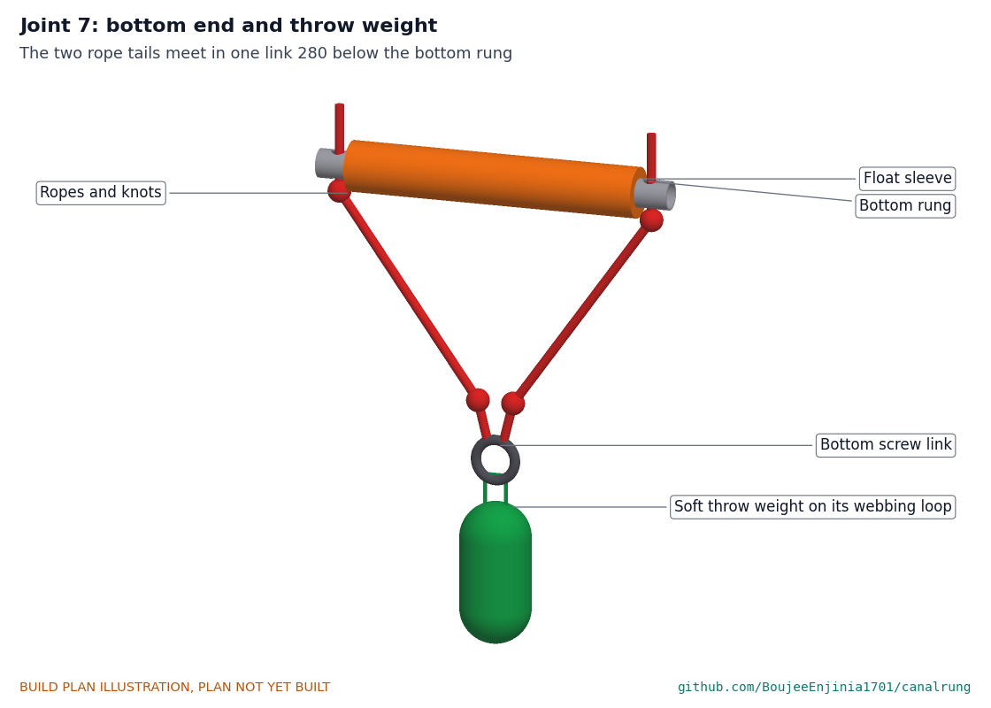
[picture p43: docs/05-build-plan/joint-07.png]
Figure 18. Joint 7: the bottom end and throw weight


*Figure 18. The two rope tails meet in the bottom link 280 below the bottom rung; the soft weight hangs from it on its webbing loop.*

Figure 19. Joint 8: the ropes over the canal edge in their sleeves

*Figure 19. The edge protector sleeves slide on the ropes and sit on the concrete edge when the ladder is thrown.*

**Check before moving on.** Both ropes are the same length to within 20 between the loop knot and the last mark; every mark is 335 from the next within 3.

### 3.10 Bought components

| Component | What to buy | What to do to it |
| --- | --- | --- |
| Anchor bolt set | M16 x 90 hex bolt, grade 8.8, galvanised; one 50 outside x 4 washer and one 30 outside x 3 washer; high-strength threadlocker | Nothing |
| Forged eye nut | M16 forged steel eye nut, DIN 582 class, marked with a working load limit of at least 700 kg | Check the marking; reject any unmarked or cast eye |
| Square U-bolts (2) | M8 square U-bolt for 60 square tube, 80 usable leg, with nuts | Nothing |
| Box fixings (4) | M8 nyloc nut and 30 outside fender washer, stainless | Nothing |
| Post cap | Plastic cap for 60 square tube | Nothing |
| Decals and tamper tag | UV-laminated vinyl: a pictogram how-to for the lid (open, throw upstream, never go in) and a front warning (do not enter the water, call the emergency number, not a seat); a numbered plastic tamper tag | Apply to clean, dry plastic |
| Rescue knife | Blunt-tip rope rescue knife with a sheath | Tether it under the lid with a cable tie through the sheath |
| Rope bushes (26) | Nylon flanged sleeve bush, 12 bore, 16 outside, 22 flange x 2, 30 long | Trim to 29 long with a knife so the top sits just proud of the rung |
| Rung end caps (26) | Plastic insert plug for 28.6 x 1.65 tube | Trim the insert to 10 long if longer, so it stops short of the rope hole |
| Stand-off bolts (8) | M5 x 50 stainless A2-70 bolt, two washers, one nyloc nut | Nothing |
| Seizing twine | Waxed polyester whipping twine, about 1 | Nothing |
| Screw links (2) | 10 steel screw link (maillon), marked with a working load limit of at least 1,000 kg, about 60 inside length | Check the marking and that the gate closes fully |
| Soft throw weight | 0.5 kg fabric pouch of lead-free steel shot with a sewn webbing loop, bright colour | Nothing |
| Edge protector sleeves (2) | PVC-coated polyester rope protector, hook-and-loop, 500 long, for 9 to 13 rope | Nothing |

## 4. Putting it together

The station (steps 1 to 7) and the ladder (steps 8 to 14) can be built at the same time; steps 15 and 16 join them. The ladder pictures show 4 of the 13 rungs. In the step pictures, parts already fitted are grey and the parts being fitted are in colour, with a red arrow showing the way they go in.

### Step 1: stand the post in the hole

Step 1

Pour the 100 of concrete into the base of the hole and level it. Stand the post on it with the canal-side face toward the canal and the ground line level with the ground. Plumb it both ways and brace it with two timber battens and clamps.

### Step 2: pour the footing

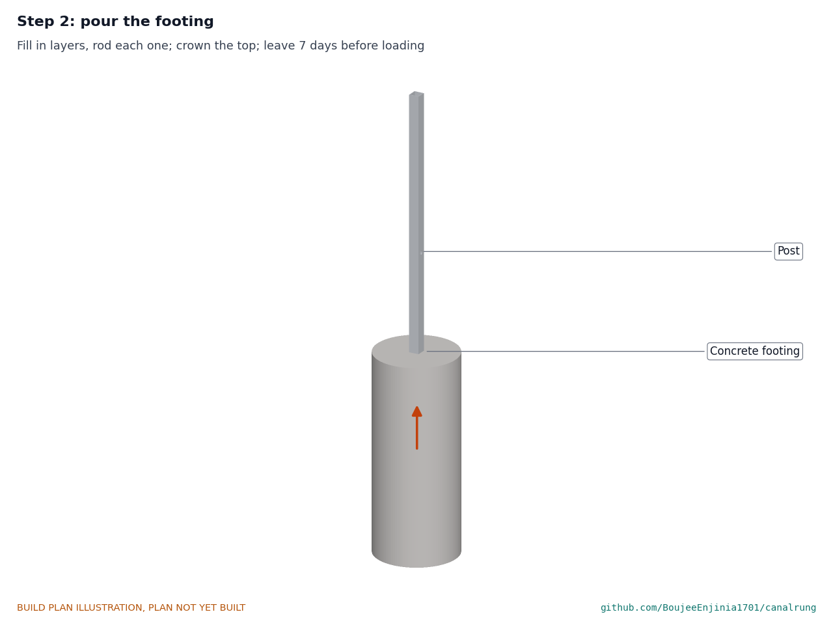
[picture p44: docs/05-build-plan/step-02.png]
Step 2


Fill the hole in layers of about 200, rodding each one, up to just above the ground; slope the top away from the post. Check plumb again after each layer. **Hold point:** leave 7 days, kept damp, before anything is fixed to the eye nut.

### Step 3: crush tube into the post

Step 3

Slide the crush tube into the 21.5 hole in the back wall until it stops on the inside of the canal-side wall. Its end should be flush with the back face.

### Step 4: anchor bolt and eye nut

Step 4

Put the 50 washer on the bolt and push the bolt in from the back, through the crush tube and out of the canal-side hole. Put the 30 washer on the bolt on the canal side. Put two drops of high-strength threadlocker on the thread and screw on the eye nut by hand until it is tight on the washer with its ring upright (in line with the canal-side face, standing vertical). Hold the eye nut and tighten the bolt head with a 24 spanner until firm; the ring must end upright. **Hold point:** leave the threadlocker 24 hours before loading.

### Step 5: mounting plate and U-bolts

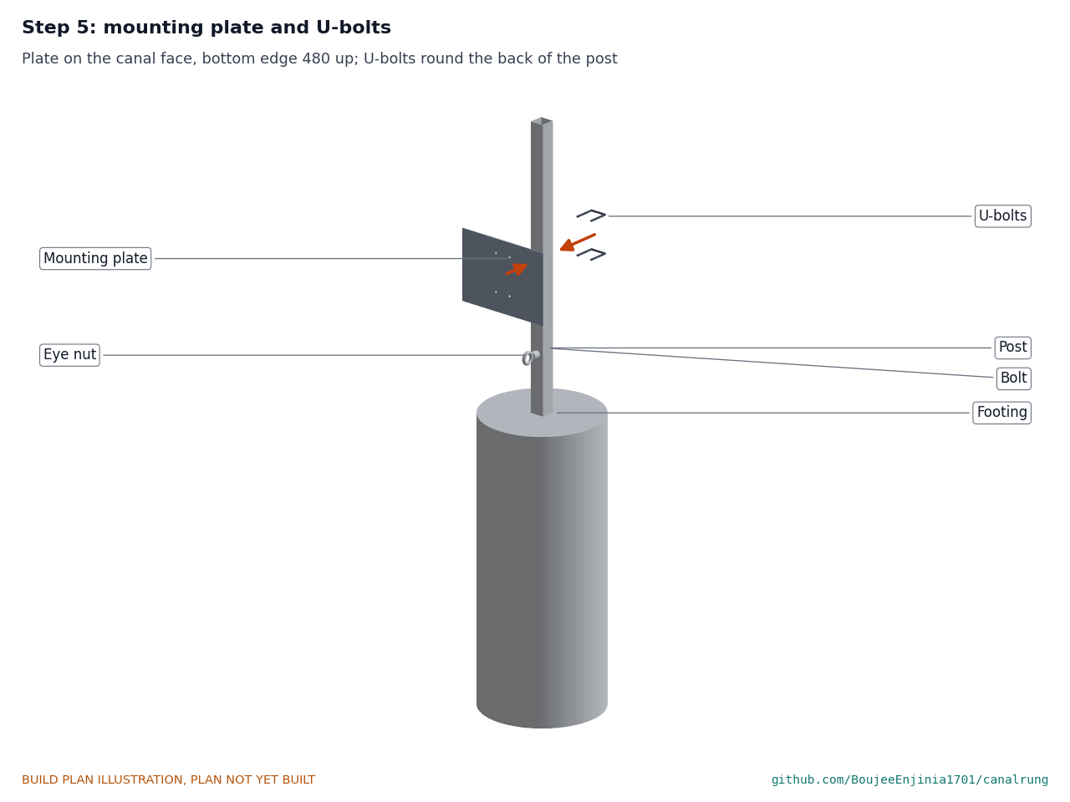
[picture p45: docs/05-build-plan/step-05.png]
Step 5


Hold the plate on the canal-side face, centred, its bottom edge 480 above the ground. Pass the two U-bolts round the back of the post and through the plate's holes, the lower one through the lower pair.

### Step 6: box onto the U-bolt legs

Step 6

Lift the box onto the four U-bolt legs through the holes in its back wall, lid hinge at the back, until the back wall sits flat on the plate.

### Step 7: box fixings, post cap, decals and knife

Step 7

Inside the box, put a fender washer and a nyloc nut on each U-bolt leg and tighten them evenly with a 13 spanner until the box is firm on the plate and the plate on the post; stop before the plastic dishes. Tap the cap onto the post. Apply the decals and fit the tamper tag. Tether the knife under the lid.

### Step 8: float sleeves onto the rungs

Step 8

Slide a 294 sleeve onto each plain rung and a 260 sleeve onto each stand-off rung (3, 6, 9 and 12), with a bead of adhesive inside each end, and centre it.

### Step 9: stand-off blocks on rungs 3, 6, 9 and 12

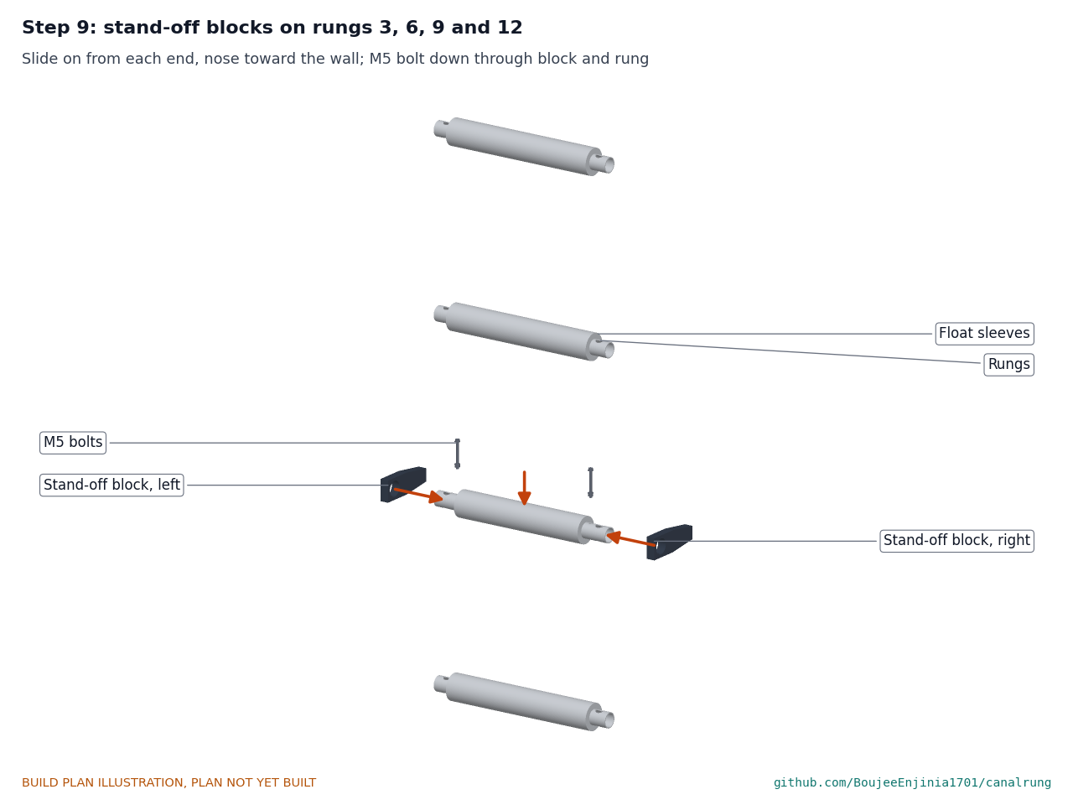
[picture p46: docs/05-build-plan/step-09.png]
Step 9


On each stand-off rung, slide a block onto each end, nose toward the same side, up to the sleeve. Line up the block holes with the rung's 5.3 holes and put an M5 bolt down through each with a washer under the head; washer and nyloc nut underneath; tighten until the block does not turn. All the noses point to the wall side.

### Step 10: rope bushes and end caps

Step 10

Push a bush up into each rope hole from below until its flange sits on the rung; its top should be just proud of the top of the rung. On stand-off rungs, check the "below" side matches the other rungs: with the noses pointing away from you, the flanges are on the underside. Tap an end cap into each end of every rung.

### Step 11: thread the ropes and tie the knots

Step 11

Hang both top loops on the top screw link from a beam or strong hook, or lay the ropes out on a clean floor. Take rung 1. Pass the free end of the left rope up through the bush at the left end of the rung from below, and the right rope through the right end, and slide the rung up to the rung 1 marks. Tie an overhand stopper knot in each rope just under the bush flange so the top of the knot sits on the mark, and pull it tight; the rung must sit level. Repeat for rungs 2 to 13 in order, threading each from the free ends. Keep the stand-off noses all on the same side. Below rung 13, measure 280 and tie a figure-eight on a bight in each rope for the bottom link.

### Step 12: seizings above every rung end

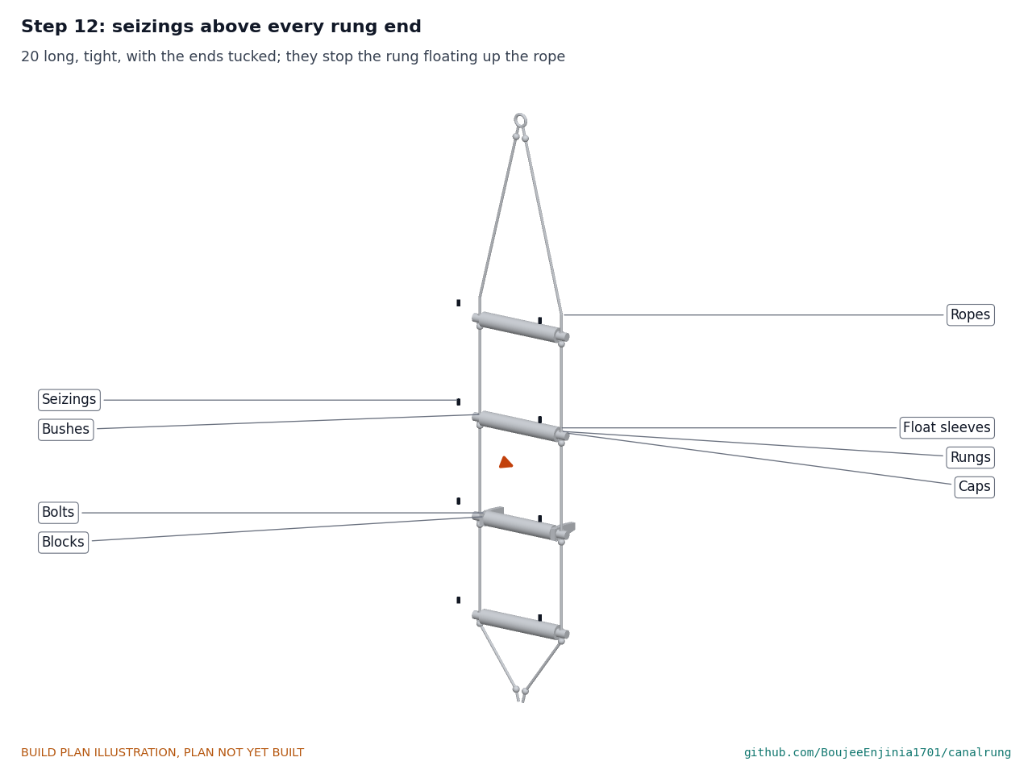
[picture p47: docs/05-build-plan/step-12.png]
Step 12


At each rung end, just above the bush, whip the rope tightly with the twine for 20, then tuck and pull the end under the turns. The seizing must not slide when pushed with a thumb. There are 26 seizings.

### Step 13: bottom link and throw weight

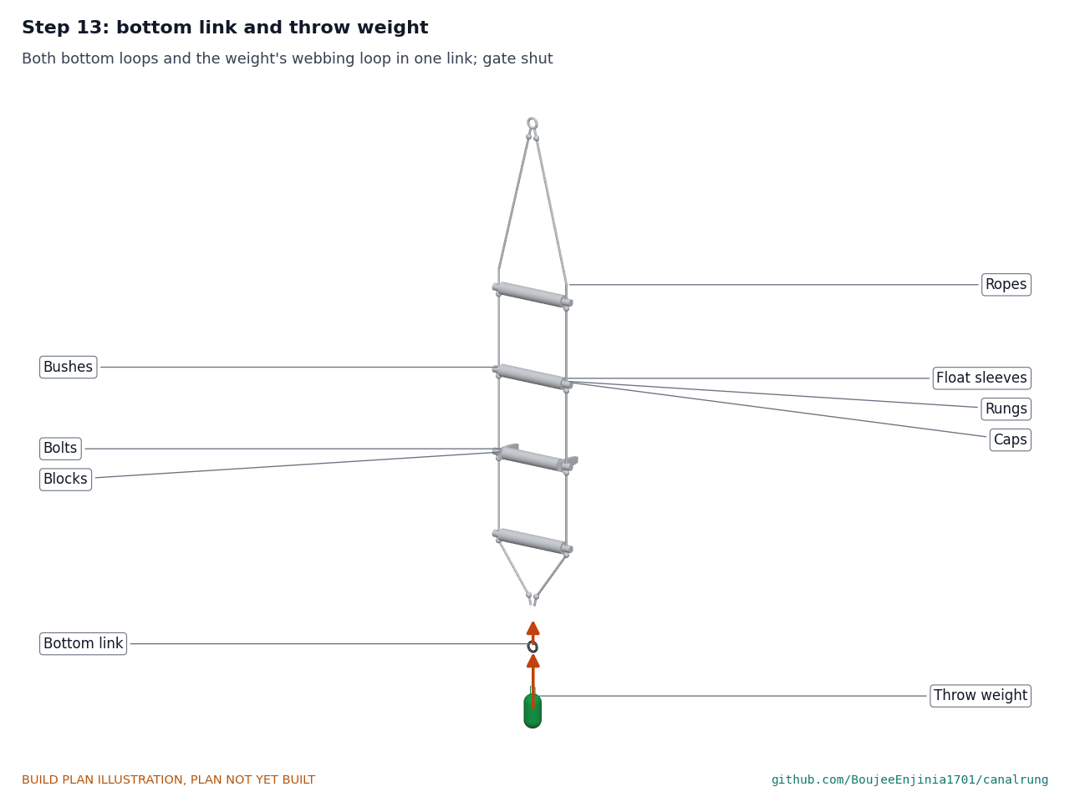
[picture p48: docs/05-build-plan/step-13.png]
Step 13


Open the bottom screw link, put both bottom loops and the throw weight's webbing loop in it, and screw the gate fully shut by hand, then a quarter turn with a spanner.

### Step 14: edge protectors on the top lead

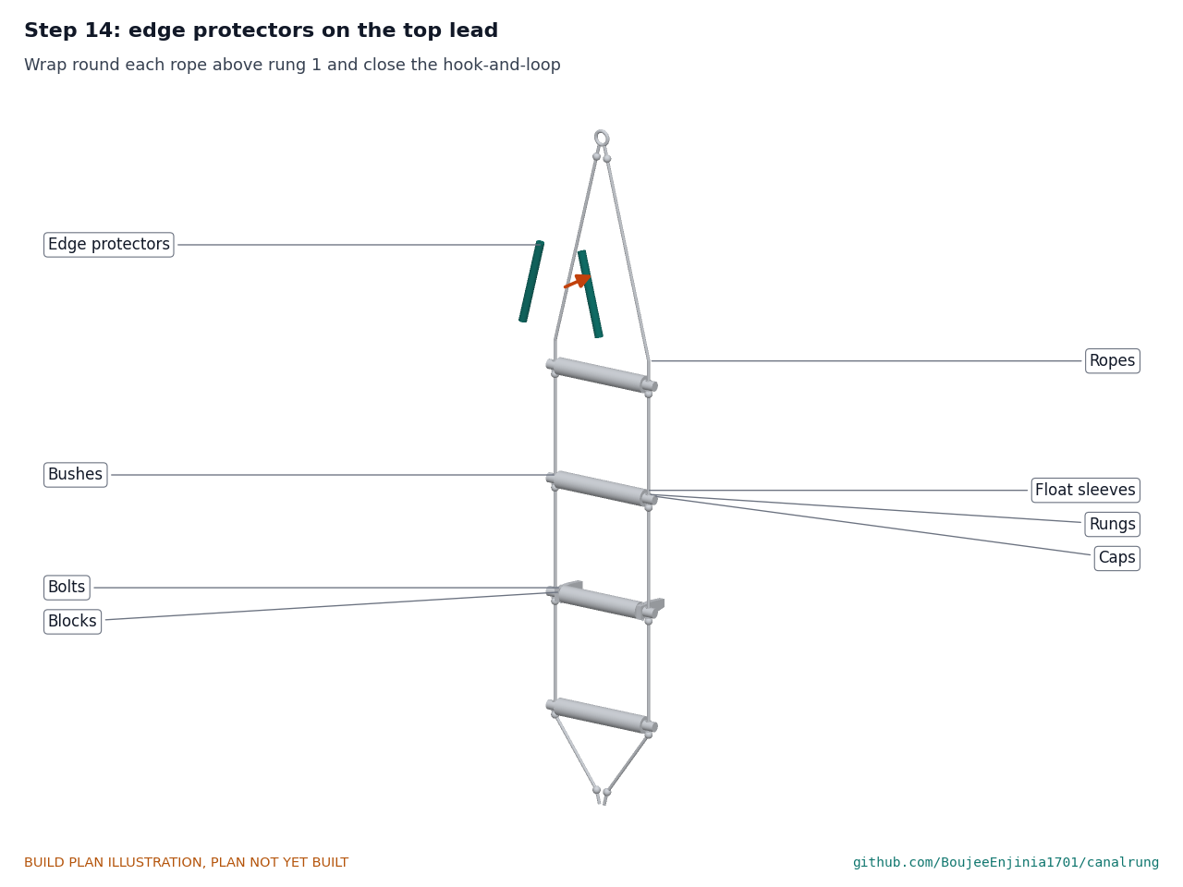
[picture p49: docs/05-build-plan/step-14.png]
Step 14


Wrap one sleeve round each rope between rung 1 and the top link, about 200 above rung 1, and close the hook-and-loop. They slide along the rope to wherever it crosses the edge.

### Step 15: top link onto the eye nut

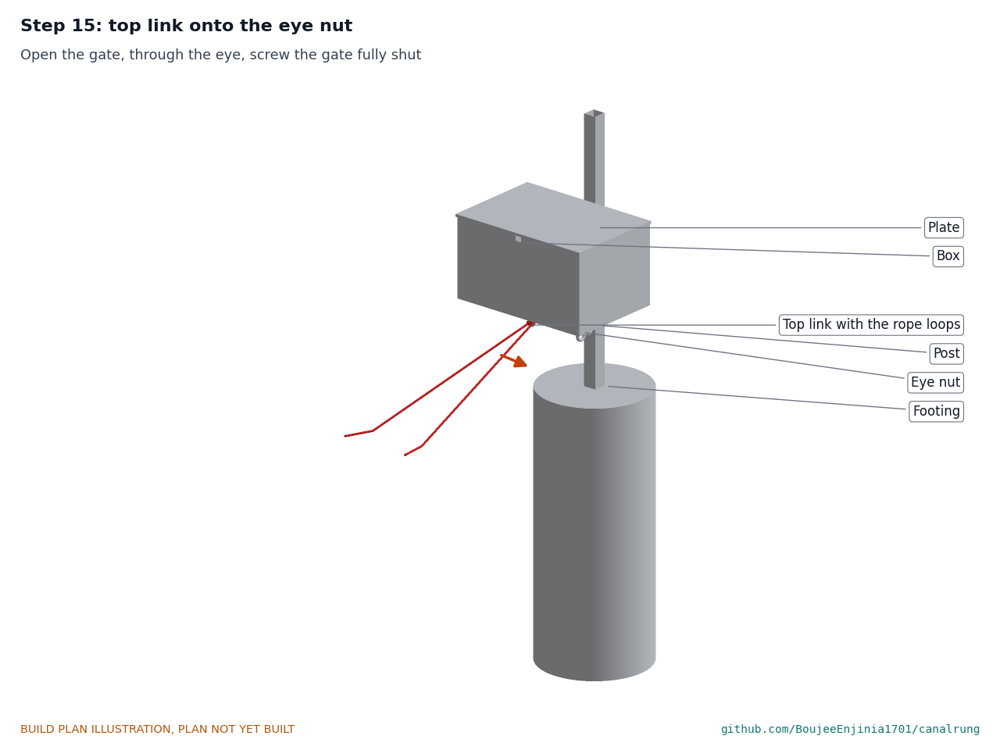
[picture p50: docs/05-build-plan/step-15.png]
Step 15


Take the top screw link with both rope loops in it, open its gate, pass it through the eye nut's ring and screw the gate fully shut, then a quarter turn with a spanner. Lead the ropes from the eye nut under the box, up its front and in through the rim notch.

### Step 16: fold the ladder into the box

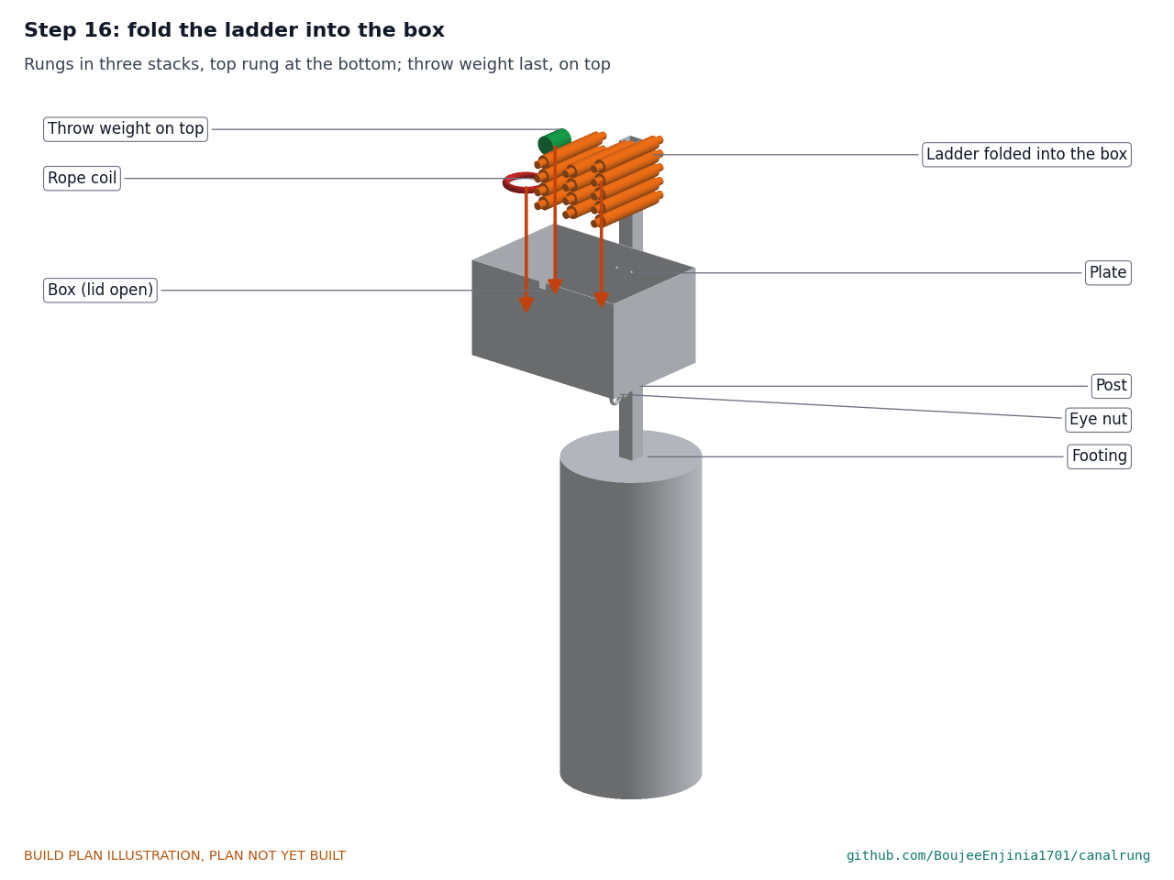
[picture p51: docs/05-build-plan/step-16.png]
Step 16


Open the lid. Fold the ladder into the box rung by rung, starting from the top (rung 1 at the bottom of the box) in three stacks across the box, with the ropes lying between the stacks and no rope crossing over a rung. Coil the tail and put the throw weight on top, where a hand finds it first. Close the lid over the ropes in the notch, latch it and fit the tamper tag.

## 5. First checks

The plan lists them; a TRL 4 test report records them. Each is done only when the safety stops in section 6 allow it.

*Table 2. First checks.*

| Check | Requirement | How | Pass when |
| --- | --- | --- | --- |
| Post plumb and firm | R6 | Spirit level on two faces after 7 days; push hard at the top | Plumb within 5 in 1,000; no movement felt |
| Ladder mass | R2 | Weigh everything that leaves the box on a hanging scale | Recorded; the target is 4.5 kg and the estimate 4.27 kg |
| Knots and rungs level | R4, R5 | Hang the ladder by its top link; sight along the rungs | Every rung level within 10 end to end; pitch 335 within 10 |
| Rung proof load | R4 | Ladder hung from a test frame (CalRig); 1.5 kN at the middle of each rung for 1 min, by weights | No visible bend afterward (under 1 at the middle); no knot slip over 10 |
| Ladder system proof load | R4 | 4.5 kN through the top link to the bottom rung, pulled by a calibrated rig | Holds 3 min; no damage to rope, knots, bushes or links |
| Anchor proof load | R6 | 4.5 kN on the eye nut toward the canal, at ground height, after 7 days' cure, with a calibrated rig | Holds 3 min; top of post moves under 10; no cracks at the footing |
| Floats | R3 | Ladder with its weight laid in a test tank | Every rung floats; the weight hangs below the bottom rungs |
| Throw | R2 | Ten untrained adults throw on dry land to a target 3 m away | 8 of 10 land within 1 m |
| Deploy time | R7 | Untrained volunteers, pictogram only, from closed box to ladder at the bottom of a test wall | Under 30 s |
| Climb | R5 | Adult volunteer in a 1.5 deep test tank with a smooth vertical wall, lifeguards present | Out in under 60 s |
| Box | R8 | Hose the closed box for 5 min; open it | Water drains out; the lid closes over the ropes |

## 6. Safety stops

Work stops at each point below until everything listed is true.

> **Safety:** The ladder carries a person's life. No one climbs it, stands on it or tests it in water until the stops below are cleared, and it is never placed at a real canal at TRL 4 without the canal operator's written permission.

1. **Before digging:** buried services located and marked; the hole at least 1,000 from the canal edge; a second person present and a life jacket worn by anyone within 2 m of the edge.
2. **Before loading the eye nut:** the concrete has cured 7 days; the eye nut is forged and marked with its rating; the threadlocker has cured 24 hours; the screw link gate is shut.
3. **Before any proof load:** the rig is calibrated, everyone is out of the line of the rope and behind the post, and the load is raised slowly and held, never dropped.
4. **Before anyone climbs, even on dry land:** the rung, system and anchor proof loads have passed; every knot, seizing, bush and link has been inspected; the climb is no more than 1 m off the ground with a mat below.
5. **Before any water test:** test tank only, never a canal; lifeguards in attendance; still water; volunteers briefed, in life jackets, and free to stop; the knife at hand.
6. **After any load test or use:** inspect the whole ladder before it goes back in the box, and retire any rope that was loaded over an edge without its sleeve.

## 7. Tools, skills and workspace

- **Tools:** tape measure, square, fine marker; hacksaw with a fine blade or tube cutter; files and a deburring tool; drill press with a V-block (or a drill guide), drills 5.3, 6, 9, 16, 17.5 and 21.5, an 8 drill for the box, and a 28.8 step drill or hole saw for the blocks; spanners or sockets 8, 13 and 24; sharp knife and hot knife for rope; spirit level; post-hole auger or spade; bucket, mixing tub and rod for concrete; hanging scale.
- **Skills:** basic metal and plastic work; mixing and placing concrete; rope work: figure-eight on a bight, overhand stopper knot and a tight seizing, all dressed and set. Anyone new to rope work should practise the knots on spare rope first and have them checked.
- **Workspace:** a bench with a drill press; a clean floor 9 m long or a strong beam about 2.5 m up to hang the ladder while threading it; for the station, the agreed site on the canal bank with a second person.

## 8. Where the numbers come from

- Model: `cad/src/model.py` (dimensions, constructability checks, STEP and STL in `cad/step/` and `cad/stl/`).
- Pictures: `cad/src/build_plan_media.py` (this plan's figures and the making sketches).
- Drawings: `cad/drawings/CNR-DWG-001` (general arrangement) and `CNR-DWG-101` to `CNR-DWG-109` (making sketches).
- Calculations: `docs/04-calcs/01-sizing.md` and `docs/04-calcs/sizing.py` (CNR-CAL-001).
- Bill of materials: `bom/bom.csv`.
- Decisions: `docs/decisions/0002-design-for-construction.md` (CNR-DDR-002) and `docs/06-design-decisions.md` (CNR-DEC-001).

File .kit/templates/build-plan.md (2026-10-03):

---
doc_id: PRJ-BLD-001
title: Project prototype build plan
project: Project name
doc_type: Build plan
version: "0.1"
status: Draft
date: YYYY-MM-DD
author: Amish Chadha
license: CERN-OHL-S-2.0
revisions:
  - version: "0.1"
    date: YYYY-MM-DD
    author: Amish Chadha
    change: First build plan; design made constructable
---

# Project prototype build plan

**Plan, not yet built.** How to build the first proof-of-concept prototype, component by component. Building and testing to it is TRL 4 work. Decisions still to be made are kept in the design decisions register (`docs/06-design-decisions.md`), not here.

## 1. What you are building

Every component, pulled apart and numbered in build order

One short paragraph: what the prototype is, how many components, which are made and which are bought, and the main ways they are made.

## 2. What changed to make it buildable

| Component | The concept had | The buildable design has | Why |
| --- | --- | --- | --- |

## 3. Making the components

### 3.1 Component name

Making sketch

**What it is and what it is made from.**

**How to make it.**

1. Mark out ...
2. Cut ...

**How it fits the parts next to it.**

Close-up of the joint

**Check before moving on.**

## 4. Putting it together

### Step 1: ...

Step 1

## 5. First checks

| Check | Requirement | How | Pass when |
| --- | --- | --- | --- |

## 6. Safety stops

## 7. Tools, skills and workspace

## 8. Where the numbers come from

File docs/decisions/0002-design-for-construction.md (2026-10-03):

---
doc_id: CNR-DDR-002
title: CanalRung design for construction
project: CanalRung
doc_type: Design decision record
version: "0.1"
status: Draft
date: '2026-10-03'
author: Amish Chadha
license: CERN-OHL-S-2.0
revisions:
- version: "0.1"
  date: '2026-10-03'
  author: Amish Chadha
  change: "Changes that make the concept physically buildable, with the reason for each; decided under Amish's 2026-10-03 pre-approval"
---

# 0002: Design for construction

- **Date:** 2026-10-03
- **Status:** accepted. Decided by Amish under his pre-approval of 2026-10-03: "I pre-approve the batch runs along with any recommendations you come up with. I also accept any cost overruns or variations from the assumed scope cost."

## Context

STANDARDS section 18 asks for a design in which every part can be made by its stated process and fits and fastens to the parts next to it (Amish, 2026-09-30: "fix the design assumptions to match and be physically feasible"). The concept of CNR-PRC-001 v0.2 and CNR-DDR-001 said what CanalRung does: rungs fixed at even spacing between two ropes, spacers on some rungs, a weighted bottom end, a bank anchor and a storage post and box. It did not say how a rung is held on a rope, how a spacer or the box is fixed, what the anchor is screwed into, or how the ropes reach the anchor. Working through each part with the model found the problems below. `cad/src/model.py` now runs 245 constructability checks (`python cad/src/model.py --check`): parts that must touch do touch and parts that must not touch are apart by at least the stated clearance. All pass.

The changes keep what the ladder does: the same reach, rung count and pitch, floating rungs, stand-offs, weighted end, fixed anchor and box. Nothing here changes the pitch or the safety case; P5, P8 and P11 make the safety case stronger.

## Decision

*Table 1. Changes made to the model, the BOM and the calculations.*

| # | Problem in the concept | Change made | Why this way |
| --- | --- | --- | --- |
| P1 | Rungs "fixed at even spacing" with no joint between rung and rope | Each rope runs through a 16 mm hole across each rung end, lined by a flanged nylon bush (12 mm bore, flange on the underside). An overhand stopper knot under the flange carries the rung; a 20 mm twine seizing above the bush stops it floating up the rope. In the model the knot bears on the rim of the bush bore | The classic rope ladder joint: no special tools, inspectable by eye, and the load path is rung, flange, knot, rope. The bush keeps the rope off the aluminium hole edges |
| P2 | Wall spacers on "some rungs" with no fixing; a loose spacer could slide along the rung or turn round it | HDPE blocks 16 mm thick, 115 mm long, slid on the rung just inside each bush on rungs 3, 6, 9 and 12, nose 95 mm from the rung axis, each locked by one M5 x 50 bolt down through block and rung (5.3 mm holes in the rung, 40 mm from the ends) | The bolt stops sliding and turning; wall friction puts 610 N across a bolt good for about 6 kN (CNR-CAL-001, D4) |
| P3 | "Buoyant rungs" with no stated float | A closed-cell foam sleeve, 50 mm outside, on every rung: 294 mm long on plain rungs and 260 mm on stand-off rungs, so it sits 2 mm clear of the bushes or blocks; a bead of adhesive inside each end | Sleeve lengths set by the parts beside it; the foam slides on before the blocks and bushes, which fixes the build order |
| P4 | Open tube ends | Plastic end caps with a 10 mm insert, which stops 2 mm short of the rope hole | Closes the ends without blocking the rope (R10) |
| P5 | Anchor "stake, post loop or cross bar"; the M16 eye bolt would crush the 3 mm post walls when tightened | Forged M16 eye nut on an M16 x 90 grade 8.8 bolt through the post 250 mm above ground; a 57 mm crush tube slides in through a 21.5 mm hole in the back wall and bears on the inside of the canal-side wall (17.5 mm hole); a 50 mm washer covers the crush tube end | The crush tube takes the clamp load so the walls stay round; the eye nut is loaded in line with its thread, its strongest direction |
| P6 | Storage box on the post with no fixing; drilling the post for box bolts would need more crush tubes | A 4 mm aluminium plate on the canal face of the post and two square M8 U-bolts round the back of the post; the U-bolt legs pass through the plate and the box back wall, with fender washers and nyloc nuts inside the box | No holes in the post for the box; the plate spreads the clamp load over the plastic wall |
| P7 | Ropes to the anchor and to the throw weight with no termination | A figure-eight loop at each rope end; the two top loops in one 10 mm screw link through the eye nut's ring; the two bottom loops and the weight's webbing loop in a second link 280 mm below the bottom rung. The first model link was too small to pass round the eye's ring and clashed with it; the link is now modelled with a 20 mm radius (about 60 mm inside) and is 6 mm clear | Rated, replaceable connectors; a link that fits round the ring with both loops in |
| P8 | Ropes dragged over the concrete coping edge | Two hook-and-loop edge protector sleeves, 500 mm long, on the top lead | Rope over a 10 mm edge can lose half its strength (CNR-CAL-001, E2) |
| P9 | The box lid could not close over ropes that must stay linked to the eye nut below the box | A 30 x 25 mm notch in the centre of the front rim; the ropes run from the eye nut under the box and up into it through the notch, and lift out when the lid is open; four 8 mm drain holes in the base | The ladder stays linked to the anchor while stored, and rain drains out |
| P10 | No footing size | 400 mm x 1,000 mm concrete footing, post 900 mm deep on 100 mm of concrete; 1,000 mm from the coping to the post centre | Holds 4.5 kN with a factor of 1.92 in drained soil (CNR-CAL-001, G4) |
| P11 | The standard footing is not enough in a saturated bank (factor 0.85) | On wet or soft banks: 500 mm x 1,200 mm footing and a 2,300 mm post | Conservative; a site pull test could relax it (CNR-CAL-001, G5) |
| P12 | Rope length not known | Each side rope cut to 8.0 m: top lead to the eye nut about 1.1 m, rung section with 13 knots about 5.4 m, tail 0.3 m, two loops about 1.2 m | From the model geometry (CNR-CAL-001, B1) |

*Table 2. Knock-on changes.*

| Item | Change | Reason |
| --- | --- | --- |
| Mass | Ladder as thrown 4.48 kg (bushes, caps, blocks, bolts, links and protectors added) | R2 not met by 0.48 kg; reported in CNR-CAL-001 and the register |
| Cost | Lines for the crush tube, U-bolts, plate, fixings, bushes, end caps, stand-off bolts, seizing twine, screw links, edge protectors, decals and knife; the BOM renumbered in build order. Value-engineering target: USD 500. Estimated cost of the constructable design: USD 543.60 (USD 43.60 over the target) | Parts added for construction |
| Drawings | CNR-DWG-001 Rev P2; making sketches CNR-DWG-101 to 109 | Follows the model |
| Documents | CNR-PRC-001 v0.3, CNR-REQ-001 v0.3, CNR-CAL-001 v0.2 | Follows the model; no requirement changed status because of these changes |

## Consequences

- `design_state: constructable` in `project.yaml`. The build plan CNR-BLD-001 shows every component and step in pictures generated from the model (`cad/src/build_plan_media.py`).
- The facts that only real parts can settle (the box's inside depth, the link's inside length, the eye nut and rope markings, the foam and bushes, the site soil) are listed under "To confirm when parts are bought" in CNR-DEC-001.

> **Safety:** P5, P7, P8 and P11 are on the load path a person's life depends on. They follow the conservative option; none removes the need to proof-load the rope, knots, rungs, links and anchor before anyone climbs the ladder (CNR-BLD-001, section 6).

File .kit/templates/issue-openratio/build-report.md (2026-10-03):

---
name: Build report
about: Tell us what happened when you built, printed or tested part of this design
title: "Build report: "
labels: build-report
---

This is a research and educational prototype, not a medical device. It is a TRL 3 concept and is not released for fabrication. If you build any part of it, you do so at your own risk. Reports help everyone.

**What you built** (part, sub-assembly or test)

**Materials, tools and settings**

**What worked**

**What did not work, with photos or measurements if you have them**

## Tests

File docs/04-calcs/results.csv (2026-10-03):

tag | text
A1 | Rung section, rung 1 to rung 13: 4,020 mm at 335 mm pitch; 13 rungs
A2 | Design slope 1.5:1 (H:V) is 33.7 deg; rung 1 lies 150 mm down the wall from the coping
A3 | 1.5:1 slope, water 2,000 mm below the coping: bottom rung 2,313 mm below the coping (313 mm below the water line); 2 rungs at or below the water line, rung 11 59 mm above it
A4 | Deepest water on a 1.5:1 slope with two rungs still at or below the water line: 2,127 mm below the coping
A5 | Vertical wall, water 3,000 mm below the coping: bottom rung 1,170 mm below the water line; 4 rungs at or below it; deepest water with two rungs at or below it: 3,835 mm
A6 | Clear width between rope bushes 298 mm; rung pitch 335 mm; hand clearance behind the float sleeve at a stand-off rung 70 mm
B1 | Side rope cut length 7.95 m each (15.89 m in all) at 55 g/m
B2 | rungs 1.715 kg
B2 | foam 0.161 kg
B2 | bushes 0.091 kg
B2 | caps 0.104 kg
B2 | blocks 0.420 kg
B2 | sobolts 0.080 kg
B2 | ropes 0.874 kg
B2 | seizings 0.020 kg
B2 | links 0.120 kg
B2 | weight 0.530 kg
B2 | protectors 0.160 kg
B3 | Ladder as thrown (everything that leaves the box): 4.27 kg against the 4.5 kg target of R2 (-0.23 kg; +0.27 kg against the earlier 4.0 kg)
B4 | Saving with 25.4 x 1.65 mm rungs instead: 0.20 kg (rejected: see D2)
C1 | Net buoyancy per rung with its share of rope: plain rung 0.277 kg, stand-off rung 0.221 kg (target at least 0.15 kg)
C2 | Throw weight in water 0.442 kg; bottom three rungs lift 0.775 kg, factor 1.75 (target at least 1.5)
C3 | Whole ladder in water: 2.93 kg of spare lift; it floats with the weight hanging below
D1 | Rung tube 28.6 x 1.65 mm 6061-T6: section modulus 890 mm3; 1.5 kN at mid-span over 320 mm gives 120 N m and 135 MPa, 0.56 of the 240 MPa minimum yield (target at most 0.67)
D2 | Lighter 25.4 x 1.65 mm tube: 175 MPa, 0.73 of yield (over the 0.67 limit, so not used)
D3 | Each rung end puts 750 N through the bush flange onto the knot; nylon flange bearing about 17 MPa on a 2 mm contact band (nylon yields at about 50 MPa)
D4 | Stand-off block on a 1.5:1 slope: wall force 612 N per block (whole climber on one rung), friction torque 17.4 N m, 610 N across the M5 bolt (two shear planes, capacity about 6 kN each)
E1 | One 9 mm side rope with a stopper knot, wet: 18 x 0.6 x 0.85 = 9.18 kN; both ropes 18.4 kN; factor 4.08 on the 4.5 kN target (R4 asks for at least 4; Amish's floor for the smaller rope is 3)
E2 | Over an unprotected 10 mm coping edge as well: 9.2 kN for both ropes; the edge protectors keep the rope off the edge
E3 | Screw links: working load limit 1,000 kg = 9.8 kN, 2.18 times the 4.5 kN target
F1 | Design climber 100 kg with a 1.5 dynamic factor: 1.47 kN
F2 | On the 1.5:1 slope the ropes carry the part along the wall, 0.82 kN (friction on the wall ignored); on a vertical wall the whole 1.47 kN
F3 | Person holding a rung in a 2.0 m/s current: drag 700 N on the person and 106 N on three rungs (Cd x A 0.35 m2, rung Cd 1.2)
F4 | Upper bound on the anchor (climbing a vertical wall and the full current drag together): 2.32 kN, 1.94 times inside the 4.5 kN target
G1 | Eye nut M16 working load limit 700 kg in line = 6.87 kN, 1.53 times the target
G2 | M16 grade 8.8 bolt: proof load 94 kN; post wall under the 50 mm washer, punching capacity 66 kN
G3 | Post 60 x 60 x 3: section modulus 12,380 mm3; 4.5 kN at 250 mm gives 1125 N m and 91 MPa, 0.39 of yield
G4 | Standard footing at every site, 500 dia x 1,200 deep, short rigid pile (Broms), drained medium dense granular soil (unit weight 18 kN/m3, 30 deg): ultimate 16.1 kN, factor 3.58 on the target (target at least 1.5)
G5 | Same footing in saturated soil (submerged unit weight 8 kN/m3): 7.2 kN, factor 1.59 (target at least 1.5); the earlier 400 dia x 1,000 deep footing gave only 3.8 kN, factor 0.85
G6 | Concrete in the standard footing 0.232 m3, about 22 bags of 25 kg
H1 | Deploy time estimate: lift the lid 2 s; take the throw weight and the top of the folded ladder 4 s; throw upstream of the person 4 s; let the ladder pay out down the wall 5 s; total 15 s (target under 30 s; to be timed)
H2 | UV: ropes, rungs and foam live in an opaque UV-stabilised box and see daylight only when used or inspected
H3 | Nothing hard is thrown: the throw weight is a soft shot pouch; rung ends are capped and holes bushed; a blunt-tip knife is kept in the lid
I1 | Value-engineering target: USD 500. Estimated cost of the constructable design: USD 605.20 (USD 105.20 over the target)
I2 | Station (post, footing, anchor, box, decals, knife, consumables) USD 358.80; ladder USD 246.40

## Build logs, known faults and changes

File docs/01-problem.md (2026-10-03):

---
doc_id: CNR-PRB-001
title: CanalRung problem statement
project: CanalRung
doc_type: Problem statement
version: "0.2"
status: Draft
date: '2026-10-03'
author: Amish Chadha
license: CERN-OHL-S-2.0
revisions:
- version: "0.1"
  date: '2026-09-30'
  author: Amish Chadha
  change: Initial scaffold
- version: "0.2"
  date: '2026-10-03'
  author: Amish Chadha
  change: "TRL 2 and 3: design envelope stated; open questions answered under Amish's 2026-10-03 pre-approval (CNR-DDR-001); first co-design candidate named; safety section added"
---

# CanalRung problem statement

A person in a lined canal often cannot climb out, and the bystander on the bank has nothing to give them except their own body.

## The problem

Canals are built to move water, not to let people out. The Kittitas Reclamation District notes steep, sometimes vertical banks of smooth concrete and water that is deceptively fast ([KRD](https://www.kittitasreclamationdistrict.org/safety)). The Water Safety Council of Fresno County lists steep slopes and slippery walls, swift currents and turbulence, and cold water of about 13 °C (55 °F) that stiffens muscles ([Water Safety Council of Fresno County](https://www.watersafe.org/canals)). Would-be rescuers who go in after someone can drown too ([Washington L&I FACE, 2002](https://stacks.cdc.gov/view/cdc/228712/cdc_228712_DS1.pdf)).

Fixed aids exist but are spaced out. The Bureau of Reclamation installed escape ladders on concrete-lined canals at 750 ft (229 m) intervals, with cables and droplines upstream of hazardous structures ([USBR REC-ERC-71-36](https://www.usbr.gov/tsc/techreferences/hydraulics_lab/pubs/REC/REC-ERC-71-36.pdf)), and districts fit escape cleats and ropes at siphons ([KRD](https://www.kittitasreclamationdistrict.org/safety)). A person swept by the current may never reach one. Throw bags cost about $24 USD ([Airhead](https://www.airhead.com/products/rescue-throw-bag)) but need a strong pull from the bank. Portable rescue ladders such as Shore Safety's type-approved aluminium ladder hang from a quay edge ([Shore Safety](https://shoresafety.se/en/products/components/rescue-ladder-type-approved/)) and boat swim ladders like Rapid Rung mount on a hull ([Rapid Rung](https://www.rapidrung.com/)). None is a low-cost ladder that a bystander throws down a canal wall to wherever the person is.

## Users and context

| User | Need | Context |
| --- | --- | --- |
| Bystander on the bank | Something they can throw and anchor quickly without going into the water | A child, farm worker or passer-by has just fallen in |
| Person in the water | Something to grab and a way to climb a steep, slick wall | Cold, fast water with lined sides |
| Irrigation district and farm managers | A cheap, durable station they can place at many points along a canal | Pump houses, crossings, orchards and paths |
| Village committees and schools | A kit they can build, place and teach children to use | Canal-side villages in South Asia and elsewhere |

## Operating environment

- Lined canals with side slopes from about 1.5:1 (horizontal to vertical) to vertical and heights to about 3 m (10 ft) from bank to water (estimate). The first version covers water up to 2.0 m below the coping on a 1.5:1 slope and up to 3.0 m on a vertical wall (CNR-REQ-001, design envelope).
- Flow of up to about 2 m/s (6.5 ft/s) at the surface (estimate, to be checked with a district).
- Water from about 5 to 30 °C (41 to 86 °F); algae, silt and debris on the walls.
- Stored outdoors in a post box or on a hook for years; sun, dust and rain.

## Constraints

- Value-engineering target of USD 500 in parts, including a bank-side storage post (a hypothetical control target, not a spending limit).
- Throwable by one adult from the bank; total mass at or below 4 kg (target).
- Built from rope, plastic or aluminium rungs and hand tools; hardware under CERN-OHL-S-2.0.
- No elastic self-stowing mechanism (see design-arounds).
- Published as an open engineering reference, not as certified rescue or life-saving equipment.

## Out of scope

- Fixed canal escape ladders, cleats or fencing (district civil works).
- Powered or inflatable devices.
- Swiftwater rescue by trained teams entering the water.
- Certification to any life-saving or ladder standard at this TRL.

## Prior work

| Prior work | What it does | Gap for these users | Source |
| --- | --- | --- | --- |
| Fixed canal escape ladders (US Bureau of Reclamation) | Ladders set into concrete-lined canals at 750 ft intervals, plus cables and droplines upstream of structures | Fixed and spaced out; a person carried by the current may not reach one | [link](https://www.usbr.gov/tsc/techreferences/hydraulics_lab/pubs/REC/REC-ERC-71-36.pdf) |
| Shore Safety rescue ladder | Floating aluminium ladder of 3 or 4 m, 7 to 9 kg, hooked on a quay edge, type approved to AFS 2004:3 and EN 131 | Rigid and heavy; made for quays, not for throwing down a sloped canal wall | [link](https://shoresafety.se/en/products/components/rescue-ladder-type-approved/) |
| Rapid Rung swim ladder | Patented self-stowing strap-on swim ladder for boats, from $150 USD | Mounted on a hull, not thrown from a bank | [link](https://www.rapidrung.com/) |
| US3411166A inflatable boarding ladder and paddle | Buoyant ladder that hooks on a gunwale and doubles as a flotation aid (expired) | Boat boarding aid; needs inflation and a gunwale | [link](https://patents.google.com/patent/US3411166) |
| US4989691A inflatable boarding ladder and rescue device | Inflatable ladder with a ballasted lower end that sinks to form a step (lapsed 1995) | Boat-mounted and inflated; not thrown from land | [link](https://patents.google.com/patent/US4989691A/en) |
| Rescue throw bag | Throw line of about 15 m (50 ft) in a bag, about $24 USD | Needs a strong bystander to pull the person up a steep wall | [link](https://www.airhead.com/products/rescue-throw-bag) |

## Co-design

An irrigation district or canal authority with a safety programme, working with a local water-safety council or life-saving society, to define bank heights, flows and placement, and to run trials on a drained or low-flow canal reach. The first candidate to approach is the Kittitas Reclamation District in Washington State, whose canal safety page is cited above, with the Water Safety Council of Fresno County as the first candidate water-safety partner. Neither has been contacted; both are candidates, not partners (CNR-DDR-001, D13).

## Safety

> **Safety:** Canal rescue kills would-be rescuers. CanalRung exists so that the bystander stays on the bank: throw, anchor and call the emergency number; never enter the water. The ladder is rope equipment that a person's life depends on, and rope in moving water can trap a person or a limb, so a blunt-tip rescue knife is kept at the station. CanalRung is a research prototype published as an open engineering reference, not certified life-saving equipment, and it is not a flotation device.

## Questions answered at TRL 2 and TRL 3

All were decided on 2026-10-03 under Amish's pre-approval; the reasons are in CNR-DDR-001.

- **Bank heights, slopes and flows for the first version:** water up to 2.0 m below the coping on a 1.5:1 slope or 3.0 m on a vertical wall; currents to 2.0 m/s (D1). A partner district's data will confirm or change this.
- **Weighted to sink or floating:** both. A soft 0.5 kg weight hangs 280 mm below the bottom rung and the rungs float; the bottom three rungs carry the weight with a factor of 1.73 (D6).
- **Load standard:** rope to EN 1891 type A; rung and anchor targets as set in CNR-REQ-001 (R4, R6), to be proof-loaded with CalRig at TRL 4; no certification is claimed (D9).
- **Theft:** no lock, because a lock defeats the station; a numbered tamper tag on the latch shows when the box has been opened, and the partner district inspects on a set schedule (D11).
- **Fresno County figure of 35 canal drownings from 2005 to 2020:** not confirmed from a primary source, so it is not used in this repository.

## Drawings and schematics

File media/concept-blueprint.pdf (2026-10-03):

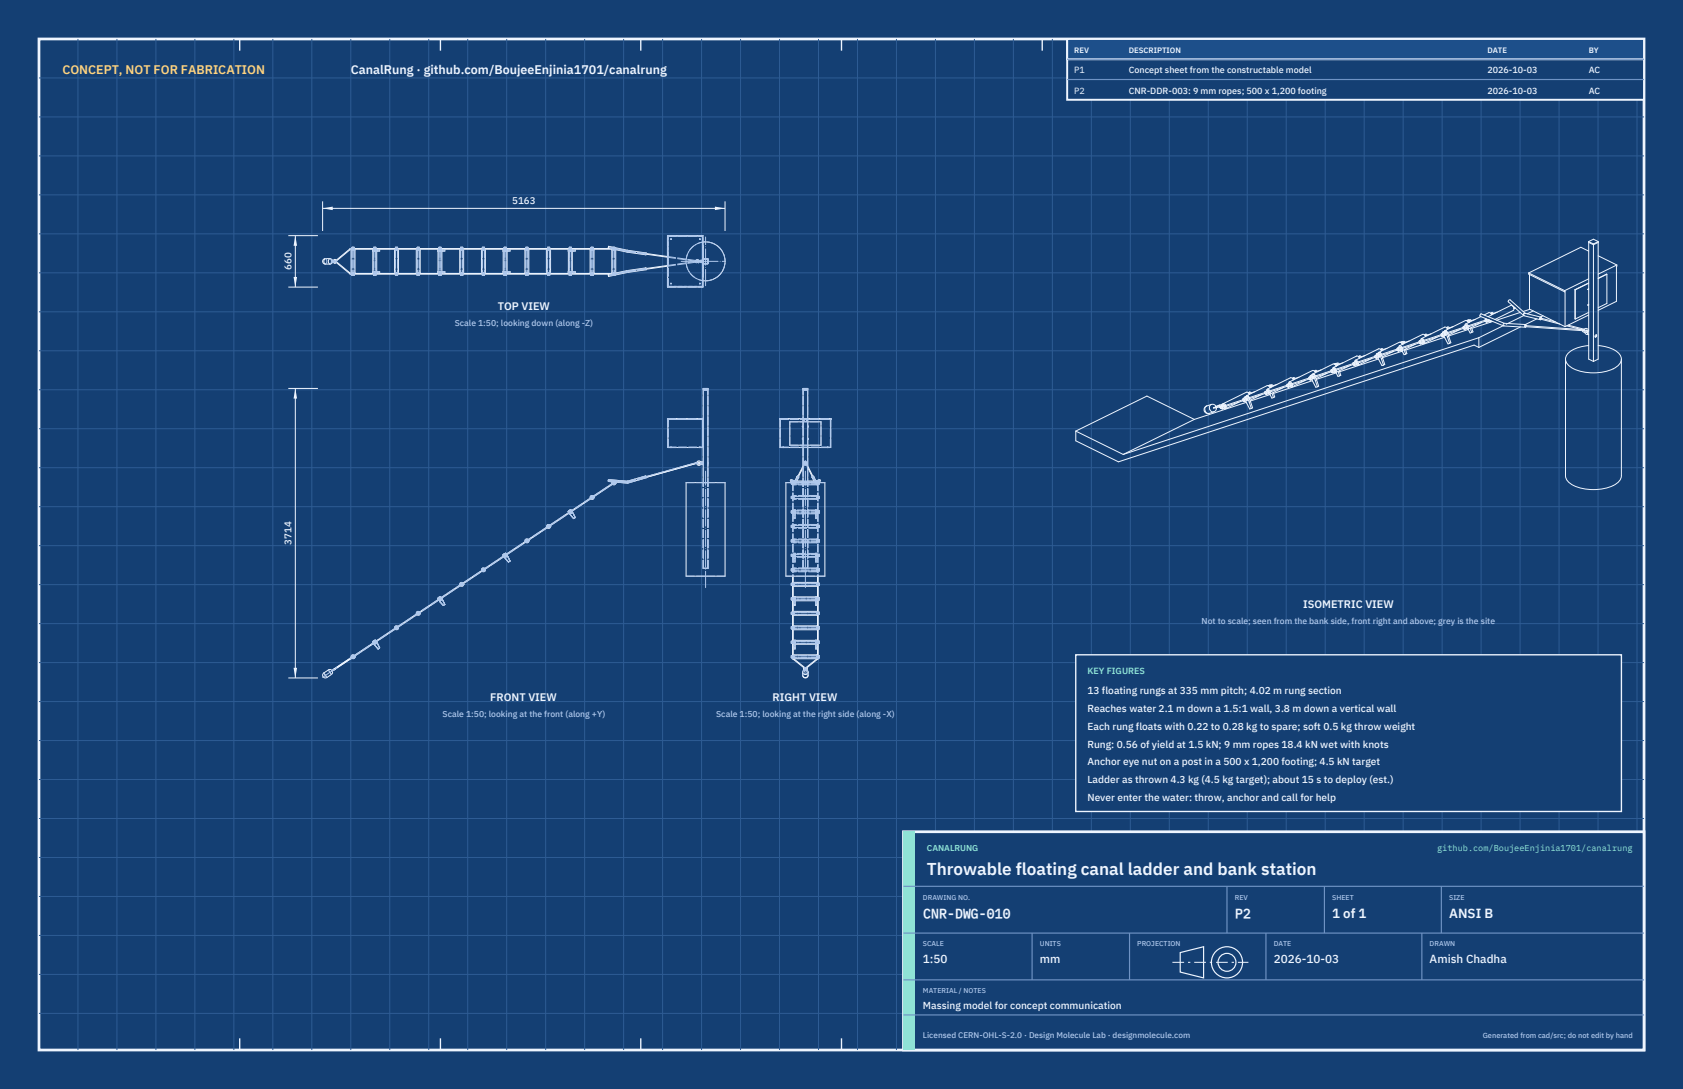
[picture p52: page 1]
CONCEPT, NOT FOR FABRICATION; CanalRung · github.com/BoujeeEnjinia1701/canalrung; FRONT VIEW; TOP VIEW; RIGHT VIEW; ISOMETRIC VIEW; REV; DESCRIPTION; DATE; Concept sheet from the constructable model; CNR-DDR-003: 9 mm ropes; 500 x 1,200 footing; CANALRUNG; github.com/BoujeeEnjinia1701/canalrung; DRAWING NO. CNR-DWG-010; REV P2; SHEET 1 of 1; SIZE ANSI B; SCALE 1:50; UNITS mm; PROJECTION; DRAWN Amish Chadha; Licensed CERN-OHL-S-2.0 · Design Molecule Lab · designmolecule.com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

Scale 1:50; looking down (along -Z)

Not to scale; seen from the bank side, front right and above; grey is the site

KEY FIGURES
13 floating rungs at 335 mm pitch; 4.02 m rung section
Reaches water 2.1 m down a 1.5:1 wall, 3.8 m down a vertical wall
Each rung floats with 0.22 to 0.28 kg to spare; soft 0.5 kg throw weight
Rung: 0.56 of yield at 1.5 kN; 9 mm ropes 18.4 kN wet with knots
Anchor eye nut on a post in a 500 x 1,200 footing; 4.5 kN target
Ladder as thrown 4.3 kg (4.5 kg target); about 15 s to deploy (est.)
Never enter the water: throw, anchor and call for help

Scale 1:50; looking at the front (along +Y)

Scale 1:50; looking at the right side (along -X)

Throwable floating canal ladder and bank station

MATERIAL / NOTES
Massing model for concept communication

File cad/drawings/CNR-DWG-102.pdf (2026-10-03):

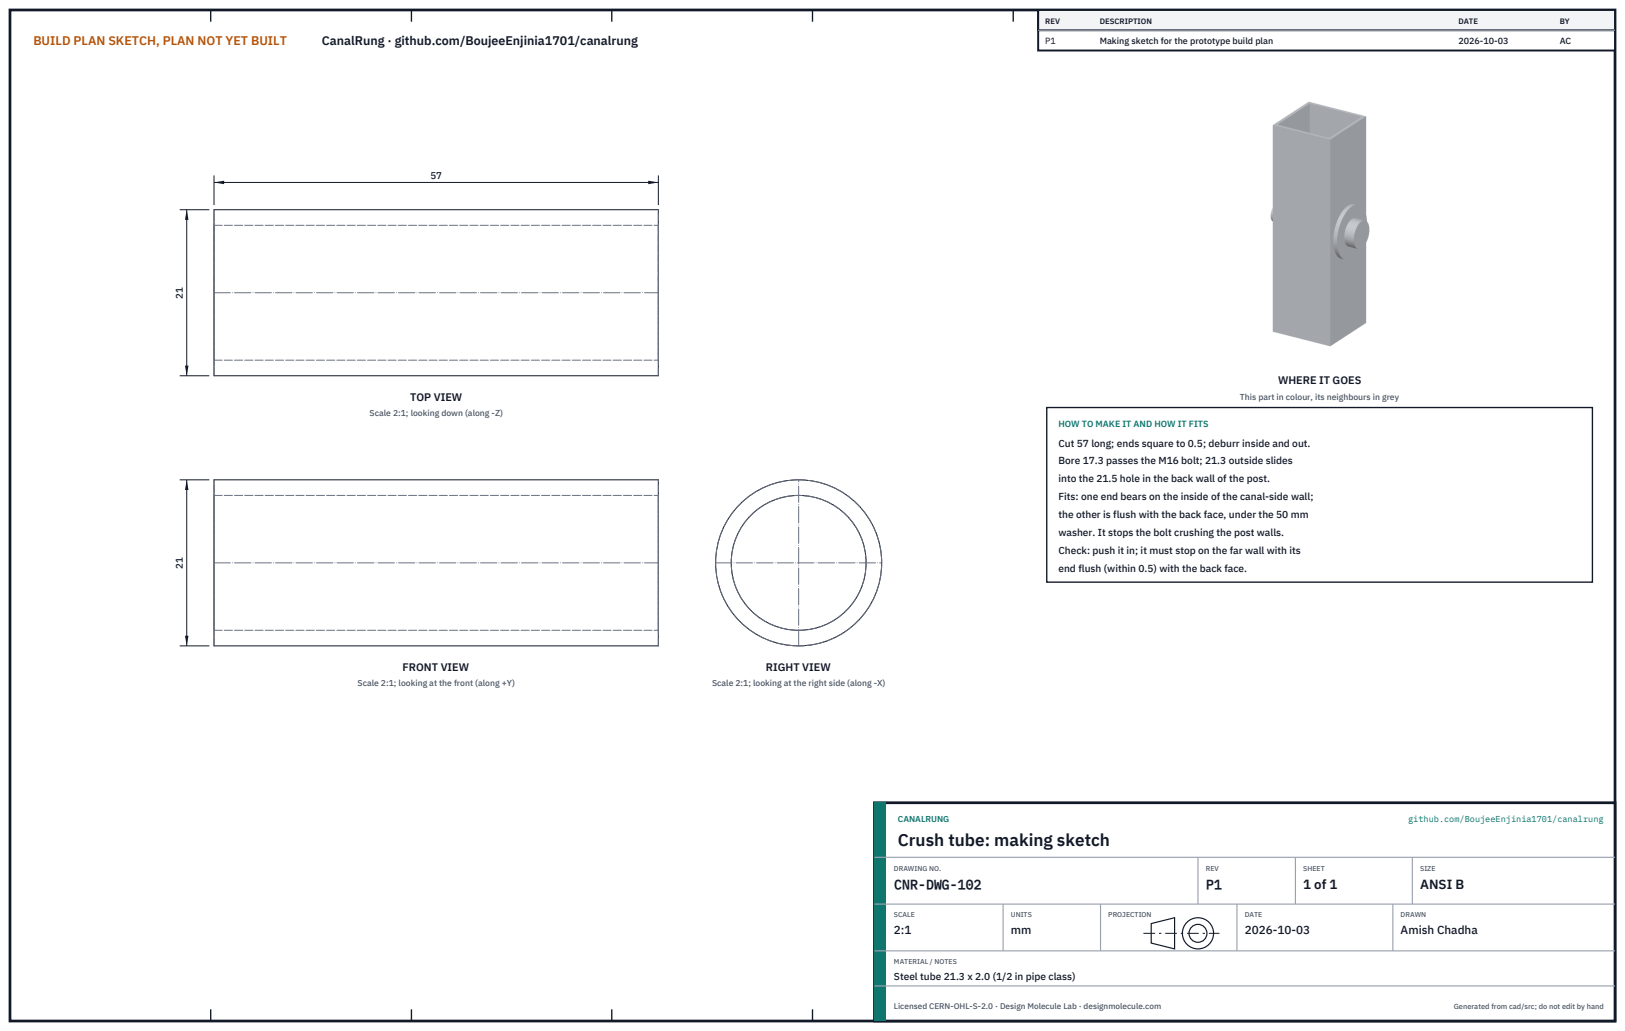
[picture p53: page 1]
BUILD PLAN SKETCH, PLAN NOT YET BUILT; CanalRung · github.com/BoujeeEnjinia1701/canalrung; FRONT VIEW; TOP VIEW; RIGHT VIEW; REV; DESCRIPTION; DATE; Making sketch for the prototype build plan; CANALRUNG; github.com/BoujeeEnjinia1701/canalrung; DRAWING NO. CNR-DWG-102; REV P1; SHEET 1 of 1; SIZE ANSI B; SCALE 2:1; UNITS mm; PROJECTION; DRAWN Amish Chadha; Licensed CERN-OHL-S-2.0 · Design Molecule Lab · designmolecule.com; Generated from cad/src; do not edit by hand

WHERE IT GOES

This part in colour, its neighbours in grey

Scale 2:1; looking down (along -Z)

HOW TO MAKE IT AND HOW IT FITS
Cut 57 long; ends square to 0.5; deburr inside and out.
Bore 17.3 passes the M16 bolt; 21.3 outside slides
into the 21.5 hole in the back wall of the post.
Fits: one end bears on the inside of the canal-side wall;
the other is flush with the back face, under the 50 mm
washer. It stops the bolt crushing the post walls.
Check: push it in; it must stop on the far wall with its
end flush (within 0.5) with the back face.

Scale 2:1; looking at the front (along +Y)

Scale 2:1; looking at the right side (along -X)

Crush tube: making sketch

MATERIAL / NOTES
Steel tube 21.3 x 2.0 (1/2 in pipe class)

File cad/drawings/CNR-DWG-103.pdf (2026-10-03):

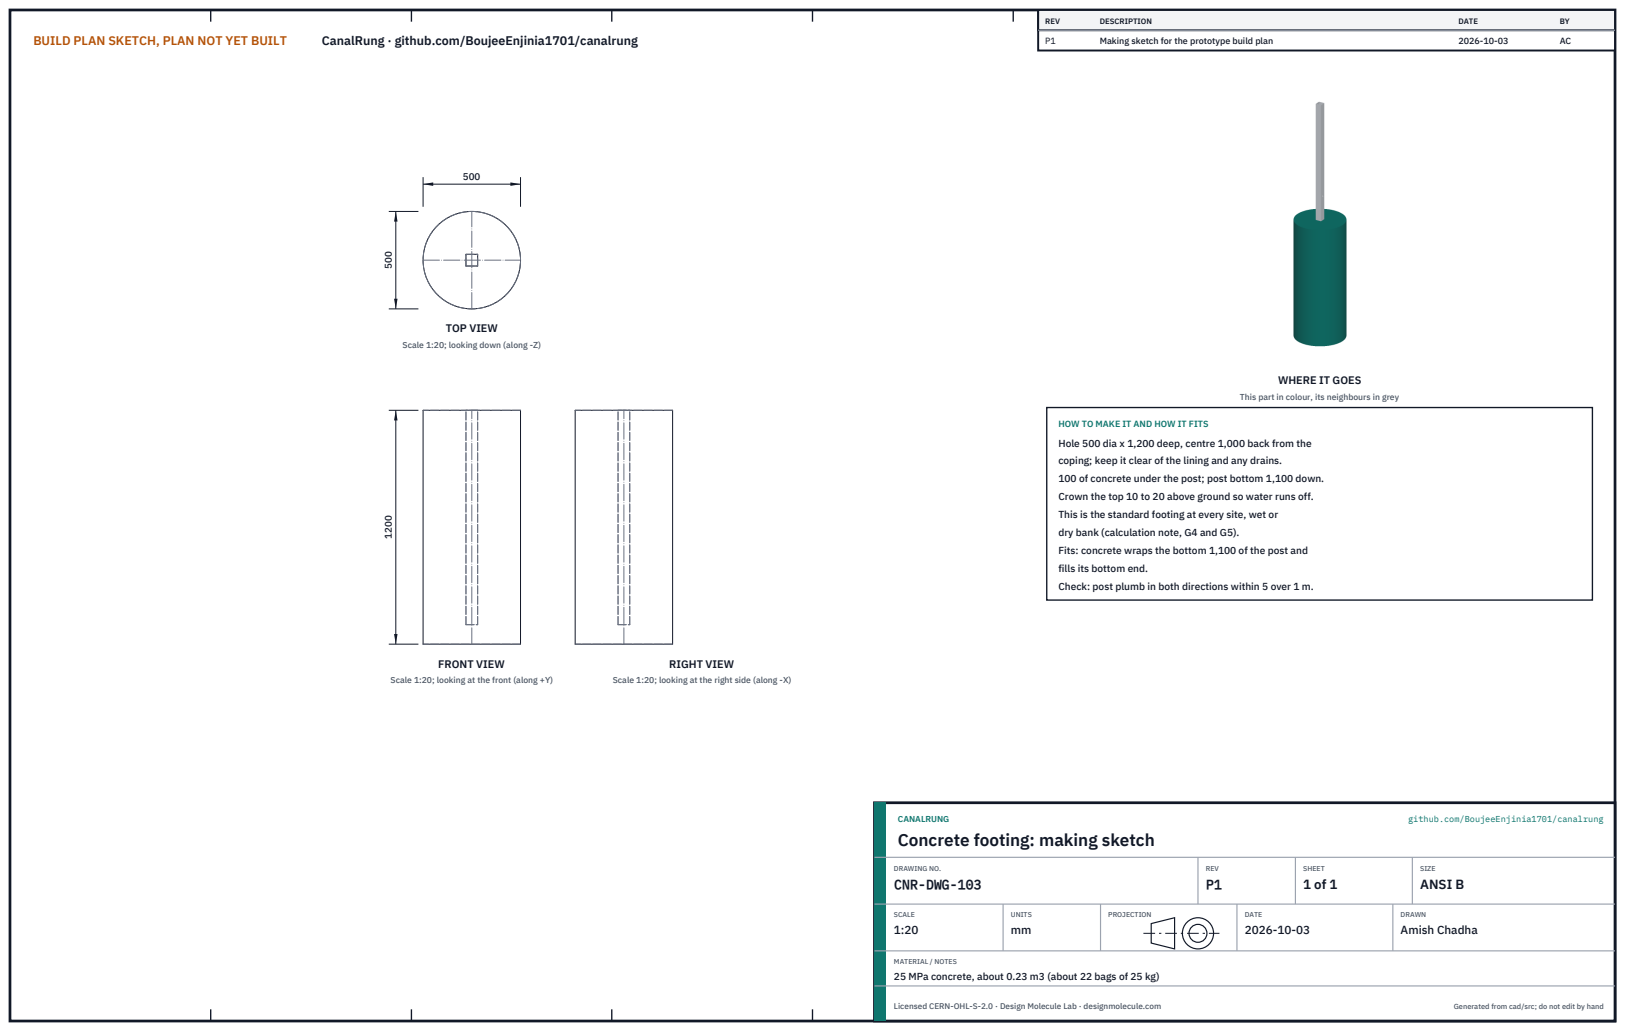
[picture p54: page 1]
BUILD PLAN SKETCH, PLAN NOT YET BUILT; CanalRung · github.com/BoujeeEnjinia1701/canalrung; FRONT VIEW; TOP VIEW; RIGHT VIEW; REV; DESCRIPTION; DATE; Making sketch for the prototype build plan; CANALRUNG; github.com/BoujeeEnjinia1701/canalrung; DRAWING NO. CNR-DWG-103; REV P1; SHEET 1 of 1; SIZE ANSI B; SCALE 1:20; UNITS mm; PROJECTION; DRAWN Amish Chadha; Licensed CERN-OHL-S-2.0 · Design Molecule Lab · designmolecule.com; Generated from cad/src; do not edit by hand

Scale 1:20; looking down (along -Z)

WHERE IT GOES

This part in colour, its neighbours in grey

HOW TO MAKE IT AND HOW IT FITS
Hole 500 dia x 1,200 deep, centre 1,000 back from the
coping; keep it clear of the lining and any drains.
100 of concrete under the post; post bottom 1,100 down.
Crown the top 10 to 20 above ground so water runs off.
This is the standard footing at every site, wet or
dry bank (calculation note, G4 and G5).
Fits: concrete wraps the bottom 1,100 of the post and
fills its bottom end.
Check: post plumb in both directions within 5 over 1 m.

Scale 1:20; looking at the front (along +Y)

Scale 1:20; looking at the right side (along -X)

Concrete footing: making sketch

MATERIAL / NOTES
25 MPa concrete, about 0.23 m3 (about 22 bags of 25 kg)

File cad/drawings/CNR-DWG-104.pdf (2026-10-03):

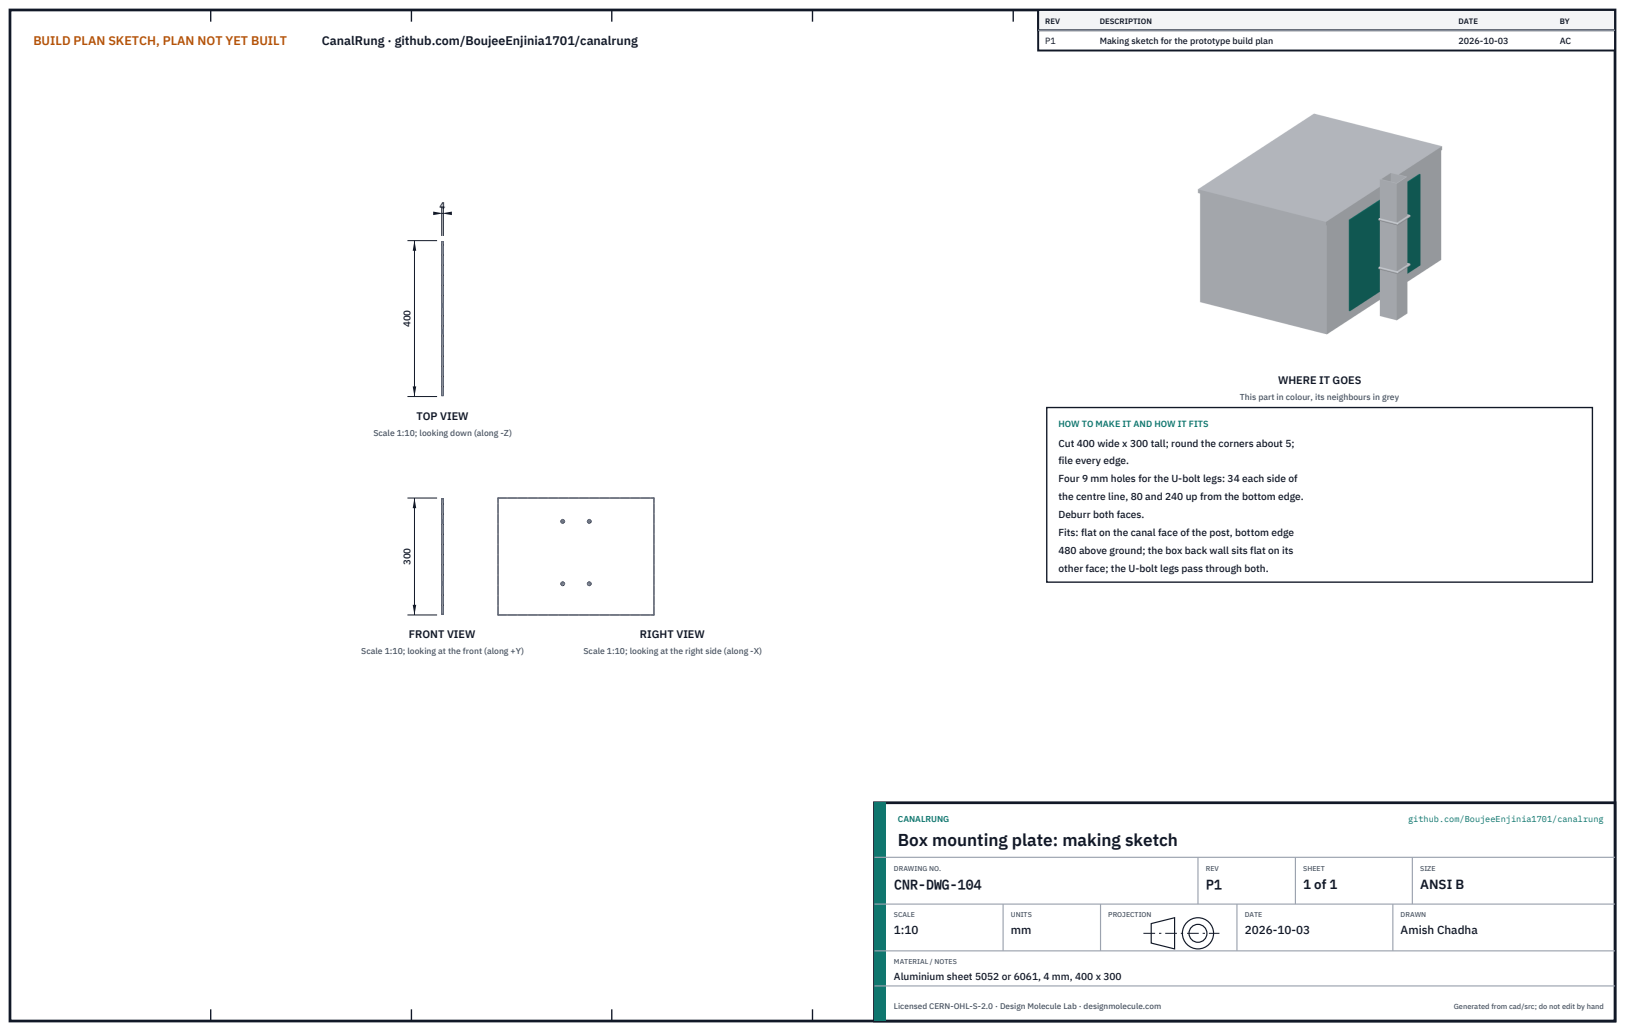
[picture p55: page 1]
BUILD PLAN SKETCH, PLAN NOT YET BUILT; CanalRung · github.com/BoujeeEnjinia1701/canalrung; FRONT VIEW; TOP VIEW; RIGHT VIEW; REV; DESCRIPTION; DATE; Making sketch for the prototype build plan; CANALRUNG; github.com/BoujeeEnjinia1701/canalrung; DRAWING NO. CNR-DWG-104; REV P1; SHEET 1 of 1; SIZE ANSI B; SCALE 1:10; UNITS mm; PROJECTION; DRAWN Amish Chadha; Licensed CERN-OHL-S-2.0 · Design Molecule Lab · designmolecule.com; Generated from cad/src; do not edit by hand

WHERE IT GOES

This part in colour, its neighbours in grey

Scale 1:10; looking down (along -Z)

HOW TO MAKE IT AND HOW IT FITS
Cut 400 wide x 300 tall; round the corners about 5;
file every edge.
Four 9 mm holes for the U-bolt legs: 34 each side of
the centre line, 80 and 240 up from the bottom edge.
Deburr both faces.
Fits: flat on the canal face of the post, bottom edge
480 above ground; the box back wall sits flat on its
other face; the U-bolt legs pass through both.

Scale 1:10; looking at the front (along +Y)

Scale 1:10; looking at the right side (along -X)

Box mounting plate: making sketch

MATERIAL / NOTES
Aluminium sheet 5052 or 6061, 4 mm, 400 x 300

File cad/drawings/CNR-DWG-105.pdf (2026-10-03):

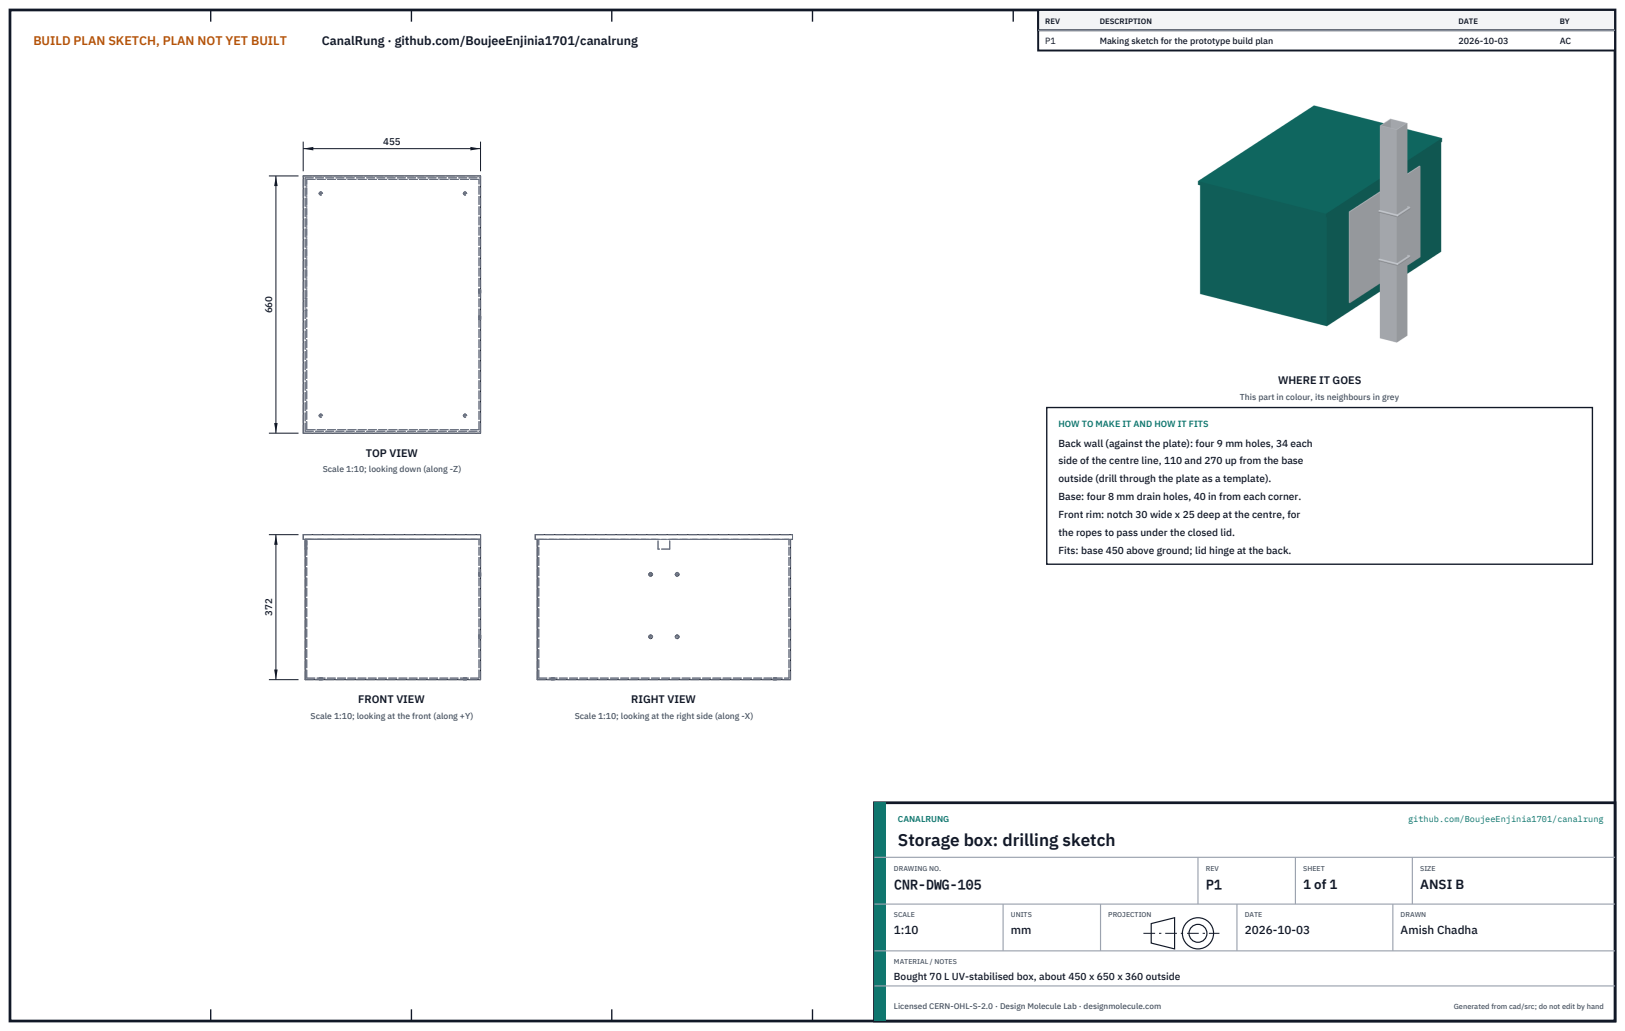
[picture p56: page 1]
BUILD PLAN SKETCH, PLAN NOT YET BUILT; CanalRung · github.com/BoujeeEnjinia1701/canalrung; FRONT VIEW; TOP VIEW; RIGHT VIEW; REV; DESCRIPTION; DATE; Making sketch for the prototype build plan; CANALRUNG; github.com/BoujeeEnjinia1701/canalrung; DRAWING NO. CNR-DWG-105; REV P1; SHEET 1 of 1; SIZE ANSI B; SCALE 1:10; UNITS mm; PROJECTION; DRAWN Amish Chadha; Licensed CERN-OHL-S-2.0 · Design Molecule Lab · designmolecule.com; Generated from cad/src; do not edit by hand

WHERE IT GOES

This part in colour, its neighbours in grey

HOW TO MAKE IT AND HOW IT FITS
Back wall (against the plate): four 9 mm holes, 34 each
side of the centre line, 110 and 270 up from the base
outside (drill through the plate as a template).
Base: four 8 mm drain holes, 40 in from each corner.
Front rim: notch 30 wide x 25 deep at the centre, for
the ropes to pass under the closed lid.
Fits: base 450 above ground; lid hinge at the back.

Scale 1:10; looking down (along -Z)

Scale 1:10; looking at the front (along +Y)

Scale 1:10; looking at the right side (along -X)

Storage box: drilling sketch

MATERIAL / NOTES
Bought 70 L UV-stabilised box, about 450 x 650 x 360 outside

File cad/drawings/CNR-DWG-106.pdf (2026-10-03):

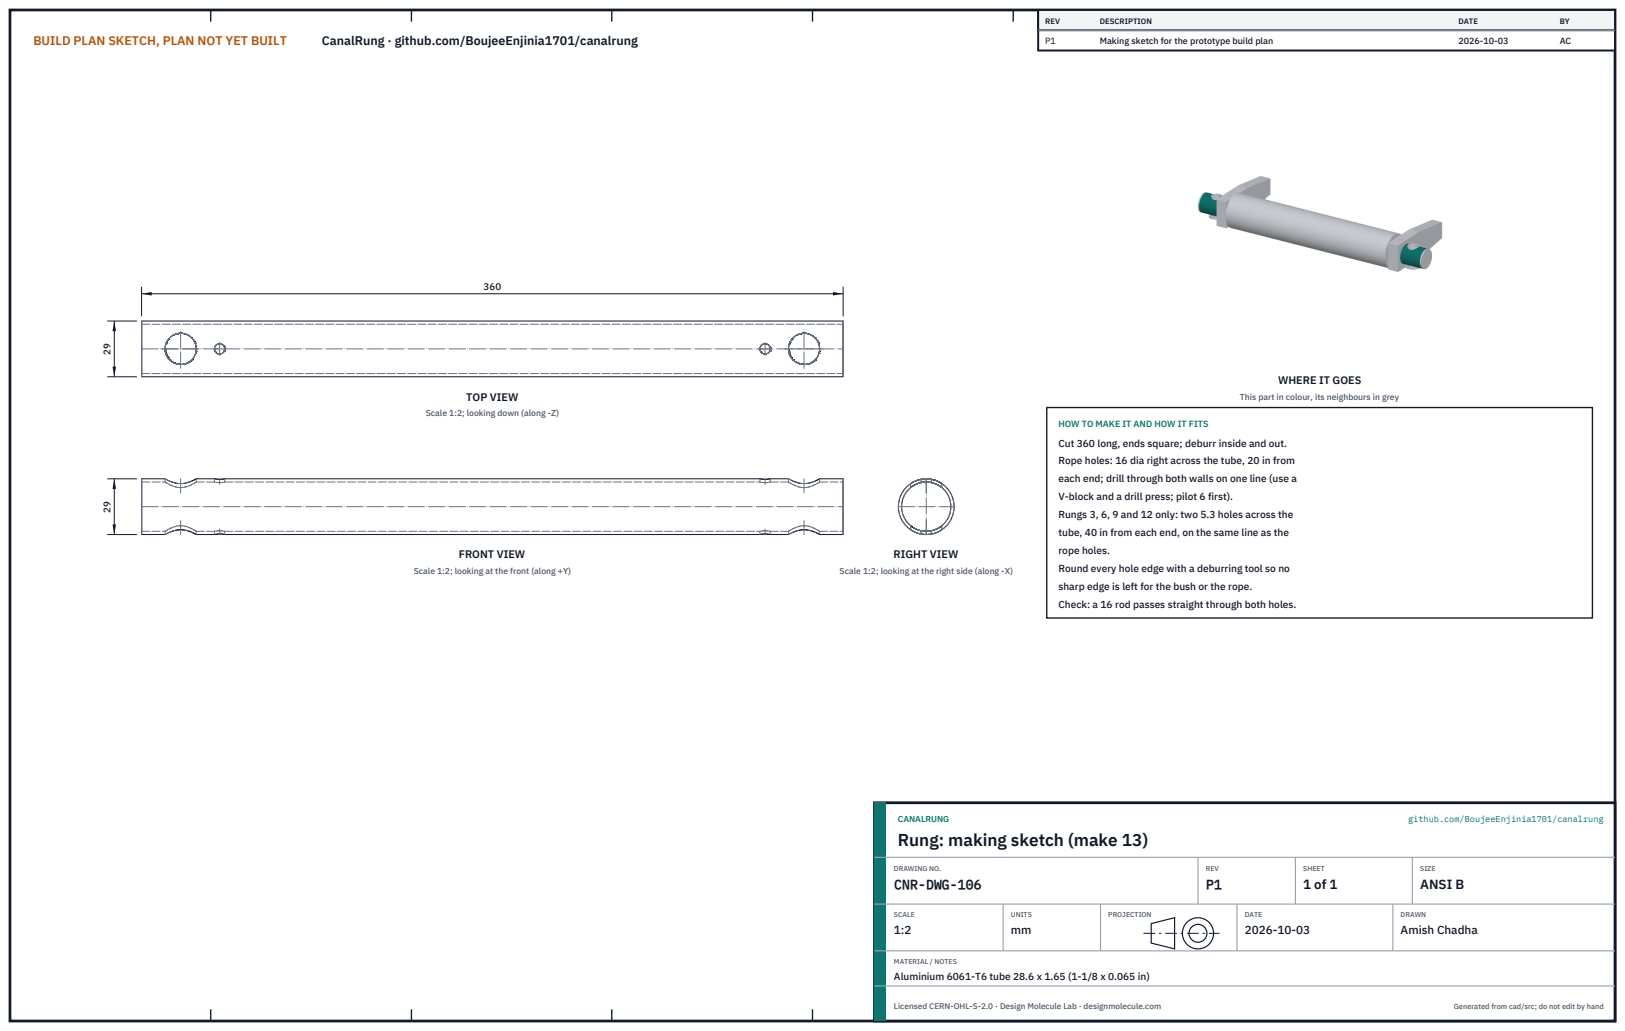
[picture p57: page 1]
BUILD PLAN SKETCH, PLAN NOT YET BUILT; CanalRung · github.com/BoujeeEnjinia1701/canalrung; FRONT VIEW; TOP VIEW; RIGHT VIEW; REV; DESCRIPTION; DATE; Making sketch for the prototype build plan; CANALRUNG; github.com/BoujeeEnjinia1701/canalrung; DRAWING NO. CNR-DWG-106; REV P1; SHEET 1 of 1; SIZE ANSI B; SCALE 1:2; UNITS mm; PROJECTION; DRAWN Amish Chadha; Licensed CERN-OHL-S-2.0 · Design Molecule Lab · designmolecule.com; Generated from cad/src; do not edit by hand

WHERE IT GOES

This part in colour, its neighbours in grey

Scale 1:2; looking down (along -Z)

HOW TO MAKE IT AND HOW IT FITS
Cut 360 long, ends square; deburr inside and out.
Rope holes: 16 dia right across the tube, 20 in from
each end; drill through both walls on one line (use a
V-block and a drill press; pilot 6 first).
Rungs 3, 6, 9 and 12 only: two 5.3 holes across the
tube, 40 in from each end, on the same line as the
rope holes.
Round every hole edge with a deburring tool so no
sharp edge is left for the bush or the rope.
Check: a 16 rod passes straight through both holes.

Scale 1:2; looking at the front (along +Y)

Scale 1:2; looking at the right side (along -X)

Rung: making sketch (make 13)

MATERIAL / NOTES
Aluminium 6061-T6 tube 28.6 x 1.65 (1-1/8 x 0.065 in)

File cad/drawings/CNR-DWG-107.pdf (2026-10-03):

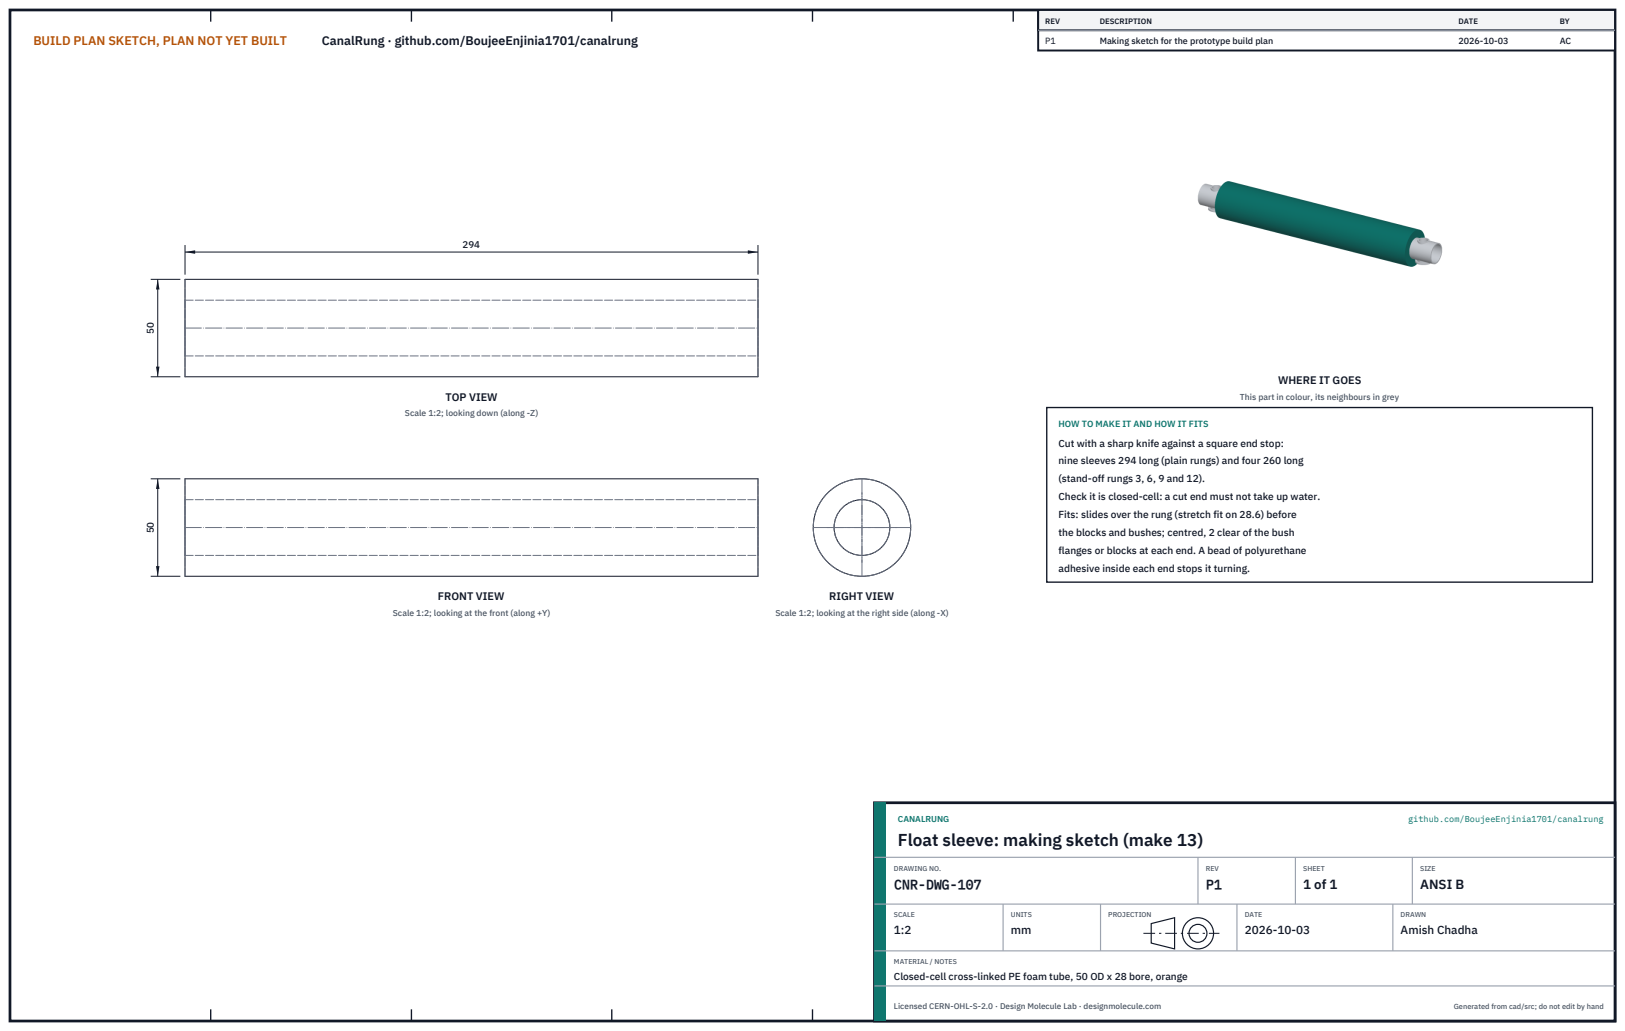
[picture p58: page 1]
BUILD PLAN SKETCH, PLAN NOT YET BUILT; CanalRung · github.com/BoujeeEnjinia1701/canalrung; FRONT VIEW; TOP VIEW; RIGHT VIEW; REV; DESCRIPTION; DATE; Making sketch for the prototype build plan; CANALRUNG; github.com/BoujeeEnjinia1701/canalrung; DRAWING NO. CNR-DWG-107; REV P1; SHEET 1 of 1; SIZE ANSI B; SCALE 1:2; UNITS mm; PROJECTION; DRAWN Amish Chadha; Licensed CERN-OHL-S-2.0 · Design Molecule Lab · designmolecule.com; Generated from cad/src; do not edit by hand

WHERE IT GOES

This part in colour, its neighbours in grey

Scale 1:2; looking down (along -Z)

HOW TO MAKE IT AND HOW IT FITS
Cut with a sharp knife against a square end stop:
nine sleeves 294 long (plain rungs) and four 260 long
(stand-off rungs 3, 6, 9 and 12).
Check it is closed-cell: a cut end must not take up water.
Fits: slides over the rung (stretch fit on 28.6) before
the blocks and bushes; centred, 2 clear of the bush
flanges or blocks at each end. A bead of polyurethane
adhesive inside each end stops it turning.

Scale 1:2; looking at the front (along +Y)

Scale 1:2; looking at the right side (along -X)

Float sleeve: making sketch (make 13)

MATERIAL / NOTES
Closed-cell cross-linked PE foam tube, 50 OD x 28 bore, orange

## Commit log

2026-10-03 CanalRung at TRL 3: constructable design (kit 1.7.0)
    Problem, concept and requirements; sizing calculations; CAD model, STEP and STL; general arrangement drawing; bill of materials; build plan with making sketches, joint close-ups and step pictures; design decisions register (all decided under Amish's 2026-10-03 pre-approval); TRL 2 and TRL 3 review; photoreal renders and storefront card. Private until Amish opens it.
    [bom.csv, canalrung-assembly.step, canalrung-ladder.step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]
2026-10-03 Carry Amish's 2026-10-03 requirement decisions into the design
    Amish chose option A on each requirement decision ("1A 2A 3A 4A 5A 6A 7A 8A 9A 10A 11A"). CampBreak: primed foot valve, pre-coupled suction hose and a drilled 30 s gather (R9 now 3.2 min at 100 m, me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
    [bom.csv, canalrung-assembly.step, canalrung-ladder.step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]
2026-11-09 Kit 1.9.1 upgrade: pipeline documents and detailed CAD for every option
    STEM check with fixes under the standing instruction and an independent
    review, concept options scored against the user requirements, URS, PRS,
    RTM, REG, FEA, RSK, MKT, PLN and DDR, every option modelled at D3 with
    cad/fidelity.json passing, and the concept options picture rendered with
    Blender Cycles on Amish's Mac. Concept choices stay proposed, awaiting
    Amish.
    Claude-Session: https://claude.ai/code/session_01LppsZSzPTJWTBAV5wh1Goq

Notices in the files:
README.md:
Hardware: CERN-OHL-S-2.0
